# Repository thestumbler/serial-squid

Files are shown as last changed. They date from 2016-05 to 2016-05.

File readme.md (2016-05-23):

## Synopsis

The Serial Squid is a serial communications hub, useful for the development and testing of embedded systems projects. It can be operated stand-alone or remotely. True to its namesake, the Serial Squid has eight arms, two tentacles, and a round body. The I/O ports are found on the appendages, and the user interface and other supporting circuitry is found on the head and main body.

More information about the project can be found on my blog and project pages.

* [thestumbler](http://thestumbler.github.io)
* [theserialsquid](http://thestumbler.github.io/serial-squid/)

## Project File Organization

#### Key Files of Interest

* Bill of Materials:  docs/squid-bom.ods / .xlsx
* Block Diagram: docs/squid-block-diag.odg / .pdf
* LPC1769 Pinout Chart:  docs/squid-pinouts.ods / .xlsx
* Mechanical Drawing: mech/pcb_squid.dwg
* Parts Datasheets: parts/
* KiCAD Schematics, PCB files: sch/

## Status

* BOM is 98% completed.  All parts can be procured from DigiKey.  One problem has been sourcing a SMT 2x3 shrouded box header.

* Schematics 98% completed.  A few minor changes to be made, have been postponed until preliminary routing of the board is completed.  I want to see how much free room is remaining before deciding on the final few schematic changes.

* PCB first draft parts placement completed.  Routing will start after one more pass over the placement.

## github TODO

Add OpenSCAD 3D source code, which gives an fairly realistic mock-up of the final assembly.  It all works, but I need to re-organize some modules.  For example, many non-header parts reside in the header module.  Also, I need to sort out how to make a fork of another project, since I built my OpenSCAD library of parts upon a pre-existing library.

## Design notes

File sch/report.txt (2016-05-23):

Info: Reading netlist file "/files/proj/squid/serial-squid/sch/squid.net".

Info: Using references to match components and footprints.

Info: Checking netlist component footprint "C1:/56F75D50/57000D03:Capacitors_SMD:C_0805_HandSoldering".

Adding new component "C1:/56F75D50/57000D03" footprint "Capacitors_SMD:C_0805_HandSoldering".

Changing component "C1:/56F75D50/57000D03" pin "1" net name from "" to "Net-(C1-Pad1)".

Changing component "C1:/56F75D50/57000D03" pin "2" net name from "" to "Net-(C1-Pad2)".

Info: Checking netlist component footprint "C2:/56F75D50/57000D0A:Capacitors_SMD:C_0805_HandSoldering".

Adding new component "C2:/56F75D50/57000D0A" footprint "Capacitors_SMD:C_0805_HandSoldering".

Changing component "C2:/56F75D50/57000D0A" pin "1" net name from "" to "Net-(C2-Pad1)".

Changing component "C2:/56F75D50/57000D0A" pin "2" net name from "" to "Net-(C2-Pad2)".

Info: Checking netlist component footprint "C3:/56F75D50/570015F4:Capacitors_SMD:C_0805_HandSoldering".

Adding new component "C3:/56F75D50/570015F4" footprint "Capacitors_SMD:C_0805_HandSoldering".

Changing component "C3:/56F75D50/570015F4" pin "1" net name from "" to "GND".

Changing component "C3:/56F75D50/570015F4" pin "2" net name from "" to "Net-(C3-Pad2)".

Info: Checking netlist component footprint "C4:/56F75D50/570015FB:Capacitors_SMD:C_0805_HandSoldering".

Adding new component "C4:/56F75D50/570015FB" footprint "Capacitors_SMD:C_0805_HandSoldering".

Changing component "C4:/56F75D50/570015FB" pin "1" net name from "" to "GND".

Changing component "C4:/56F75D50/570015FB" pin "2" net name from "" to "Net-(C4-Pad2)".

Info: Checking netlist component footprint "C5:/56FDE856/5700692F:Capacitors_SMD:C_0805_HandSoldering".

Adding new component "C5:/56FDE856/5700692F" footprint "Capacitors_SMD:C_0805_HandSoldering".

Changing component "C5:/56FDE856/5700692F" pin "1" net name from "" to "Net-(C5-Pad1)".

Changing component "C5:/56FDE856/5700692F" pin "2" net name from "" to "Net-(C5-Pad2)".

Info: Checking netlist component footprint "C6:/56FDE856/57006936:Capacitors_SMD:C_0805_HandSoldering".

Adding new component "C6:/56FDE856/57006936" footprint "Capacitors_SMD:C_0805_HandSoldering".

Changing component "C6:/56FDE856/57006936" pin "1" net name from "" to "Net-(C6-Pad1)".

Changing component "C6:/56FDE856/57006936" pin "2" net name from "" to "Net-(C6-Pad2)".

Info: Checking netlist component footprint "C7:/56FDE856/5718DB03:Capacitors_SMD:C_0805_HandSoldering".

Adding new component "C7:/56FDE856/5718DB03" footprint "Capacitors_SMD:C_0805_HandSoldering".

Changing component "C7:/56FDE856/5718DB03" pin "1" net name from "" to "Net-(C7-Pad1)".

Changing component "C7:/56FDE856/5718DB03" pin "2" net name from "" to "GND".

Info: Checking netlist component footprint "C8:/56FDE856/570062FE:Capacitors_SMD:C_0805_HandSoldering".

Adding new component "C8:/56FDE856/570062FE" footprint "Capacitors_SMD:C_0805_HandSoldering".

Changing component "C8:/56FDE856/570062FE" pin "1" net name from "" to "GND".

Changing component "C8:/56FDE856/570062FE" pin "2" net name from "" to "Net-(C8-Pad2)".

Info: Checking netlist component footprint "C9:/56FDE856/57006305:Capacitors_SMD:C_0805_HandSoldering".

Adding new component "C9:/56FDE856/57006305" footprint "Capacitors_SMD:C_0805_HandSoldering".

Changing component "C9:/56FDE856/57006305" pin "1" net name from "" to "GND".

Changing component "C9:/56FDE856/57006305" pin "2" net name from "" to "Net-(C9-Pad2)".

Info: Checking netlist component footprint "C10:/56F72C60/571BCD2E:Capacitors_SMD:C_0805_HandSoldering".

Adding new component "C10:/56F72C60/571BCD2E" footprint "Capacitors_SMD:C_0805_HandSoldering".

Changing component "C10:/56F72C60/571BCD2E" pin "1" net name from "" to "Net-(C10-Pad1)".

Changing component "C10:/56F72C60/571BCD2E" pin "2" net name from "" to "GND".

Info: Checking netlist component footprint "C11:/56F72C60/571BCE58:Capacitors_SMD:C_0805_HandSoldering".

Adding new component "C11:/56F72C60/571BCE58" footprint "Capacitors_SMD:C_0805_HandSoldering".

Changing component "C11:/56F72C60/571BCE58" pin "1" net name from "" to "Net-(C11-Pad1)".

Changing component "C11:/56F72C60/571BCE58" pin "2" net name from "" to "GND".

Info: Checking netlist component footprint "C12:/56F72C60/571BD55E:Capacitors_SMD:C_0805_HandSoldering".

Adding new component "C12:/56F72C60/571BD55E" footprint "Capacitors_SMD:C_0805_HandSoldering".

Changing component "C12:/56F72C60/571BD55E" pin "1" net name from "" to "Net-(C12-Pad1)".

Changing component "C12:/56F72C60/571BD55E" pin "2" net name from "" to "GND".

Info: Checking netlist component footprint "C13:/56F72C60/571BD503:Capacitors_SMD:C_0805_HandSoldering".

Adding new component "C13:/56F72C60/571BD503" footprint "Capacitors_SMD:C_0805_HandSoldering".

Changing component "C13:/56F72C60/571BD503" pin "1" net name from "" to "Net-(C13-Pad1)".

Changing component "C13:/56F72C60/571BD503" pin "2" net name from "" to "GND".

Info: Checking netlist component footprint "C14:/56F72E3F/572241B0:Capacitors_SMD:C_0805_HandSoldering".

Adding new component "C14:/56F72E3F/572241B0" footprint "Capacitors_SMD:C_0805_HandSoldering".

Changing component "C14:/56F72E3F/572241B0" pin "1" net name from "" to "GND".

Changing component "C14:/56F72E3F/572241B0" pin "2" net name from "" to "Net-(C14-Pad2)".

Info: Checking netlist component footprint "C15:/56F72E3F/56FFF748:Capacitors_SMD:C_0805_HandSoldering".

Adding new component "C15:/56F72E3F/56FFF748" footprint "Capacitors_SMD:C_0805_HandSoldering".

Changing component "C15:/56F72E3F/56FFF748" pin "1" net name from "" to "Net-(C15-Pad1)".

Changing component "C15:/56F72E3F/56FFF748" pin "2" net name from "" to "GND".

Info: Checking netlist component footprint "C16:/56F72E3F/56FFFB31:Capacitors_SMD:C_0805_HandSoldering".

Adding new component "C16:/56F72E3F/56FFFB31" footprint "Capacitors_SMD:C_0805_HandSoldering".

Changing component "C16:/56F72E3F/56FFFB31" pin "1" net name from "" to "Net-(C16-Pad1)".

Changing component "C16:/56F72E3F/56FFFB31" pin "2" net name from "" to "GND".

Info: Checking netlist component footprint "C17:/56F72E3F/56FFFBD1:Capacitors_SMD:C_0805_HandSoldering".

Adding new component "C17:/56F72E3F/56FFFBD1" footprint "Capacitors_SMD:C_0805_HandSoldering".

Changing component "C17:/56F72E3F/56FFFBD1" pin "1" net name from "" to "Net-(C17-Pad1)".

Changing component "C17:/56F72E3F/56FFFBD1" pin "2" net name from "" to "Net-(C17-Pad2)".

Info: Checking netlist component footprint "C18:/56F72E3F/56FFFFD9:Capacitors_SMD:C_0805_HandSoldering".

Adding new component "C18:/56F72E3F/56FFFFD9" footprint "Capacitors_SMD:C_0805_HandSoldering".

Changing component "C18:/56F72E3F/56FFFFD9" pin "1" net name from "" to "Net-(C18-Pad1)".

Changing component "C18:/56F72E3F/56FFFFD9" pin "2" net name from "" to "Net-(C18-Pad2)".

Info: Checking netlist component footprint "C19:/571465DD/5714AEFB:Capacitors_SMD:C_0805_HandSoldering".

Adding new component "C19:/571465DD/5714AEFB" footprint "Capacitors_SMD:C_0805_HandSoldering".

Changing component "C19:/571465DD/5714AEFB" pin "1" net name from "" to "/COM0/~RESET".

Changing component "C19:/571465DD/5714AEFB" pin "2" net name from "" to "GND".

Info: Checking netlist component footprint "C20:/571465DD/5728B651:Capacitors_SMD:C_0805_HandSoldering".

Adding new component "C20:/571465DD/5728B651" footprint "Capacitors_SMD:C_0805_HandSoldering".

Changing component "C20:/571465DD/5728B651" pin "1" net name from "" to "/PIC-SQPROG/DISP_CONTR".

Changing component "C20:/571465DD/5728B651" pin "2" net name from "" to "GND".

Info: Checking netlist component footprint "C21:/57192609/57197EB6:Capacitors_SMD:C_0805_HandSoldering".

Adding new component "C21:/57192609/57197EB6" footprint "Capacitors_SMD:C_0805_HandSoldering".

Changing component "C21:/57192609/57197EB6" pin "1" net name from "" to "+5V".

Changing component "C21:/57192609/57197EB6" pin "2" net name from "" to "GND".

Info: Checking netlist component footprint "C22:/57192609/571988D2:Capacitors_Tantalum_SMD:TantalC_SizeB_EIA-3528_HandSoldering".

Adding new component "C22:/57192609/571988D2" footprint "Capacitors_Tantalum_SMD:TantalC_SizeB_EIA-3528_HandSoldering".

Changing component "C22:/57192609/571988D2" pin "2" net name from "" to "GND".

Changing component "C22:/57192609/571988D2" pin "1" net name from "" to "/CPU/USB_PWRD".

Info: Checking netlist component footprint "C23:/57192609/57173862:Capacitors_SMD:C_0805_HandSoldering".

Adding new component "C23:/57192609/57173862" footprint "Capacitors_SMD:C_0805_HandSoldering".

Changing component "C23:/57192609/57173862" pin "1" net name from "" to "+3V3".

Changing component "C23:/57192609/57173862" pin "2" net name from "" to "GND".

Info: Checking netlist component footprint "C24:/57192609/57173869:Capacitors_SMD:C_0805_HandSoldering".

Adding new component "C24:/57192609/57173869" footprint "Capacitors_SMD:C_0805_HandSoldering".

Changing component "C24:/57192609/57173869" pin "1" net name from "" to "+3V3".

Changing component "C24:/57192609/57173869" pin "2" net name from "" to "GND".

Info: Checking netlist component footprint "C25:/57192609/57173811:Capacitors_SMD:C_0805_HandSoldering".

Adding new component "C25:/57192609/57173811" footprint "Capacitors_SMD:C_0805_HandSoldering".

Changing component "C25:/57192609/57173811" pin "1" net name from "" to "Net-(C25-Pad1)".

Changing component "C25:/57192609/57173811" pin "2" net name from "" to "GND".

Info: Checking netlist component footprint "C26:/57192609/57173818:Capacitors_SMD:C_0805_HandSoldering".

Adding new component "C26:/57192609/57173818" footprint "Capacitors_SMD:C_0805_HandSoldering".

Changing component "C26:/57192609/57173818" pin "1" net name from "" to "Net-(C26-Pad1)".

Changing component "C26:/57192609/57173818" pin "2" net name from "" to "GND".

Info: Checking netlist component footprint "C27:/57161414/57165C09:Capacitors_SMD:C_0805_HandSoldering".

Adding new component "C27:/57161414/57165C09" footprint "Capacitors_SMD:C_0805_HandSoldering".

Changing component "C27:/57161414/57165C09" pin "1" net name from "" to "+5V".

Changing component "C27:/57161414/57165C09" pin "2" net name from "" to "GND".

Info: Checking netlist component footprint "C28:/57161414/57165C6D:Capacitors_Tantalum_SMD:TantalC_SizeB_EIA-3528_HandSoldering".

Adding new component "C28:/57161414/57165C6D" footprint "Capacitors_Tantalum_SMD:TantalC_SizeB_EIA-3528_HandSoldering".

Changing component "C28:/57161414/57165C6D" pin "2" net name from "" to "GND".

Changing component "C28:/57161414/57165C6D" pin "1" net name from "" to "+3V3".

Info: Checking netlist component footprint "C29:/56FDE856/57210437:Capacitors_SMD:C_0805_HandSoldering".

Adding new component "C29:/56FDE856/57210437" footprint "Capacitors_SMD:C_0805_HandSoldering".

Changing component "C29:/56FDE856/57210437" pin "1" net name from "" to "+5V".

Changing component "C29:/56FDE856/57210437" pin "2" net name from "" to "GND".

Info: Checking netlist component footprint "C30:/56FDE856/57210846:Capacitors_SMD:C_0805_HandSoldering".

Adding new component "C30:/56FDE856/57210846" footprint "Capacitors_SMD:C_0805_HandSoldering".

Changing component "C30:/56FDE856/57210846" pin "1" net name from "" to "GND".

Changing component "C30:/56FDE856/57210846" pin "2" net name from "" to "+5V".

Info: Checking netlist component footprint "C31:/56FDE856/57210F86:Capacitors_SMD:C_0805_HandSoldering".

Adding new component "C31:/56FDE856/57210F86" footprint "Capacitors_SMD:C_0805_HandSoldering".

Changing component "C31:/56FDE856/57210F86" pin "1" net name from "" to "GND".

Changing component "C31:/56FDE856/57210F86" pin "2" net name from "" to "+3V3".

Info: Checking netlist component footprint "C32:/56FF0341/57212123:Capacitors_SMD:C_0805_HandSoldering".

Adding new component "C32:/56FF0341/57212123" footprint "Capacitors_SMD:C_0805_HandSoldering".

Changing component "C32:/56FF0341/57212123" pin "1" net name from "" to "+5V".

Changing component "C32:/56FF0341/57212123" pin "2" net name from "" to "GND".

Info: Checking netlist component footprint "C33:/56FF0341/57212388:Capacitors_SMD:C_0805_HandSoldering".

Adding new component "C33:/56FF0341/57212388" footprint "Capacitors_SMD:C_0805_HandSoldering".

Changing component "C33:/56FF0341/57212388" pin "1" net name from "" to "+5V".

Changing component "C33:/56FF0341/57212388" pin "2" net name from "" to "GND".

Info: Checking netlist component footprint "C34:/56FF0341/57212470:Capacitors_SMD:C_0805_HandSoldering".

Adding new component "C34:/56FF0341/57212470" footprint "Capacitors_SMD:C_0805_HandSoldering".

Changing component "C34:/56FF0341/57212470" pin "1" net name from "" to "+5V".

Changing component "C34:/56FF0341/57212470" pin "2" net name from "" to "GND".

Info: Checking netlist component footprint "C35:/56FF0E05/5721A32F:Capacitors_SMD:C_0805_HandSoldering".

Adding new component "C35:/56FF0E05/5721A32F" footprint "Capacitors_SMD:C_0805_HandSoldering".

Changing component "C35:/56FF0E05/5721A32F" pin "1" net name from "" to "+5V".

Changing component "C35:/56FF0E05/5721A32F" pin "2" net name from "" to "GND".

Info: Checking netlist component footprint "C36:/56FF0E05/5721A366:Capacitors_SMD:C_0805_HandSoldering".

Adding new component "C36:/56FF0E05/5721A366" footprint "Capacitors_SMD:C_0805_HandSoldering".

Changing component "C36:/56FF0E05/5721A366" pin "1" net name from "" to "+5V".

Changing component "C36:/56FF0E05/5721A366" pin "2" net name from "" to "GND".

Info: Checking netlist component footprint "C37:/56FF0E05/5721A392:Capacitors_SMD:C_0805_HandSoldering".

Adding new component "C37:/56FF0E05/5721A392" footprint "Capacitors_SMD:C_0805_HandSoldering".

Changing component "C37:/56FF0E05/5721A392" pin "1" net name from "" to "+5V".

Changing component "C37:/56FF0E05/5721A392" pin "2" net name from "" to "GND".

Info: Checking netlist component footprint "C38:/56FF0E05/5721A3C7:Capacitors_SMD:C_0805_HandSoldering".

Adding new component "C38:/56FF0E05/5721A3C7" footprint "Capacitors_SMD:C_0805_HandSoldering".

Changing component "C38:/56FF0E05/5721A3C7" pin "1" net name from "" to "+5V".

Changing component "C38:/56FF0E05/5721A3C7" pin "2" net name from "" to "GND".

Info: Checking netlist component footprint "C39:/56F72C60/5721D036:Capacitors_SMD:C_0805_HandSoldering".

Adding new component "C39:/56F72C60/5721D036" footprint "Capacitors_SMD:C_0805_HandSoldering".

Changing component "C39:/56F72C60/5721D036" pin "1" net name from "" to "+3V3".

Changing component "C39:/56F72C60/5721D036" pin "2" net name from "" to "GND".

Info: Checking netlist component footprint "C40:/56F72C60/5721CD49:Capacitors_SMD:C_0805_HandSoldering".

Adding new component "C40:/56F72C60/5721CD49" footprint "Capacitors_SMD:C_0805_HandSoldering".

Changing component "C40:/56F72C60/5721CD49" pin "1" net name from "" to "+3V3".

Changing component "C40:/56F72C60/5721CD49" pin "2" net name from "" to "GND".

Info: Checking netlist component footprint "C41:/56F72C60/5721CE5A:Capacitors_SMD:C_0805_HandSoldering".

Adding new component "C41:/56F72C60/5721CE5A" footprint "Capacitors_SMD:C_0805_HandSoldering".

Changing component "C41:/56F72C60/5721CE5A" pin "1" net name from "" to "+3V3".

Changing component "C41:/56F72C60/5721CE5A" pin "2" net name from "" to "GND".

Info: Checking netlist component footprint "C42:/56F72C60/5721D002:Capacitors_SMD:C_0805_HandSoldering".

Adding new component "C42:/56F72C60/5721D002" footprint "Capacitors_SMD:C_0805_HandSoldering".

Changing component "C42:/56F72C60/5721D002" pin "1" net name from "" to "+3V3".

Changing component "C42:/56F72C60/5721D002" pin "2" net name from "" to "GND".

Info: Checking netlist component footprint "C43:/56F72C60/5721D008:Capacitors_SMD:C_0805_HandSoldering".

Adding new component "C43:/56F72C60/5721D008" footprint "Capacitors_SMD:C_0805_HandSoldering".

Changing component "C43:/56F72C60/5721D008" pin "1" net name from "" to "+3V3".

Changing component "C43:/56F72C60/5721D008" pin "2" net name from "" to "GND".

Info: Checking netlist component footprint "C44:/56F72C60/5721CEAA:Capacitors_SMD:C_0805_HandSoldering".

Adding new component "C44:/56F72C60/5721CEAA" footprint "Capacitors_SMD:C_0805_HandSoldering".

Changing component "C44:/56F72C60/5721CEAA" pin "1" net name from "" to "+3V3".

Changing component "C44:/56F72C60/5721CEAA" pin "2" net name from "" to "GND".

Info: Checking netlist component footprint "C45:/56F72C60/5721CEF7:Capacitors_SMD:C_0805_HandSoldering".

Adding new component "C45:/56F72C60/5721CEF7" footprint "Capacitors_SMD:C_0805_HandSoldering".

Changing component "C45:/56F72C60/5721CEF7" pin "1" net name from "" to "+3V3".

Changing component "C45:/56F72C60/5721CEF7" pin "2" net name from "" to "GND".

Info: Checking netlist component footprint "C46:/56F72E3F/572095A0:Capacitors_SMD:C_0805_HandSoldering".

Adding new component "C46:/56F72E3F/572095A0" footprint "Capacitors_SMD:C_0805_HandSoldering".

Changing component "C46:/56F72E3F/572095A0" pin "1" net name from "" to "GND".

Changing component "C46:/56F72E3F/572095A0" pin "2" net name from "" to "+3V3".

Info: Checking netlist component footprint "C47:/56F72E3F/5720B4DE:Capacitors_SMD:C_0805_HandSoldering".

Adding new component "C47:/56F72E3F/5720B4DE" footprint "Capacitors_SMD:C_0805_HandSoldering".

Changing component "C47:/56F72E3F/5720B4DE" pin "1" net name from "" to "+5V".

Changing component "C47:/56F72E3F/5720B4DE" pin "2" net name from "" to "GND".

Info: Checking netlist component footprint "C48:/56F72E3F/5720AC9D:Capacitors_SMD:C_0805_HandSoldering".

Adding new component "C48:/56F72E3F/5720AC9D" footprint "Capacitors_SMD:C_0805_HandSoldering".

Changing component "C48:/56F72E3F/5720AC9D" pin "1" net name from "" to "+3V3".

Changing component "C48:/56F72E3F/5720AC9D" pin "2" net name from "" to "GND".

Info: Checking netlist component footprint "C49:/56F72E3F/57209711:Capacitors_SMD:C_0805_HandSoldering".

Adding new component "C49:/56F72E3F/57209711" footprint "Capacitors_SMD:C_0805_HandSoldering".

Changing component "C49:/56F72E3F/57209711" pin "1" net name from "" to "+5V".

Changing component "C49:/56F72E3F/57209711" pin "2" net name from "" to "GND".

Info: Checking netlist component footprint "C50:/56F72E3F/5720BC9E:Capacitors_SMD:C_0805_HandSoldering".

Adding new component "C50:/56F72E3F/5720BC9E" footprint "Capacitors_SMD:C_0805_HandSoldering".

Changing component "C50:/56F72E3F/5720BC9E" pin "1" net name from "" to "+5V".

Changing component "C50:/56F72E3F/5720BC9E" pin "2" net name from "" to "GND".

Info: Checking netlist component footprint "C51:/5712FB0E/5721C098:Capacitors_SMD:C_0805_HandSoldering".

Adding new component "C51:/5712FB0E/5721C098" footprint "Capacitors_SMD:C_0805_HandSoldering".

Changing component "C51:/5712FB0E/5721C098" pin "1" net name from "" to "GND".

Changing component "C51:/5712FB0E/5721C098" pin "2" net name from "" to "+5V".

Info: Checking netlist component footprint "C52:/571465DD/5721B483:Capacitors_SMD:C_0805_HandSoldering".

Adding new component "C52:/571465DD/5721B483" footprint "Capacitors_SMD:C_0805_HandSoldering".

Changing component "C52:/571465DD/5721B483" pin "1" net name from "" to "+3V3".

Changing component "C52:/571465DD/5721B483" pin "2" net name from "" to "GND".

Info: Checking netlist component footprint "C53:/571465DD/5721B59B:Capacitors_SMD:C_0805_HandSoldering".

Adding new component "C53:/571465DD/5721B59B" footprint "Capacitors_SMD:C_0805_HandSoldering".

Changing component "C53:/571465DD/5721B59B" pin "1" net name from "" to "GND".

Changing component "C53:/571465DD/5721B59B" pin "2" net name from "" to "+3V3".

Info: Checking netlist component footprint "C54:/57192609/57217AD8:Capacitors_SMD:C_0805_HandSoldering".

Adding new component "C54:/57192609/57217AD8" footprint "Capacitors_SMD:C_0805_HandSoldering".

Changing component "C54:/57192609/57217AD8" pin "1" net name from "" to "+5V".

Changing component "C54:/57192609/57217AD8" pin "2" net name from "" to "GND".

Info: Checking netlist component footprint "C55:/57192609/57217F5F:Capacitors_SMD:C_0805_HandSoldering".

Adding new component "C55:/57192609/57217F5F" footprint "Capacitors_SMD:C_0805_HandSoldering".

Changing component "C55:/57192609/57217F5F" pin "1" net name from "" to "+3V3".

Changing component "C55:/57192609/57217F5F" pin "2" net name from "" to "GND".

Info: Checking netlist component footprint "C56:/57192609/57214563:Capacitors_SMD:C_0805_HandSoldering".

Adding new component "C56:/57192609/57214563" footprint "Capacitors_SMD:C_0805_HandSoldering".

Changing component "C56:/57192609/57214563" pin "1" net name from "" to "GND".

Changing component "C56:/57192609/57214563" pin "2" net name from "" to "+3V3".

Info: Checking netlist component footprint "C57:/57192609/57214490:Capacitors_SMD:C_0805_HandSoldering".

Adding new component "C57:/57192609/57214490" footprint "Capacitors_SMD:C_0805_HandSoldering".

Changing component "C57:/57192609/57214490" pin "1" net name from "" to "GND".

Changing component "C57:/57192609/57214490" pin "2" net name from "" to "+3V3".

Info: Checking netlist component footprint "C58:/57192609/57214386:Capacitors_SMD:C_0805_HandSoldering".

Adding new component "C58:/57192609/57214386" footprint "Capacitors_SMD:C_0805_HandSoldering".

Changing component "C58:/57192609/57214386" pin "1" net name from "" to "+3V3".

Changing component "C58:/57192609/57214386" pin "2" net name from "" to "GND".

Info: Checking netlist component footprint "C59:/57192609/57216182:Capacitors_Tantalum_SMD:TantalC_SizeB_EIA-3528_HandSoldering".

Adding new component "C59:/57192609/57216182" footprint "Capacitors_Tantalum_SMD:TantalC_SizeB_EIA-3528_HandSoldering".

Changing component "C59:/57192609/57216182" pin "2" net name from "" to "GND".

Changing component "C59:/57192609/57216182" pin "1" net name from "" to "+3V3".

Info: Checking netlist component footprint "C60:/57161414/57218DED:Capacitors_SMD:C_0805_HandSoldering".

Adding new component "C60:/57161414/57218DED" footprint "Capacitors_SMD:C_0805_HandSoldering".

Changing component "C60:/57161414/57218DED" pin "1" net name from "" to "+3V3".

Changing component "C60:/57161414/57218DED" pin "2" net name from "" to "GND".

Info: Checking netlist component footprint "C61:/57161414/57218E9D:Capacitors_SMD:C_0805_HandSoldering".

Adding new component "C61:/57161414/57218E9D" footprint "Capacitors_SMD:C_0805_HandSoldering".

Changing component "C61:/57161414/57218E9D" pin "1" net name from "" to "+3V3".

Changing component "C61:/57161414/57218E9D" pin "2" net name from "" to "GND".

Info: Checking netlist component footprint "C62:/57161414/572197D1:Capacitors_SMD:C_0805_HandSoldering".

Adding new component "C62:/57161414/572197D1" footprint "Capacitors_SMD:C_0805_HandSoldering".

Changing component "C62:/57161414/572197D1" pin "1" net name from "" to "+3V3".

Changing component "C62:/57161414/572197D1" pin "2" net name from "" to "GND".

Info: Checking netlist component footprint "C63:/57161414/572190C5:Capacitors_SMD:C_0805_HandSoldering".

Adding new component "C63:/57161414/572190C5" footprint "Capacitors_SMD:C_0805_HandSoldering".

Changing component "C63:/57161414/572190C5" pin "1" net name from "" to "+3V3".

Changing component "C63:/57161414/572190C5" pin "2" net name from "" to "GND".

Info: Checking netlist component footprint "C64:/56F75D50/5720CD6F:Capacitors_SMD:C_0805_HandSoldering".

Adding new component "C64:/56F75D50/5720CD6F" footprint "Capacitors_SMD:C_0805_HandSoldering".

Changing component "C64:/56F75D50/5720CD6F" pin "1" net name from "" to "+5V".

Changing component "C64:/56F75D50/5720CD6F" pin "2" net name from "" to "GND".

Info: Checking netlist component footprint "C65:/56F75D50/5720D5A9:Capacitors_SMD:C_0805_HandSoldering".

Adding new component "C65:/56F75D50/5720D5A9" footprint "Capacitors_SMD:C_0805_HandSoldering".

Changing component "C65:/56F75D50/5720D5A9" pin "1" net name from "" to "+5V".

Changing component "C65:/56F75D50/5720D5A9" pin "2" net name from "" to "GND".

Info: Checking netlist component footprint "C66:/56F75D50/5720D78D:Capacitors_SMD:C_0805_HandSoldering".

Adding new component "C66:/56F75D50/5720D78D" footprint "Capacitors_SMD:C_0805_HandSoldering".

Changing component "C66:/56F75D50/5720D78D" pin "1" net name from "" to "+5V".

Changing component "C66:/56F75D50/5720D78D" pin "2" net name from "" to "GND".

Info: Checking netlist component footprint "C67:/56F75D50/5720DC86:Capacitors_SMD:C_0805_HandSoldering".

Adding new component "C67:/56F75D50/5720DC86" footprint "Capacitors_SMD:C_0805_HandSoldering".

Changing component "C67:/56F75D50/5720DC86" pin "1" net name from "" to "+5V".

Changing component "C67:/56F75D50/5720DC86" pin "2" net name from "" to "GND".

Info: Checking netlist component footprint "C68:/56F75D50/5720E242:Capacitors_SMD:C_0805_HandSoldering".

Adding new component "C68:/56F75D50/5720E242" footprint "Capacitors_SMD:C_0805_HandSoldering".

Changing component "C68:/56F75D50/5720E242" pin "1" net name from "" to "+5V".

Changing component "C68:/56F75D50/5720E242" pin "2" net name from "" to "GND".

Info: Checking netlist component footprint "C69:/56F75D50/5720F5D6:Capacitors_SMD:C_0805_HandSoldering".

Adding new component "C69:/56F75D50/5720F5D6" footprint "Capacitors_SMD:C_0805_HandSoldering".

Changing component "C69:/56F75D50/5720F5D6" pin "1" net name from "" to "GND".

Changing component "C69:/56F75D50/5720F5D6" pin "2" net name from "" to "+3V3".

Info: Checking netlist component footprint "D1:/56F75D50/571D7237:Resistors_SMD:R_0805_HandSoldering".

Adding new component "D1:/56F75D50/571D7237" footprint "Resistors_SMD:R_0805_HandSoldering".

Changing component "D1:/56F75D50/571D7237" pin "1" net name from "" to "Net-(D1-Pad1)".

Changing component "D1:/56F75D50/571D7237" pin "2" net name from "" to "+5V".

Info: Checking netlist component footprint "D2:/56F75D50/571D724E:Resistors_SMD:R_0805_HandSoldering".

Adding new component "D2:/56F75D50/571D724E" footprint "Resistors_SMD:R_0805_HandSoldering".

Changing component "D2:/56F75D50/571D724E" pin "1" net name from "" to "Net-(D2-Pad1)".

Changing component "D2:/56F75D50/571D724E" pin "2" net name from "" to "+3V3".

Info: Checking netlist component footprint "D3:/56F75D50/571BE395:Resistors_SMD:R_0805_HandSoldering".

Adding new component "D3:/56F75D50/571BE395" footprint "Resistors_SMD:R_0805_HandSoldering".

Changing component "D3:/56F75D50/571BE395" pin "1" net name from "" to "GND".

Changing component "D3:/56F75D50/571BE395" pin "2" net name from "" to "Net-(D3-Pad2)".

Info: Checking netlist component footprint "D4:/56F75D50/571BCE1E:Resistors_SMD:R_0805_HandSoldering".

Adding new component "D4:/56F75D50/571BCE1E" footprint "Resistors_SMD:R_0805_HandSoldering".

Changing component "D4:/56F75D50/571BCE1E" pin "1" net name from "" to "GND".

Changing component "D4:/56F75D50/571BCE1E" pin "2" net name from "" to "Net-(D4-Pad2)".

Info: Checking netlist component footprint "D5:/56F75D50/571C2958:Resistors_SMD:R_0805_HandSoldering".

Adding new component "D5:/56F75D50/571C2958" footprint "Resistors_SMD:R_0805_HandSoldering".

Changing component "D5:/56F75D50/571C2958" pin "1" net name from "" to "GND".

Changing component "D5:/56F75D50/571C2958" pin "2" net name from "" to "Net-(D5-Pad2)".

Info: Checking netlist component footprint "D6:/56FDE856/571D23F6:Resistors_SMD:R_0805_HandSoldering".

Adding new component "D6:/56FDE856/571D23F6" footprint "Resistors_SMD:R_0805_HandSoldering".

Changing component "D6:/56FDE856/571D23F6" pin "1" net name from "" to "Net-(D6-Pad1)".

Changing component "D6:/56FDE856/571D23F6" pin "2" net name from "" to "+5V".

Info: Checking netlist component footprint "D7:/56FDE856/571D24A9:Resistors_SMD:R_0805_HandSoldering".

Adding new component "D7:/56FDE856/571D24A9" footprint "Resistors_SMD:R_0805_HandSoldering".

Changing component "D7:/56FDE856/571D24A9" pin "1" net name from "" to "Net-(D7-Pad1)".

Changing component "D7:/56FDE856/571D24A9" pin "2" net name from "" to "+3V3".

Info: Checking netlist component footprint "D8:/56FDE856/571CBE6D:Resistors_SMD:R_0805_HandSoldering".

Adding new component "D8:/56FDE856/571CBE6D" footprint "Resistors_SMD:R_0805_HandSoldering".

Changing component "D8:/56FDE856/571CBE6D" pin "1" net name from "" to "GND".

Changing component "D8:/56FDE856/571CBE6D" pin "2" net name from "" to "Net-(D8-Pad2)".

Info: Checking netlist component footprint "D9:/56FF0341/57200FDD:Resistors_SMD:R_0805_HandSoldering".

Adding new component "D9:/56FF0341/57200FDD" footprint "Resistors_SMD:R_0805_HandSoldering".

Changing component "D9:/56FF0341/57200FDD" pin "1" net name from "" to "GND".

Changing component "D9:/56FF0341/57200FDD" pin "2" net name from "" to "Net-(D9-Pad2)".

Info: Checking netlist component footprint "D10:/56FF0341/571F26BF:Resistors_SMD:R_0805_HandSoldering".

Adding new component "D10:/56FF0341/571F26BF" footprint "Resistors_SMD:R_0805_HandSoldering".

Changing component "D10:/56FF0341/571F26BF" pin "1" net name from "" to "Net-(D10-Pad1)".

Changing component "D10:/56FF0341/571F26BF" pin "2" net name from "" to "+5V".

Info: Checking netlist component footprint "D11:/56FF0341/571F26D3:Resistors_SMD:R_0805_HandSoldering".

Adding new component "D11:/56FF0341/571F26D3" footprint "Resistors_SMD:R_0805_HandSoldering".

Changing component "D11:/56FF0341/571F26D3" pin "1" net name from "" to "Net-(D11-Pad1)".

Changing component "D11:/56FF0341/571F26D3" pin "2" net name from "" to "+3V3".

Info: Checking netlist component footprint "D12:/56FF0341/571F3167:Resistors_SMD:R_0805_HandSoldering".

Adding new component "D12:/56FF0341/571F3167" footprint "Resistors_SMD:R_0805_HandSoldering".

Changing component "D12:/56FF0341/571F3167" pin "1" net name from "" to "Net-(D12-Pad1)".

Changing component "D12:/56FF0341/571F3167" pin "2" net name from "" to "+5V".

Info: Checking netlist component footprint "D13:/56FF0341/571F317B:Resistors_SMD:R_0805_HandSoldering".

Adding new component "D13:/56FF0341/571F317B" footprint "Resistors_SMD:R_0805_HandSoldering".

Changing component "D13:/56FF0341/571F317B" pin "1" net name from "" to "Net-(D13-Pad1)".

Changing component "D13:/56FF0341/571F317B" pin "2" net name from "" to "+3V3".

Info: Checking netlist component footprint "D14:/56FF0341/571E0EA0:Resistors_SMD:R_0805_HandSoldering".

Adding new component "D14:/56FF0341/571E0EA0" footprint "Resistors_SMD:R_0805_HandSoldering".

Changing component "D14:/56FF0341/571E0EA0" pin "1" net name from "" to "Net-(D14-Pad1)".

Changing component "D14:/56FF0341/571E0EA0" pin "2" net name from "" to "+5V".

Info: Checking netlist component footprint "D15:/56FF0341/571E0EB7:Resistors_SMD:R_0805_HandSoldering".

Adding new component "D15:/56FF0341/571E0EB7" footprint "Resistors_SMD:R_0805_HandSoldering".

Changing component "D15:/56FF0341/571E0EB7" pin "1" net name from "" to "Net-(D15-Pad1)".

Changing component "D15:/56FF0341/571E0EB7" pin "2" net name from "" to "+3V3".

Info: Checking netlist component footprint "D16:/56FF0341/571E5DA8:Resistors_SMD:R_0805_HandSoldering".

Adding new component "D16:/56FF0341/571E5DA8" footprint "Resistors_SMD:R_0805_HandSoldering".

Changing component "D16:/56FF0341/571E5DA8" pin "1" net name from "" to "GND".

Changing component "D16:/56FF0341/571E5DA8" pin "2" net name from "" to "Net-(D16-Pad2)".

Info: Checking netlist component footprint "D17:/56FF0341/571E59EC:Resistors_SMD:R_0805_HandSoldering".

Adding new component "D17:/56FF0341/571E59EC" footprint "Resistors_SMD:R_0805_HandSoldering".

Changing component "D17:/56FF0341/571E59EC" pin "1" net name from "" to "GND".

Changing component "D17:/56FF0341/571E59EC" pin "2" net name from "" to "Net-(D17-Pad2)".

Info: Checking netlist component footprint "D18:/56F72E3F/5722C710:Resistors_SMD:R_0805_HandSoldering".

Adding new component "D18:/56F72E3F/5722C710" footprint "Resistors_SMD:R_0805_HandSoldering".

Changing component "D18:/56F72E3F/5722C710" pin "1" net name from "" to "GND".

Changing component "D18:/56F72E3F/5722C710" pin "2" net name from "" to "Net-(D18-Pad2)".

Info: Checking netlist component footprint "D19:/56F72E3F/5723CEBE:Resistors_SMD:R_0805_HandSoldering".

Adding new component "D19:/56F72E3F/5723CEBE" footprint "Resistors_SMD:R_0805_HandSoldering".

Changing component "D19:/56F72E3F/5723CEBE" pin "1" net name from "" to "GND".

Changing component "D19:/56F72E3F/5723CEBE" pin "2" net name from "" to "Net-(D19-Pad2)".

Info: Checking netlist component footprint "D20:/56F72E3F/57227845:Resistors_SMD:R_0805_HandSoldering".

Adding new component "D20:/56F72E3F/57227845" footprint "Resistors_SMD:R_0805_HandSoldering".

Changing component "D20:/56F72E3F/57227845" pin "1" net name from "" to "GND".

Changing component "D20:/56F72E3F/57227845" pin "2" net name from "" to "Net-(D20-Pad2)".

Info: Checking netlist component footprint "D21:/5712FB0E/5713067B:Diodes_SMD:SOD-123".

Adding new component "D21:/5712FB0E/5713067B" footprint "Diodes_SMD:SOD-123".

Changing component "D21:/5712FB0E/5713067B" pin "1" net name from "" to "/CPU/PBCOL_SEN3".

Changing component "D21:/5712FB0E/5713067B" pin "2" net name from "" to "Net-(D21-Pad2)".

Info: Checking netlist component footprint "D22:/5712FB0E/57130D93:Diodes_SMD:SOD-123".

Adding new component "D22:/5712FB0E/57130D93" footprint "Diodes_SMD:SOD-123".

Changing component "D22:/5712FB0E/57130D93" pin "1" net name from "" to "/CPU/PBCOL_SEN2".

Changing component "D22:/5712FB0E/57130D93" pin "2" net name from "" to "Net-(D22-Pad2)".

Info: Checking netlist component footprint "D23:/5712FB0E/571308E6:Diodes_SMD:SOD-123".

Adding new component "D23:/5712FB0E/571308E6" footprint "Diodes_SMD:SOD-123".

Changing component "D23:/5712FB0E/571308E6" pin "1" net name from "" to "/CPU/PBCOL_SEN2".

Changing component "D23:/5712FB0E/571308E6" pin "2" net name from "" to "Net-(D23-Pad2)".

Info: Checking netlist component footprint "D24:/5712FB0E/57130D9F:Diodes_SMD:SOD-123".

Adding new component "D24:/5712FB0E/57130D9F" footprint "Diodes_SMD:SOD-123".

Changing component "D24:/5712FB0E/57130D9F" pin "1" net name from "" to "/CPU/PBCOL_SEN1".

Changing component "D24:/5712FB0E/57130D9F" pin "2" net name from "" to "Net-(D24-Pad2)".

Info: Checking netlist component footprint "D25:/5712FB0E/571309DA:Diodes_SMD:SOD-123".

Adding new component "D25:/5712FB0E/571309DA" footprint "Diodes_SMD:SOD-123".

Changing component "D25:/5712FB0E/571309DA" pin "1" net name from "" to "/CPU/PBCOL_SEN1".

Changing component "D25:/5712FB0E/571309DA" pin "2" net name from "" to "Net-(D25-Pad2)".

Info: Checking netlist component footprint "D26:/5712FB0E/57130DAB:Diodes_SMD:SOD-123".

Adding new component "D26:/5712FB0E/57130DAB" footprint "Diodes_SMD:SOD-123".

Changing component "D26:/5712FB0E/57130DAB" pin "1" net name from "" to "/CPU/PBCOL_SEN0".

Changing component "D26:/5712FB0E/57130DAB" pin "2" net name from "" to "Net-(D26-Pad2)".

Info: Checking netlist component footprint "D27:/5712FB0E/57130B9B:Diodes_SMD:SOD-123".

Adding new component "D27:/5712FB0E/57130B9B" footprint "Diodes_SMD:SOD-123".

Changing component "D27:/5712FB0E/57130B9B" pin "1" net name from "" to "/CPU/PBCOL_SEN0".

Changing component "D27:/5712FB0E/57130B9B" pin "2" net name from "" to "Net-(D27-Pad2)".

Info: Checking netlist component footprint "D28:/571465DD/5714C76E:TO_SOT_Packages_SMD:SOT-23_Handsoldering".

Adding new component "D28:/571465DD/5714C76E" footprint "TO_SOT_Packages_SMD:SOT-23_Handsoldering".

Changing component "D28:/571465DD/5714C76E" pin "1" net name from "" to "/COM0/~RESET".

Changing component "D28:/571465DD/5714C76E" pin "2" net name from "" to "/PIC-SQPROG/ICSP_MCLR".

Info: Checking netlist component footprint "D29:/571465DD/5714B3BD:TO_SOT_Packages_SMD:SOT-23_Handsoldering".

Adding new component "D29:/571465DD/5714B3BD" footprint "TO_SOT_Packages_SMD:SOT-23_Handsoldering".

Changing component "D29:/571465DD/5714B3BD" pin "1" net name from "" to "Net-(D29-Pad1)".

Changing component "D29:/571465DD/5714B3BD" pin "2" net name from "" to "+3V3".

Info: Checking netlist component footprint "D30:/57192609/57202738:Resistors_SMD:R_0805_HandSoldering".

Adding new component "D30:/57192609/57202738" footprint "Resistors_SMD:R_0805_HandSoldering".

Changing component "D30:/57192609/57202738" pin "1" net name from "" to "GND".

Changing component "D30:/57192609/57202738" pin "2" net name from "" to "Net-(D30-Pad2)".

Info: Checking netlist component footprint "D31:/57192609/57202A40:Resistors_SMD:R_0805_HandSoldering".

Adding new component "D31:/57192609/57202A40" footprint "Resistors_SMD:R_0805_HandSoldering".

Changing component "D31:/57192609/57202A40" pin "1" net name from "" to "GND".

Changing component "D31:/57192609/57202A40" pin "2" net name from "" to "Net-(D31-Pad2)".

Info: Checking netlist component footprint "D32:/57192609/571A3D43:Resistors_SMD:R_0805_HandSoldering".

Adding new component "D32:/57192609/571A3D43" footprint "Resistors_SMD:R_0805_HandSoldering".

Changing component "D32:/57192609/571A3D43" pin "1" net name from "" to "Net-(D32-Pad1)".

Changing component "D32:/57192609/571A3D43" pin "2" net name from "" to "/CPU/USB_PWRD".

Info: Checking netlist component footprint "D33:/57192609/571A2BBD:Resistors_SMD:R_0805_HandSoldering".

Adding new component "D33:/57192609/571A2BBD" footprint "Resistors_SMD:R_0805_HandSoldering".

Changing component "D33:/57192609/571A2BBD" pin "1" net name from "" to "Net-(D33-Pad1)".

Changing component "D33:/57192609/571A2BBD" pin "2" net name from "" to "Net-(D33-Pad2)".

Info: Checking netlist component footprint "D34:/56FDE856/57234F4C:Resistors_SMD:R_0805_HandSoldering".

Adding new component "D34:/56FDE856/57234F4C" footprint "Resistors_SMD:R_0805_HandSoldering".

Changing component "D34:/56FDE856/57234F4C" pin "1" net name from "" to "Net-(D34-Pad1)".

Changing component "D34:/56FDE856/57234F4C" pin "2" net name from "" to "+5V".

Info: Checking netlist component footprint "D35:/56FDE856/5722F2C5:Resistors_SMD:R_0805_HandSoldering".

Adding new component "D35:/56FDE856/5722F2C5" footprint "Resistors_SMD:R_0805_HandSoldering".

Changing component "D35:/56FDE856/5722F2C5" pin "1" net name from "" to "GND".

Changing component "D35:/56FDE856/5722F2C5" pin "2" net name from "" to "Net-(D35-Pad2)".

Info: Checking netlist component footprint "D36:/57192609/5724B94C:Resistors_SMD:R_0805_HandSoldering".

Adding new component "D36:/57192609/5724B94C" footprint "Resistors_SMD:R_0805_HandSoldering".

Changing component "D36:/57192609/5724B94C" pin "1" net name from "" to "GND".

Changing component "D36:/57192609/5724B94C" pin "2" net name from "" to "Net-(D36-Pad2)".

Info: Checking netlist component footprint "DS1:/5712FB0E/57137341:my-display:NHD-0420AZ".

Adding new component "DS1:/5712FB0E/57137341" footprint "my-display:NHD-0420AZ".

Changing component "DS1:/5712FB0E/57137341" pin "1" net name from "" to "GND".

Changing component "DS1:/5712FB0E/57137341" pin "2" net name from "" to "+5V".

Changing component "DS1:/5712FB0E/57137341" pin "3" net name from "" to "/PIC-SQPROG/DISP_CONTR".

Changing component "DS1:/5712FB0E/57137341" pin "4" net name from "" to "/CPU/DISP_REGSEL".

Changing component "DS1:/5712FB0E/57137341" pin "5" net name from "" to "/CPU/DISP_RW".

Changing component "DS1:/5712FB0E/57137341" pin "6" net name from "" to "/CPU/DISP_OP_ENA".

Changing component "DS1:/5712FB0E/57137341" pin "7" net name from "" to "Net-(DS1-Pad7)".

Changing component "DS1:/5712FB0E/57137341" pin "8" net name from "" to "Net-(DS1-Pad8)".

Changing component "DS1:/5712FB0E/57137341" pin "9" net name from "" to "Net-(DS1-Pad9)".

Changing component "DS1:/5712FB0E/57137341" pin "10" net name from "" to "Net-(DS1-Pad10)".

Changing component "DS1:/5712FB0E/57137341" pin "11" net name from "" to "/CPU/DISP_DB0".

Changing component "DS1:/5712FB0E/57137341" pin "12" net name from "" to "/CPU/DISP_DB1".

Changing component "DS1:/5712FB0E/57137341" pin "13" net name from "" to "/CPU/DISP_DB2".

Changing component "DS1:/5712FB0E/57137341" pin "14" net name from "" to "/CPU/DISP_DB3".

Changing component "DS1:/5712FB0E/57137341" pin "15" net name from "" to "+5V".

Changing component "DS1:/5712FB0E/57137341" pin "16" net name from "" to "/PIC-SQPROG/DISP_BACKL".

Info: Checking netlist component footprint "J1:/56F75D50/571F59D7:my-connect:PHDR-RA-SMT-1x10".

Adding new component "J1:/56F75D50/571F59D7" footprint "my-connect:PHDR-RA-SMT-1x10".

Changing component "J1:/56F75D50/571F59D7" pin "1" net name from "" to "Net-(J1-Pad1)".

Changing component "J1:/56F75D50/571F59D7" pin "2" net name from "" to "/COM1/COM1C_RTSL".

Changing component "J1:/56F75D50/571F59D7" pin "3" net name from "" to "/COM1/COM1C_DTR".

Changing component "J1:/56F75D50/571F59D7" pin "4" net name from "" to "/COM1/COM1C_TXD".

Changing component "J1:/56F75D50/571F59D7" pin "5" net name from "" to "GND".

Changing component "J1:/56F75D50/571F59D7" pin "6" net name from "" to "GND".

Changing component "J1:/56F75D50/571F59D7" pin "7" net name from "" to "/COM1/COM1C_RXDL".

Changing component "J1:/56F75D50/571F59D7" pin "8" net name from "" to "/COM1/COM1C_DSR".

Changing component "J1:/56F75D50/571F59D7" pin "9" net name from "" to "/COM1/COM1C_CTSL".

Changing component "J1:/56F75D50/571F59D7" pin "10" net name from "" to "Net-(J1-Pad1)".

Info: Checking netlist component footprint "J2:/56F75D50/572DB935:my-connect:term-block-5".

Adding new component "J2:/56F75D50/572DB935" footprint "my-connect:term-block-5".

Changing component "J2:/56F75D50/572DB935" pin "2" net name from "" to "/COM1/TXB".

Changing component "J2:/56F75D50/572DB935" pin "1" net name from "" to "/COM1/TXA".

Changing component "J2:/56F75D50/572DB935" pin "3" net name from "" to "/COM1/RXA".

Changing component "J2:/56F75D50/572DB935" pin "4" net name from "" to "/COM1/RXB".

Changing component "J2:/56F75D50/572DB935" pin "5" net name from "" to "GND".

Info: Checking netlist component footprint "J3:/56F75D50/56FF00F4:my-connect:SHDR-SMT-2x5".

Adding new component "J3:/56F75D50/56FF00F4" footprint "my-connect:SHDR-SMT-2x5".

Changing component "J3:/56F75D50/56FF00F4" pin "1" net name from "" to "Net-(J3-Pad1)".

Changing component "J3:/56F75D50/56FF00F4" pin "2" net name from "" to "Net-(J3-Pad2)".

Changing component "J3:/56F75D50/56FF00F4" pin "3" net name from "" to "Net-(J3-Pad3)".

Changing component "J3:/56F75D50/56FF00F4" pin "4" net name from "" to "Net-(J3-Pad4)".

Changing component "J3:/56F75D50/56FF00F4" pin "5" net name from "" to "Net-(J3-Pad5)".

Changing component "J3:/56F75D50/56FF00F4" pin "6" net name from "" to "Net-(J3-Pad6)".

Changing component "J3:/56F75D50/56FF00F4" pin "7" net name from "" to "Net-(J3-Pad7)".

Changing component "J3:/56F75D50/56FF00F4" pin "8" net name from "" to "Net-(J3-Pad8)".

Changing component "J3:/56F75D50/56FF00F4" pin "9" net name from "" to "GND".

Changing component "J3:/56F75D50/56FF00F4" pin "10" net name from "" to "Net-(J3-Pad10)".

Info: Checking netlist component footprint "J4:/56FDE856/56F7605C:my-connect:SHDR-SMT-2x5".

Adding new component "J4:/56FDE856/56F7605C" footprint "my-connect:SHDR-SMT-2x5".

Changing component "J4:/56FDE856/56F7605C" pin "1" net name from "" to "Net-(J4-Pad1)".

Changing component "J4:/56FDE856/56F7605C" pin "2" net name from "" to "Net-(J4-Pad2)".

Changing component "J4:/56FDE856/56F7605C" pin "3" net name from "" to "Net-(J4-Pad3)".

Changing component "J4:/56FDE856/56F7605C" pin "4" net name from "" to "Net-(J4-Pad4)".

Changing component "J4:/56FDE856/56F7605C" pin "5" net name from "" to "Net-(J4-Pad5)".

Changing component "J4:/56FDE856/56F7605C" pin "6" net name from "" to "Net-(J4-Pad6)".

Changing component "J4:/56FDE856/56F7605C" pin "7" net name from "" to "Net-(J4-Pad7)".

Changing component "J4:/56FDE856/56F7605C" pin "8" net name from "" to "Net-(J4-Pad8)".

Changing component "J4:/56FDE856/56F7605C" pin "9" net name from "" to "GND".

Changing component "J4:/56FDE856/56F7605C" pin "10" net name from "" to "Net-(J4-Pad10)".

Info: Checking netlist component footprint "J5:/56FDE856/571F6C83:my-connect:PHDR-RA-SMT-1x10".

Adding new component "J5:/56FDE856/571F6C83" footprint "my-connect:PHDR-RA-SMT-1x10".

Changing component "J5:/56FDE856/571F6C83" pin "1" net name from "" to "Net-(J5-Pad1)".

Changing component "J5:/56FDE856/571F6C83" pin "2" net name from "" to "/COM2-CAN/COM2B_RTSL".

Changing component "J5:/56FDE856/571F6C83" pin "3" net name from "" to "Net-(J5-Pad3)".

Changing component "J5:/56FDE856/571F6C83" pin "4" net name from "" to "/COM2-CAN/COM2B_TXD".

Changing component "J5:/56FDE856/571F6C83" pin "5" net name from "" to "GND".

Changing component "J5:/56FDE856/571F6C83" pin "6" net name from "" to "GND".

Changing component "J5:/56FDE856/571F6C83" pin "7" net name from "" to "/COM2-CAN/COM2B_RXDL".

Changing component "J5:/56FDE856/571F6C83" pin "8" net name from "" to "Net-(J5-Pad8)".

Changing component "J5:/56FDE856/571F6C83" pin "9" net name from "" to "/COM2-CAN/COM2B_CTSL".

Changing component "J5:/56FDE856/571F6C83" pin "10" net name from "" to "Net-(J5-Pad1)".

Info: Checking netlist component footprint "J6:/56FDE856/5718DB36:my-connect:SHDR-SMT-2x5".

Adding new component "J6:/56FDE856/5718DB36" footprint "my-connect:SHDR-SMT-2x5".

Changing component "J6:/56FDE856/5718DB36" pin "1" net name from "" to "Net-(J6-Pad1)".

Changing component "J6:/56FDE856/5718DB36" pin "2" net name from "" to "Net-(J25-Pad4)".

Changing component "J6:/56FDE856/5718DB36" pin "3" net name from "" to "Net-(J25-Pad3)".

Changing component "J6:/56FDE856/5718DB36" pin "4" net name from "" to "Net-(J25-Pad2)".

Changing component "J6:/56FDE856/5718DB36" pin "5" net name from "" to "Net-(J25-Pad4)".

Changing component "J6:/56FDE856/5718DB36" pin "6" net name from "" to "Net-(J6-Pad6)".

Changing component "J6:/56FDE856/5718DB36" pin "7" net name from "" to "Net-(J6-Pad7)".

Changing component "J6:/56FDE856/5718DB36" pin "8" net name from "" to "+5V".

Changing component "J6:/56FDE856/5718DB36" pin "9" net name from "" to "Net-(J25-Pad4)".

Changing component "J6:/56FDE856/5718DB36" pin "10" net name from "" to "Net-(J6-Pad10)".

Info: Checking netlist component footprint "J7:/56FF0341/571F9CAE:my-connect:SHDR-SMT-2x10".

Adding new component "J7:/56FF0341/571F9CAE" footprint "my-connect:SHDR-SMT-2x10".

Changing component "J7:/56FF0341/571F9CAE" pin "1" net name from "" to "Net-(J10-Pad1)".

Changing component "J7:/56FF0341/571F9CAE" pin "2" net name from "" to "Net-(J10-Pad1)".

Changing component "J7:/56FF0341/571F9CAE" pin "3" net name from "" to "/COM3, PROG/~TRST".

Changing component "J7:/56FF0341/571F9CAE" pin "4" net name from "" to "GND".

Changing component "J7:/56FF0341/571F9CAE" pin "5" net name from "" to "/COM3, PROG/TDI".

Changing component "J7:/56FF0341/571F9CAE" pin "6" net name from "" to "GND".

Changing component "J7:/56FF0341/571F9CAE" pin "7" net name from "" to "/COM3, PROG/TMS".

Changing component "J7:/56FF0341/571F9CAE" pin "8" net name from "" to "GND".

Changing component "J7:/56FF0341/571F9CAE" pin "9" net name from "" to "/COM3, PROG/TCK".

Changing component "J7:/56FF0341/571F9CAE" pin "10" net name from "" to "GND".

Changing component "J7:/56FF0341/571F9CAE" pin "11" net name from "" to "Net-(J7-Pad11)".

Changing component "J7:/56FF0341/571F9CAE" pin "12" net name from "" to "GND".

Changing component "J7:/56FF0341/571F9CAE" pin "13" net name from "" to "/COM3, PROG/TDO".

Changing component "J7:/56FF0341/571F9CAE" pin "14" net name from "" to "GND".

Changing component "J7:/56FF0341/571F9CAE" pin "15" net name from "" to "/COM3, PROG/~SRST".

Changing component "J7:/56FF0341/571F9CAE" pin "16" net name from "" to "GND".

Changing component "J7:/56FF0341/571F9CAE" pin "17" net name from "" to "Net-(J7-Pad17)".

Changing component "J7:/56FF0341/571F9CAE" pin "18" net name from "" to "GND".

Changing component "J7:/56FF0341/571F9CAE" pin "19" net name from "" to "Net-(J7-Pad19)".

Changing component "J7:/56FF0341/571F9CAE" pin "20" net name from "" to "GND".

Info: Checking netlist component footprint "J8:/56FF0341/56FF00F3:my-connect:SHDR-SMT-2x5".

Adding new component "J8:/56FF0341/56FF00F3" footprint "my-connect:SHDR-SMT-2x5".

Changing component "J8:/56FF0341/56FF00F3" pin "1" net name from "" to "Net-(J12-Pad2)".

Changing component "J8:/56FF0341/56FF00F3" pin "2" net name from "" to "GND".

Changing component "J8:/56FF0341/56FF00F3" pin "3" net name from "" to "/CPU/COM3_RXD".

Changing component "J8:/56FF0341/56FF00F3" pin "4" net name from "" to "/CPU/COM3_TXD".

Changing component "J8:/56FF0341/56FF00F3" pin "5" net name from "" to "/COM3, PROG/COM3_SCL".

Changing component "J8:/56FF0341/56FF00F3" pin "6" net name from "" to "/COM3, PROG/COM3_SDA".

Changing component "J8:/56FF0341/56FF00F3" pin "7" net name from "" to "/COM3, PROG/COM3_MISO".

Changing component "J8:/56FF0341/56FF00F3" pin "8" net name from "" to "/COM3, PROG/COM3_MOSI".

Changing component "J8:/56FF0341/56FF00F3" pin "9" net name from "" to "/COM3, PROG/COM3_SCLK".

Changing component "J8:/56FF0341/56FF00F3" pin "10" net name from "" to "/COM3, PROG/~COM3_SSEL".

Info: Checking netlist component footprint "J9:/56FF0341/571F7FCE:my-connect:PHDR-RA-SMT-1x6".

Adding new component "J9:/56FF0341/571F7FCE" footprint "my-connect:PHDR-RA-SMT-1x6".

Changing component "J9:/56FF0341/571F7FCE" pin "1" net name from "" to "/COM3, PROG/COM3_SCL".

Changing component "J9:/56FF0341/571F7FCE" pin "2" net name from "" to "/COM3, PROG/COM3_SDA".

Changing component "J9:/56FF0341/571F7FCE" pin "3" net name from "" to "Net-(J12-Pad2)".

Changing component "J9:/56FF0341/571F7FCE" pin "4" net name from "" to "GND".

Changing component "J9:/56FF0341/571F7FCE" pin "5" net name from "" to "/COM3, PROG/COM3_SCL".

Changing component "J9:/56FF0341/571F7FCE" pin "6" net name from "" to "/COM3, PROG/COM3_SDA".

Info: Checking netlist component footprint "J10:/56FF0341/571FA09E:my-connect:PHDR-RA-SMT-1x9".

Adding new component "J10:/56FF0341/571FA09E" footprint "my-connect:PHDR-RA-SMT-1x9".

Changing component "J10:/56FF0341/571FA09E" pin "1" net name from "" to "Net-(J10-Pad1)".

Changing component "J10:/56FF0341/571FA09E" pin "2" net name from "" to "GND".

Changing component "J10:/56FF0341/571FA09E" pin "3" net name from "" to "Net-(J10-Pad3)".

Changing component "J10:/56FF0341/571FA09E" pin "4" net name from "" to "/COM3, PROG/TCK".

Changing component "J10:/56FF0341/571FA09E" pin "5" net name from "" to "Net-(J10-Pad5)".

Changing component "J10:/56FF0341/571FA09E" pin "6" net name from "" to "/COM3, PROG/TDO".

Changing component "J10:/56FF0341/571FA09E" pin "7" net name from "" to "/COM3, PROG/TDI".

Changing component "J10:/56FF0341/571FA09E" pin "8" net name from "" to "Net-(J10-Pad8)".

Changing component "J10:/56FF0341/571FA09E" pin "9" net name from "" to "/COM3, PROG/TMS".

Info: Checking netlist component footprint "J11:/56FF0341/571FA508:my-connect:PHDR-RA-SMT-1x6".

Adding new component "J11:/56FF0341/571FA508" footprint "my-connect:PHDR-RA-SMT-1x6".

Changing component "J11:/56FF0341/571FA508" pin "1" net name from "" to "/COM3, PROG/ISP_VPP_~MCLR".

Changing component "J11:/56FF0341/571FA508" pin "2" net name from "" to "/COM3, PROG/ISP_VDD".

Changing component "J11:/56FF0341/571FA508" pin "3" net name from "" to "GND".

Changing component "J11:/56FF0341/571FA508" pin "4" net name from "" to "/COM3, PROG/ISP_MOSI".

Changing component "J11:/56FF0341/571FA508" pin "5" net name from "" to "/COM3, PROG/ISP_SCLK".

Changing component "J11:/56FF0341/571FA508" pin "6" net name from "" to "/COM3, PROG/ISP_AUX_NC".

Info: Checking netlist component footprint "J12:/56FF0341/56FF2231:my-connect:SHDR-SMT-2x3".

Adding new component "J12:/56FF0341/56FF2231" footprint "my-connect:SHDR-SMT-2x3".

Changing component "J12:/56FF0341/56FF2231" pin "1" net name from "" to "/COM3, PROG/COM3_MISO".

Changing component "J12:/56FF0341/56FF2231" pin "2" net name from "" to "Net-(J12-Pad2)".

Changing component "J12:/56FF0341/56FF2231" pin "3" net name from "" to "/COM3, PROG/COM3_SCLK".

Changing component "J12:/56FF0341/56FF2231" pin "4" net name from "" to "/COM3, PROG/COM3_MOSI".

Changing component "J12:/56FF0341/56FF2231" pin "5" net name from "" to "/COM3, PROG/~COM3_SSEL".

Changing component "J12:/56FF0341/56FF2231" pin "6" net name from "" to "GND".

Info: Checking netlist component footprint "J13:/56FF0341/57187E80:my-connect:SHDR-SMT-2x3".

Adding new component "J13:/56FF0341/57187E80" footprint "my-connect:SHDR-SMT-2x3".

Changing component "J13:/56FF0341/57187E80" pin "1" net name from "" to "/COM3, PROG/ISP_MISO".

Changing component "J13:/56FF0341/57187E80" pin "2" net name from "" to "/COM3, PROG/ISP_VDD".

Changing component "J13:/56FF0341/57187E80" pin "3" net name from "" to "/COM3, PROG/ISP_SCLK".

Changing component "J13:/56FF0341/57187E80" pin "4" net name from "" to "/COM3, PROG/ISP_MOSI".

Changing component "J13:/56FF0341/57187E80" pin "5" net name from "" to "/COM3, PROG/~ISP_SSEL".

Changing component "J13:/56FF0341/57187E80" pin "6" net name from "" to "GND".

Info: Checking netlist component footprint "J14:/56FF0341/571F7B1F:my-connect:PHDR-RA-SMT-1x4".

Adding new component "J14:/56FF0341/571F7B1F" footprint "my-connect:PHDR-RA-SMT-1x4".

Changing component "J14:/56FF0341/571F7B1F" pin "1" net name from "" to "/CPU/COM3_TXD".

Changing component "J14:/56FF0341/571F7B1F" pin "2" net name from "" to "GND".

Changing component "J14:/56FF0341/571F7B1F" pin "3" net name from "" to "GND".

Changing component "J14:/56FF0341/571F7B1F" pin "4" net name from "" to "/CPU/COM3_RXD".

Info: Checking netlist component footprint "J15:/56F72E3F/56F75219:my-connect:SHDR-SMT-2x5".

Adding new component "J15:/56F72E3F/56F75219" footprint "my-connect:SHDR-SMT-2x5".

Changing component "J15:/56F72E3F/56F75219" pin "1" net name from "" to "Net-(J15-Pad1)".

Changing component "J15:/56F72E3F/56F75219" pin "2" net name from "" to "/COM0/COM0B_DSR".

Changing component "J15:/56F72E3F/56F75219" pin "3" net name from "" to "/COM0/COM0B_RXD".

Changing component "J15:/56F72E3F/56F75219" pin "4" net name from "" to "/COM0/COM0B_RTS".

Changing component "J15:/56F72E3F/56F75219" pin "5" net name from "" to "/COM0/COM0B_TXD".

Changing component "J15:/56F72E3F/56F75219" pin "6" net name from "" to "/COM0/COM0B_CTS".

Changing component "J15:/56F72E3F/56F75219" pin "7" net name from "" to "/COM0/COM0B_DTR".

Changing component "J15:/56F72E3F/56F75219" pin "8" net name from "" to "Net-(J15-Pad8)".

Changing component "J15:/56F72E3F/56F75219" pin "9" net name from "" to "GND".

Changing component "J15:/56F72E3F/56F75219" pin "10" net name from "" to "Net-(J15-Pad10)".

Info: Checking netlist component footprint "J16:/56F72E3F/571F4AB4:my-connect:PHDR-RA-SMT-1x10".

Adding new component "J16:/56F72E3F/571F4AB4" footprint "my-connect:PHDR-RA-SMT-1x10".

Changing component "J16:/56F72E3F/571F4AB4" pin "1" net name from "" to "Net-(J16-Pad1)".

Changing component "J16:/56F72E3F/571F4AB4" pin "2" net name from "" to "/COM0/COM0C_RTSL".

Changing component "J16:/56F72E3F/571F4AB4" pin "3" net name from "" to "/COM0/COM0C_DTR".

Changing component "J16:/56F72E3F/571F4AB4" pin "4" net name from "" to "/COM0/COM0C_TXD".

Changing component "J16:/56F72E3F/571F4AB4" pin "5" net name from "" to "GND".

Changing component "J16:/56F72E3F/571F4AB4" pin "6" net name from "" to "GND".

Changing component "J16:/56F72E3F/571F4AB4" pin "7" net name from "" to "/COM0/COM0C_RXDL".

Changing component "J16:/56F72E3F/571F4AB4" pin "8" net name from "" to "/COM0/COM0C_DSR".

Changing component "J16:/56F72E3F/571F4AB4" pin "9" net name from "" to "/COM0/COM0C_CTSL".

Changing component "J16:/56F72E3F/571F4AB4" pin "10" net name from "" to "Net-(J16-Pad10)".

Info: Checking netlist component footprint "J17:/56F72E3F/56F756F7:Connect:USB_Micro-B".

Adding new component "J17:/56F72E3F/56F756F7" footprint "Connect:USB_Micro-B".

Changing component "J17:/56F72E3F/56F756F7" pin "1" net name from "" to "Net-(J17-Pad1)".

Changing component "J17:/56F72E3F/56F756F7" pin "2" net name from "" to "Net-(J17-Pad2)".

Changing component "J17:/56F72E3F/56F756F7" pin "3" net name from "" to "Net-(J17-Pad3)".

Changing component "J17:/56F72E3F/56F756F7" pin "4" net name from "" to "Net-(J17-Pad4)".

Changing component "J17:/56F72E3F/56F756F7" pin "5" net name from "" to "GND".

Changing component "J17:/56F72E3F/56F756F7" pin "6" net name from "" to "GND".

Changing component "J17:/56F72E3F/56F756F7" pin "6" net name from "" to "GND".

Changing component "J17:/56F72E3F/56F756F7" pin "6" net name from "" to "GND".

Changing component "J17:/56F72E3F/56F756F7" pin "6" net name from "" to "GND".

Info: Checking netlist component footprint "J18:/5712FB0E/570BC734:my-connect:MINIDIN-STR-THRU-6".

Adding new component "J18:/5712FB0E/570BC734" footprint "my-connect:MINIDIN-STR-THRU-6".

Changing component "J18:/5712FB0E/570BC734" pin "2" net name from "" to "Net-(J18-Pad2)".

Changing component "J18:/5712FB0E/570BC734" pin "3" net name from "" to "GND".

Changing component "J18:/5712FB0E/570BC734" pin "4" net name from "" to "+5V".

Changing component "J18:/5712FB0E/570BC734" pin "5" net name from "" to "/PIC-SQPROG/PS2_CLK".

Changing component "J18:/5712FB0E/570BC734" pin "6" net name from "" to "Net-(J18-Pad6)".

Changing component "J18:/5712FB0E/570BC734" pin "1" net name from "" to "/PIC-SQPROG/PS2_DAT".

Changing component "J18:/5712FB0E/570BC734" pin "7" net name from "" to "GND".

Changing component "J18:/5712FB0E/570BC734" pin "8" net name from "" to "GND".

Info: Checking netlist component footprint "J19:/571465DD/571FC0E4:my-connect:PHDR-RA-SMT-1x6".

Adding new component "J19:/571465DD/571FC0E4" footprint "my-connect:PHDR-RA-SMT-1x6".

Changing component "J19:/571465DD/571FC0E4" pin "1" net name from "" to "/PIC-SQPROG/ICSP_MCLR".

Changing component "J19:/571465DD/571FC0E4" pin "2" net name from "" to "Net-(D29-Pad1)".

Changing component "J19:/571465DD/571FC0E4" pin "3" net name from "" to "GND".

Changing component "J19:/571465DD/571FC0E4" pin "4" net name from "" to "/CONFIG/SHIFT_IN".

Changing component "J19:/571465DD/571FC0E4" pin "5" net name from "" to "/CONFIG/SHIFT_CLK".

Changing component "J19:/571465DD/571FC0E4" pin "6" net name from "" to "Net-(J19-Pad6)".

Info: Checking netlist component footprint "J20:/571465DD/571FBEE4:my-connect:SHDR-SMT-2x10".

Adding new component "J20:/571465DD/571FBEE4" footprint "my-connect:SHDR-SMT-2x10".

Changing component "J20:/571465DD/571FBEE4" pin "1" net name from "" to "+3V3".

Changing component "J20:/571465DD/571FBEE4" pin "2" net name from "" to "+3V3".

Changing component "J20:/571465DD/571FBEE4" pin "3" net name from "" to "/CPU/~TRST".

Changing component "J20:/571465DD/571FBEE4" pin "4" net name from "" to "GND".

Changing component "J20:/571465DD/571FBEE4" pin "5" net name from "" to "/CPU/TDI".

Changing component "J20:/571465DD/571FBEE4" pin "6" net name from "" to "GND".

Changing component "J20:/571465DD/571FBEE4" pin "7" net name from "" to "/CPU/TMS".

Changing component "J20:/571465DD/571FBEE4" pin "8" net name from "" to "GND".

Changing component "J20:/571465DD/571FBEE4" pin "9" net name from "" to "/CPU/TCK".

Changing component "J20:/571465DD/571FBEE4" pin "10" net name from "" to "GND".

Changing component "J20:/571465DD/571FBEE4" pin "11" net name from "" to "/CPU/RTCK".

Changing component "J20:/571465DD/571FBEE4" pin "12" net name from "" to "GND".

Changing component "J20:/571465DD/571FBEE4" pin "13" net name from "" to "/CPU/TDO".

Changing component "J20:/571465DD/571FBEE4" pin "14" net name from "" to "GND".

Changing component "J20:/571465DD/571FBEE4" pin "15" net name from "" to "/COM0/~RESET".

Changing component "J20:/571465DD/571FBEE4" pin "16" net name from "" to "GND".

Changing component "J20:/571465DD/571FBEE4" pin "17" net name from "" to "Net-(J20-Pad17)".

Changing component "J20:/571465DD/571FBEE4" pin "18" net name from "" to "GND".

Changing component "J20:/571465DD/571FBEE4" pin "19" net name from "" to "Net-(J20-Pad19)".

Changing component "J20:/571465DD/571FBEE4" pin "20" net name from "" to "GND".

Info: Checking netlist component footprint "J21:/57192609/5717380A:my-connect:RJ45_TRANSFO_PULSE_A".

Adding new component "J21:/57192609/5717380A" footprint "my-connect:RJ45_TRANSFO_PULSE_A".

Changing component "J21:/57192609/5717380A" pin "1" net name from "" to "Net-(J21-Pad1)".

Changing component "J21:/57192609/5717380A" pin "14" net name from "" to "GND".

Changing component "J21:/57192609/5717380A" pin "9" net name from "" to "Net-(J21-Pad9)".

Changing component "J21:/57192609/5717380A" pin "2" net name from "" to "Net-(J21-Pad2)".

Changing component "J21:/57192609/5717380A" pin "3" net name from "" to "Net-(J21-Pad3)".

Changing component "J21:/57192609/5717380A" pin "4" net name from "" to "Net-(C25-Pad1)".

Changing component "J21:/57192609/5717380A" pin "5" net name from "" to "Net-(C26-Pad1)".

Changing component "J21:/57192609/5717380A" pin "6" net name from "" to "Net-(J21-Pad6)".

Changing component "J21:/57192609/5717380A" pin "7" net name from "" to "Net-(J21-Pad7)".

Changing component "J21:/57192609/5717380A" pin "8" net name from "" to "GND".

Changing component "J21:/57192609/5717380A" pin "11" net name from "" to "Net-(J21-Pad11)".

Changing component "J21:/57192609/5717380A" pin "10" net name from "" to "Net-(J21-Pad10)".

Changing component "J21:/57192609/5717380A" pin "12" net name from "" to "Net-(J21-Pad12)".

Changing component "J21:/57192609/5717380A" pin "13" net name from "" to "GND".

Info: Checking netlist component footprint "J22:/57192609/5719C0FF:Connect:USB_A".

Adding new component "J22:/57192609/5719C0FF" footprint "Connect:USB_A".

Changing component "J22:/57192609/5719C0FF" pin "4" net name from "" to "GND".

Changing component "J22:/57192609/5719C0FF" pin "3" net name from "" to "/USB-LAN/USBH_DP".

Changing component "J22:/57192609/5719C0FF" pin "2" net name from "" to "/USB-LAN/USBH_DM".

Changing component "J22:/57192609/5719C0FF" pin "1" net name from "" to "/CPU/USB_PWRD".

Changing component "J22:/57192609/5719C0FF" pin "5" net name from "" to "GND".

Changing component "J22:/57192609/5719C0FF" pin "5" net name from "" to "GND".

Info: Checking netlist component footprint "J23:/57192609/57197AC0:Connect:USB_Micro-B".

Adding new component "J23:/57192609/57197AC0" footprint "Connect:USB_Micro-B".

Changing component "J23:/57192609/57197AC0" pin "1" net name from "" to "Net-(D33-Pad2)".

Changing component "J23:/57192609/57197AC0" pin "2" net name from "" to "/USB-LAN/USBD_DM".

Changing component "J23:/57192609/57197AC0" pin "3" net name from "" to "/USB-LAN/USBD_DP".

Changing component "J23:/57192609/57197AC0" pin "4" net name from "" to "Net-(J23-Pad4)".

Changing component "J23:/57192609/57197AC0" pin "5" net name from "" to "GND".

Changing component "J23:/57192609/57197AC0" pin "6" net name from "" to "GND".

Changing component "J23:/57192609/57197AC0" pin "6" net name from "" to "GND".

Changing component "J23:/57192609/57197AC0" pin "6" net name from "" to "GND".

Changing component "J23:/57192609/57197AC0" pin "6" net name from "" to "GND".

Info: Checking netlist component footprint "J24:/57161414/57165A30:Connect:USB_Micro-B".

Adding new component "J24:/57161414/57165A30" footprint "Connect:USB_Micro-B".

Changing component "J24:/57161414/57165A30" pin "1" net name from "" to "+5V".

Changing component "J24:/57161414/57165A30" pin "2" net name from "" to "Net-(J24-Pad2)".

Changing component "J24:/57161414/57165A30" pin "3" net name from "" to "Net-(J24-Pad3)".

Changing component "J24:/57161414/57165A30" pin "4" net name from "" to "Net-(J24-Pad4)".

Changing component "J24:/57161414/57165A30" pin "5" net name from "" to "GND".

Changing component "J24:/57161414/57165A30" pin "6" net name from "" to "GND".

Changing component "J24:/57161414/57165A30" pin "6" net name from "" to "GND".

Changing component "J24:/57161414/57165A30" pin "6" net name from "" to "GND".

Changing component "J24:/57161414/57165A30" pin "6" net name from "" to "GND".

Info: Checking netlist component footprint "J25:/56FDE856/5726A8EB:my-connect:PHDR-RA-SMT-1x4".

Adding new component "J25:/56FDE856/5726A8EB" footprint "my-connect:PHDR-RA-SMT-1x4".

Changing component "J25:/56FDE856/5726A8EB" pin "1" net name from "" to "+5V".

Changing component "J25:/56FDE856/5726A8EB" pin "2" net name from "" to "Net-(J25-Pad2)".

Changing component "J25:/56FDE856/5726A8EB" pin "3" net name from "" to "Net-(J25-Pad3)".

Changing component "J25:/56FDE856/5726A8EB" pin "4" net name from "" to "Net-(J25-Pad4)".

Info: Checking netlist component footprint "LS1:/5712FB0E/571432E5:my-misc:BUZZER-CSS-0575A".

Adding new component "LS1:/5712FB0E/571432E5" footprint "my-misc:BUZZER-CSS-0575A".

Changing component "LS1:/5712FB0E/571432E5" pin "2" net name from "" to "Net-(LS1-Pad2)".

Changing component "LS1:/5712FB0E/571432E5" pin "1" net name from "" to "+5V".

Info: Checking netlist component footprint "Q1:/56F75D50/571AD428:my-sot-packages:SOT-23-BEC-HAND".

Adding new component "Q1:/56F75D50/571AD428" footprint "my-sot-packages:SOT-23-BEC-HAND".

Changing component "Q1:/56F75D50/571AD428" pin "B" net name from "" to "Net-(Q1-PadB)".

Changing component "Q1:/56F75D50/571AD428" pin "E" net name from "" to "GND".

Changing component "Q1:/56F75D50/571AD428" pin "C" net name from "" to "Net-(Q1-PadC)".

Info: Checking netlist component footprint "Q2:/56F75D50/5717B7F5:my-sot-packages:SOT-323-GSD-HAND".

Adding new component "Q2:/56F75D50/5717B7F5" footprint "my-sot-packages:SOT-323-GSD-HAND".

Changing component "Q2:/56F75D50/5717B7F5" pin "S" net name from "" to "+3V3".

Changing component "Q2:/56F75D50/5717B7F5" pin "G" net name from "" to "/CFG7".

Changing component "Q2:/56F75D50/5717B7F5" pin "D" net name from "" to "Net-(J1-Pad1)".

Info: Checking netlist component footprint "Q3:/56F75D50/5717B681:my-sot-packages:SOT-323-GSD-HAND".

Adding new component "Q3:/56F75D50/5717B681" footprint "my-sot-packages:SOT-323-GSD-HAND".

Changing component "Q3:/56F75D50/5717B681" pin "S" net name from "" to "+5V".

Changing component "Q3:/56F75D50/5717B681" pin "G" net name from "" to "/CFG6".

Changing component "Q3:/56F75D50/5717B681" pin "D" net name from "" to "Net-(J1-Pad1)".

Info: Checking netlist component footprint "Q4:/56FDE856/571CBDED:my-sot-packages:SOT-323-GSD-HAND".

Adding new component "Q4:/56FDE856/571CBDED" footprint "my-sot-packages:SOT-323-GSD-HAND".

Changing component "Q4:/56FDE856/571CBDED" pin "S" net name from "" to "+3V3".

Changing component "Q4:/56FDE856/571CBDED" pin "G" net name from "" to "/CFG11".

Changing component "Q4:/56FDE856/571CBDED" pin "D" net name from "" to "Net-(J5-Pad1)".

Info: Checking netlist component footprint "Q5:/56FDE856/571CBDE6:my-sot-packages:SOT-323-GSD-HAND".

Adding new component "Q5:/56FDE856/571CBDE6" footprint "my-sot-packages:SOT-323-GSD-HAND".

Changing component "Q5:/56FDE856/571CBDE6" pin "S" net name from "" to "+5V".

Changing component "Q5:/56FDE856/571CBDE6" pin "G" net name from "" to "/CFG10".

Changing component "Q5:/56FDE856/571CBDE6" pin "D" net name from "" to "Net-(J5-Pad1)".

Info: Checking netlist component footprint "Q6:/56FF0341/571F269C:my-sot-packages:SOT-323-GSD-HAND".

Adding new component "Q6:/56FF0341/571F269C" footprint "my-sot-packages:SOT-323-GSD-HAND".

Changing component "Q6:/56FF0341/571F269C" pin "S" net name from "" to "+3V3".

Changing component "Q6:/56FF0341/571F269C" pin "G" net name from "" to "/CFG18".

Changing component "Q6:/56FF0341/571F269C" pin "D" net name from "" to "Net-(J10-Pad1)".

Info: Checking netlist component footprint "Q7:/56FF0341/571F314A:my-sot-packages:SOT-323-GSD-HAND".

Adding new component "Q7:/56FF0341/571F314A" footprint "my-sot-packages:SOT-323-GSD-HAND".

Changing component "Q7:/56FF0341/571F314A" pin "S" net name from "" to "+3V3".

Changing component "Q7:/56FF0341/571F314A" pin "G" net name from "" to "/CFG21".

Changing component "Q7:/56FF0341/571F314A" pin "D" net name from "" to "/COM3, PROG/ISP_VDD".

Info: Checking netlist component footprint "Q8:/56FF0341/571F2696:my-sot-packages:SOT-323-GSD-HAND".

Adding new component "Q8:/56FF0341/571F2696" footprint "my-sot-packages:SOT-323-GSD-HAND".

Changing component "Q8:/56FF0341/571F2696" pin "S" net name from "" to "+5V".

Changing component "Q8:/56FF0341/571F2696" pin "G" net name from "" to "/CFG17".

Changing component "Q8:/56FF0341/571F2696" pin "D" net name from "" to "Net-(J10-Pad1)".

Info: Checking netlist component footprint "Q9:/56FF0341/571F3144:my-sot-packages:SOT-323-GSD-HAND".

Adding new component "Q9:/56FF0341/571F3144" footprint "my-sot-packages:SOT-323-GSD-HAND".

Changing component "Q9:/56FF0341/571F3144" pin "S" net name from "" to "+5V".

Changing component "Q9:/56FF0341/571F3144" pin "G" net name from "" to "/CFG20".

Changing component "Q9:/56FF0341/571F3144" pin "D" net name from "" to "/COM3, PROG/ISP_VDD".

Info: Checking netlist component footprint "Q10:/56FF0341/571E0E42:my-sot-packages:SOT-323-GSD-HAND".

Adding new component "Q10:/56FF0341/571E0E42" footprint "my-sot-packages:SOT-323-GSD-HAND".

Changing component "Q10:/56FF0341/571E0E42" pin "S" net name from "" to "+3V3".

Changing component "Q10:/56FF0341/571E0E42" pin "G" net name from "" to "/CFG15".

Changing component "Q10:/56FF0341/571E0E42" pin "D" net name from "" to "Net-(J12-Pad2)".

Info: Checking netlist component footprint "Q11:/56FF0341/571E0E3B:my-sot-packages:SOT-323-GSD-HAND".

Adding new component "Q11:/56FF0341/571E0E3B" footprint "my-sot-packages:SOT-323-GSD-HAND".

Changing component "Q11:/56FF0341/571E0E3B" pin "S" net name from "" to "+5V".

Changing component "Q11:/56FF0341/571E0E3B" pin "G" net name from "" to "/CFG14".

Changing component "Q11:/56FF0341/571E0E3B" pin "D" net name from "" to "Net-(J12-Pad2)".

Info: Checking netlist component footprint "Q12:/56FF0341/571FA801:my-sot-packages:SOT-23-BEC-HAND".

Adding new component "Q12:/56FF0341/571FA801" footprint "my-sot-packages:SOT-23-BEC-HAND".

Changing component "Q12:/56FF0341/571FA801" pin "B" net name from "" to "Net-(Q12-PadB)".

Changing component "Q12:/56FF0341/571FA801" pin "E" net name from "" to "GND".

Changing component "Q12:/56FF0341/571FA801" pin "C" net name from "" to "/COM3, PROG/ISP_VPP_~MCLR".

Info: Checking netlist component footprint "Q13:/56F72E3F/572218D9:my-sot-packages:SOT-23-BEC-HAND".

Adding new component "Q13:/56F72E3F/572218D9" footprint "my-sot-packages:SOT-23-BEC-HAND".

Changing component "Q13:/56F72E3F/572218D9" pin "B" net name from "" to "Net-(Q13-PadB)".

Changing component "Q13:/56F72E3F/572218D9" pin "E" net name from "" to "GND".

Changing component "Q13:/56F72E3F/572218D9" pin "C" net name from "" to "Net-(Q13-PadC)".

Info: Checking netlist component footprint "Q14:/56F72E3F/57229136:my-sot-packages:SOT-23-BEC-HAND".

Adding new component "Q14:/56F72E3F/57229136" footprint "my-sot-packages:SOT-23-BEC-HAND".

Changing component "Q14:/56F72E3F/57229136" pin "B" net name from "" to "Net-(Q14-PadB)".

Changing component "Q14:/56F72E3F/57229136" pin "E" net name from "" to "GND".

Changing component "Q14:/56F72E3F/57229136" pin "C" net name from "" to "Net-(Q14-PadC)".

Info: Checking netlist component footprint "Q15:/56F72E3F/571AB7CA:my-sot-packages:SOT-23-BEC-HAND".

Adding new component "Q15:/56F72E3F/571AB7CA" footprint "my-sot-packages:SOT-23-BEC-HAND".

Changing component "Q15:/56F72E3F/571AB7CA" pin "B" net name from "" to "Net-(Q15-PadB)".

Changing component "Q15:/56F72E3F/571AB7CA" pin "E" net name from "" to "GND".

Changing component "Q15:/56F72E3F/571AB7CA" pin "C" net name from "" to "/CPU/BOOT_ISP".

Info: Checking netlist component footprint "Q16:/56F72E3F/571AC253:my-sot-packages:SOT-23-BEC-HAND".

Adding new component "Q16:/56F72E3F/571AC253" footprint "my-sot-packages:SOT-23-BEC-HAND".

Changing component "Q16:/56F72E3F/571AC253" pin "B" net name from "" to "Net-(Q16-PadB)".

Changing component "Q16:/56F72E3F/571AC253" pin "E" net name from "" to "GND".

Changing component "Q16:/56F72E3F/571AC253" pin "C" net name from "" to "/COM0/~RESET".

Info: Checking netlist component footprint "Q17:/5712FB0E/571443FD:my-sot-packages:SOT-23-BEC-HAND".

Adding new component "Q17:/5712FB0E/571443FD" footprint "my-sot-packages:SOT-23-BEC-HAND".

Changing component "Q17:/5712FB0E/571443FD" pin "B" net name from "" to "Net-(Q17-PadB)".

Changing component "Q17:/5712FB0E/571443FD" pin "E" net name from "" to "GND".

Changing component "Q17:/5712FB0E/571443FD" pin "C" net name from "" to "Net-(LS1-Pad2)".

Info: Checking netlist component footprint "Q18:/571465DD/5728D8AE:my-sot-packages:SOT-23-BEC-HAND".

Adding new component "Q18:/571465DD/5728D8AE" footprint "my-sot-packages:SOT-23-BEC-HAND".

Changing component "Q18:/571465DD/5728D8AE" pin "B" net name from "" to "Net-(Q18-PadB)".

Changing component "Q18:/571465DD/5728D8AE" pin "E" net name from "" to "GND".

Changing component "Q18:/571465DD/5728D8AE" pin "C" net name from "" to "/PIC-SQPROG/DISP_BACKL".

Info: Checking netlist component footprint "Q19:/57192609/57199BA0:my-sot-packages:SOT-23-BEC-HAND".

Adding new component "Q19:/57192609/57199BA0" footprint "my-sot-packages:SOT-23-BEC-HAND".

Changing component "Q19:/57192609/57199BA0" pin "B" net name from "" to "Net-(Q19-PadB)".

Changing component "Q19:/57192609/57199BA0" pin "E" net name from "" to "+5V".

Changing component "Q19:/57192609/57199BA0" pin "C" net name from "" to "Net-(Q19-PadC)".

Info: Checking netlist component footprint "Q20:/56FDE856/57231076:my-sot-packages:SOT-23-BEC-HAND".

Adding new component "Q20:/56FDE856/57231076" footprint "my-sot-packages:SOT-23-BEC-HAND".

Changing component "Q20:/56FDE856/57231076" pin "B" net name from "" to "Net-(Q20-PadB)".

Changing component "Q20:/56FDE856/57231076" pin "E" net name from "" to "GND".

Changing component "Q20:/56FDE856/57231076" pin "C" net name from "" to "Net-(Q20-PadC)".

Info: Checking netlist component footprint "R1:/56F75D50/571AD438:Resistors_SMD:R_0805_HandSoldering".

Adding new component "R1:/56F75D50/571AD438" footprint "Resistors_SMD:R_0805_HandSoldering".

Changing component "R1:/56F75D50/571AD438" pin "1" net name from "" to "/CFG3".

Changing component "R1:/56F75D50/571AD438" pin "2" net name from "" to "Net-(Q1-PadB)".

Info: Checking netlist component footprint "R2:/56F75D50/571AD431:Resistors_SMD:R_0805_HandSoldering".

Adding new component "R2:/56F75D50/571AD431" footprint "Resistors_SMD:R_0805_HandSoldering".

Changing component "R2:/56F75D50/571AD431" pin "1" net name from "" to "+3V3".

Changing component "R2:/56F75D50/571AD431" pin "2" net name from "" to "Net-(Q1-PadC)".

Info: Checking netlist component footprint "R3:/56F75D50/571C0319:Resistors_SMD:R_0805_HandSoldering".

Adding new component "R3:/56F75D50/571C0319" footprint "Resistors_SMD:R_0805_HandSoldering".

Changing component "R3:/56F75D50/571C0319" pin "1" net name from "" to "/CFG4".

Changing component "R3:/56F75D50/571C0319" pin "2" net name from "" to "GND".

Info: Checking netlist component footprint "R4:/56F75D50/571C1EB3:Resistors_SMD:R_0805_HandSoldering".

Adding new component "R4:/56F75D50/571C1EB3" footprint "Resistors_SMD:R_0805_HandSoldering".

Changing component "R4:/56F75D50/571C1EB3" pin "1" net name from "" to "+3V3".

Changing component "R4:/56F75D50/571C1EB3" pin "2" net name from "" to "Net-(R4-Pad2)".

Info: Checking netlist component footprint "R5:/56F75D50/56FC47D0:Resistors_SMD:R_0805_HandSoldering".

Adding new component "R5:/56F75D50/56FC47D0" footprint "Resistors_SMD:R_0805_HandSoldering".

Changing component "R5:/56F75D50/56FC47D0" pin "1" net name from "" to "Net-(R5-Pad1)".

Changing component "R5:/56F75D50/56FC47D0" pin "2" net name from "" to "GND".

Info: Checking netlist component footprint "R6:/56F75D50/56FC2099:Resistors_SMD:R_0805_HandSoldering".

Adding new component "R6:/56F75D50/56FC2099" footprint "Resistors_SMD:R_0805_HandSoldering".

Changing component "R6:/56F75D50/56FC2099" pin "1" net name from "" to "Net-(R6-Pad1)".

Changing component "R6:/56F75D50/56FC2099" pin "2" net name from "" to "GND".

Info: Checking netlist component footprint "R7:/56F75D50/56FC5614:Resistors_SMD:R_0805_HandSoldering".

Adding new component "R7:/56F75D50/56FC5614" footprint "Resistors_SMD:R_0805_HandSoldering".

Changing component "R7:/56F75D50/56FC5614" pin "1" net name from "" to "/COM1/COM1_TXDL".

Changing component "R7:/56F75D50/56FC5614" pin "2" net name from "" to "GND".

Info: Checking netlist component footprint "R8:/56F75D50/5723F39C:Resistors_SMD:R_0805_HandSoldering".

Adding new component "R8:/56F75D50/5723F39C" footprint "Resistors_SMD:R_0805_HandSoldering".

Changing component "R8:/56F75D50/5723F39C" pin "1" net name from "" to "/CFG5".

Changing component "R8:/56F75D50/5723F39C" pin "2" net name from "" to "GND".

Info: Checking netlist component footprint "R9:/56F75D50/5717AD05:Resistors_SMD:R_0805_HandSoldering".

Adding new component "R9:/56F75D50/5717AD05" footprint "Resistors_SMD:R_0805_HandSoldering".

Changing component "R9:/56F75D50/5717AD05" pin "1" net name from "" to "+3V3".

Changing component "R9:/56F75D50/5717AD05" pin "2" net name from "" to "/CFG7".

Info: Checking netlist component footprint "R10:/56F75D50/5717C83E:Resistors_SMD:R_0805_HandSoldering".

Adding new component "R10:/56F75D50/5717C83E" footprint "Resistors_SMD:R_0805_HandSoldering".

Changing component "R10:/56F75D50/5717C83E" pin "1" net name from "" to "+5V".

Changing component "R10:/56F75D50/5717C83E" pin "2" net name from "" to "/CFG6".

Info: Checking netlist component footprint "R11:/56F75D50/571D723E:Resistors_SMD:R_0805_HandSoldering".

Adding new component "R11:/56F75D50/571D723E" footprint "Resistors_SMD:R_0805_HandSoldering".

Changing component "R11:/56F75D50/571D723E" pin "1" net name from "" to "Net-(D1-Pad1)".

Changing component "R11:/56F75D50/571D723E" pin "2" net name from "" to "/CFG6".

Info: Checking netlist component footprint "R12:/56F75D50/571D7255:Resistors_SMD:R_0805_HandSoldering".

Adding new component "R12:/56F75D50/571D7255" footprint "Resistors_SMD:R_0805_HandSoldering".

Changing component "R12:/56F75D50/571D7255" pin "1" net name from "" to "Net-(D2-Pad1)".

Changing component "R12:/56F75D50/571D7255" pin "2" net name from "" to "/CFG7".

Info: Checking netlist component footprint "R13:/56F75D50/571BE39B:Resistors_SMD:R_0805_HandSoldering".

Adding new component "R13:/56F75D50/571BE39B" footprint "Resistors_SMD:R_0805_HandSoldering".

Changing component "R13:/56F75D50/571BE39B" pin "1" net name from "" to "Net-(D3-Pad2)".

Changing component "R13:/56F75D50/571BE39B" pin "2" net name from "" to "/CFG5".

Info: Checking netlist component footprint "R14:/56F75D50/571BCE25:Resistors_SMD:R_0805_HandSoldering".

Adding new component "R14:/56F75D50/571BCE25" footprint "Resistors_SMD:R_0805_HandSoldering".

Changing component "R14:/56F75D50/571BCE25" pin "1" net name from "" to "Net-(D4-Pad2)".

Changing component "R14:/56F75D50/571BCE25" pin "2" net name from "" to "/CFG3".

Info: Checking netlist component footprint "R15:/56F75D50/571C295E:Resistors_SMD:R_0805_HandSoldering".

Adding new component "R15:/56F75D50/571C295E" footprint "Resistors_SMD:R_0805_HandSoldering".

Changing component "R15:/56F75D50/571C295E" pin "1" net name from "" to "Net-(D5-Pad2)".

Changing component "R15:/56F75D50/571C295E" pin "2" net name from "" to "/CFG4".

Info: Checking netlist component footprint "R16:/56FDE856/5718DB2A:Resistors_SMD:R_0805_HandSoldering".

Adding new component "R16:/56FDE856/5718DB2A" footprint "Resistors_SMD:R_0805_HandSoldering".

Changing component "R16:/56FDE856/5718DB2A" pin "1" net name from "" to "/CFG12".

Changing component "R16:/56FDE856/5718DB2A" pin "2" net name from "" to "+5V".

Info: Checking netlist component footprint "R17:/56FDE856/571CBE10:Resistors_SMD:R_0805_HandSoldering".

Adding new component "R17:/56FDE856/571CBE10" footprint "Resistors_SMD:R_0805_HandSoldering".

Changing component "R17:/56FDE856/571CBE10" pin "1" net name from "" to "/CFG9".

Changing component "R17:/56FDE856/571CBE10" pin "2" net name from "" to "GND".

Info: Checking netlist component footprint "R18:/56FDE856/5718DAF5:Resistors_SMD:R_0805_HandSoldering".

Adding new component "R18:/56FDE856/5718DAF5" footprint "Resistors_SMD:R_0805_HandSoldering".

Changing component "R18:/56FDE856/5718DAF5" pin "1" net name from "" to "Net-(C7-Pad1)".

Changing component "R18:/56FDE856/5718DAF5" pin "2" net name from "" to "Net-(J25-Pad2)".

Info: Checking netlist component footprint "R19:/56FDE856/5718DAFC:Resistors_SMD:R_0805_HandSoldering".

Adding new component "R19:/56FDE856/5718DAFC" footprint "Resistors_SMD:R_0805_HandSoldering".

Changing component "R19:/56FDE856/5718DAFC" pin "1" net name from "" to "Net-(C7-Pad1)".

Changing component "R19:/56FDE856/5718DAFC" pin "2" net name from "" to "Net-(J25-Pad3)".

Info: Checking netlist component footprint "R20:/56FDE856/571CBDDF:Resistors_SMD:R_0805_HandSoldering".

Adding new component "R20:/56FDE856/571CBDDF" footprint "Resistors_SMD:R_0805_HandSoldering".

Changing component "R20:/56FDE856/571CBDDF" pin "1" net name from "" to "+3V3".

Changing component "R20:/56FDE856/571CBDDF" pin "2" net name from "" to "/CFG11".

Info: Checking netlist component footprint "R21:/56FDE856/571CBE00:Resistors_SMD:R_0805_HandSoldering".

Adding new component "R21:/56FDE856/571CBE00" footprint "Resistors_SMD:R_0805_HandSoldering".

Changing component "R21:/56FDE856/571CBE00" pin "1" net name from "" to "+5V".

Changing component "R21:/56FDE856/571CBE00" pin "2" net name from "" to "/CFG10".

Info: Checking netlist component footprint "R22:/56FDE856/571D23FC:Resistors_SMD:R_0805_HandSoldering".

Adding new component "R22:/56FDE856/571D23FC" footprint "Resistors_SMD:R_0805_HandSoldering".

Changing component "R22:/56FDE856/571D23FC" pin "1" net name from "" to "Net-(D6-Pad1)".

Changing component "R22:/56FDE856/571D23FC" pin "2" net name from "" to "/CFG10".

Info: Checking netlist component footprint "R23:/56FDE856/571D24AF:Resistors_SMD:R_0805_HandSoldering".

Adding new component "R23:/56FDE856/571D24AF" footprint "Resistors_SMD:R_0805_HandSoldering".

Changing component "R23:/56FDE856/571D24AF" pin "1" net name from "" to "Net-(D7-Pad1)".

Changing component "R23:/56FDE856/571D24AF" pin "2" net name from "" to "/CFG11".

Info: Checking netlist component footprint "R24:/56FDE856/571CBE74:Resistors_SMD:R_0805_HandSoldering".

Adding new component "R24:/56FDE856/571CBE74" footprint "Resistors_SMD:R_0805_HandSoldering".

Changing component "R24:/56FDE856/571CBE74" pin "1" net name from "" to "Net-(D8-Pad2)".

Changing component "R24:/56FDE856/571CBE74" pin "2" net name from "" to "/CFG9".

Info: Checking netlist component footprint "R25:/56FF0341/571710B8:Resistors_SMD:R_0805_HandSoldering".

Adding new component "R25:/56FF0341/571710B8" footprint "Resistors_SMD:R_0805_HandSoldering".

Changing component "R25:/56FF0341/571710B8" pin "1" net name from "" to "/CFG13".

Changing component "R25:/56FF0341/571710B8" pin "2" net name from "" to "GND".

Info: Checking netlist component footprint "R26:/56FF0341/57184436:Resistors_SMD:R_0805_HandSoldering".

Adding new component "R26:/56FF0341/57184436" footprint "Resistors_SMD:R_0805_HandSoldering".

Changing component "R26:/56FF0341/57184436" pin "1" net name from "" to "/CFG16".

Changing component "R26:/56FF0341/57184436" pin "2" net name from "" to "GND".

Info: Checking netlist component footprint "R27:/56FF0341/571F26E7:Resistors_SMD:R_0805_HandSoldering".

Adding new component "R27:/56FF0341/571F26E7" footprint "Resistors_SMD:R_0805_HandSoldering".

Changing component "R27:/56FF0341/571F26E7" pin "1" net name from "" to "+3V3".

Changing component "R27:/56FF0341/571F26E7" pin "2" net name from "" to "/CFG18".

Info: Checking netlist component footprint "R28:/56FF0341/571F318F:Resistors_SMD:R_0805_HandSoldering".

Adding new component "R28:/56FF0341/571F318F" footprint "Resistors_SMD:R_0805_HandSoldering".

Changing component "R28:/56FF0341/571F318F" pin "1" net name from "" to "+3V3".

Changing component "R28:/56FF0341/571F318F" pin "2" net name from "" to "/CFG21".

Info: Checking netlist component footprint "R29:/56FF0341/571F26EE:Resistors_SMD:R_0805_HandSoldering".

Adding new component "R29:/56FF0341/571F26EE" footprint "Resistors_SMD:R_0805_HandSoldering".

Changing component "R29:/56FF0341/571F26EE" pin "1" net name from "" to "+5V".

Changing component "R29:/56FF0341/571F26EE" pin "2" net name from "" to "/CFG17".

Info: Checking netlist component footprint "R30:/56FF0341/571F3196:Resistors_SMD:R_0805_HandSoldering".

Adding new component "R30:/56FF0341/571F3196" footprint "Resistors_SMD:R_0805_HandSoldering".

Changing component "R30:/56FF0341/571F3196" pin "1" net name from "" to "+5V".

Changing component "R30:/56FF0341/571F3196" pin "2" net name from "" to "/CFG20".

Info: Checking netlist component footprint "R31:/56FF0341/571E73F8:Resistors_SMD:R_0805_HandSoldering".

Adding new component "R31:/56FF0341/571E73F8" footprint "Resistors_SMD:R_0805_HandSoldering".

Changing component "R31:/56FF0341/571E73F8" pin "1" net name from "" to "+3V3".

Changing component "R31:/56FF0341/571E73F8" pin "2" net name from "" to "/CFG15".

Info: Checking netlist component footprint "R32:/56FF0341/57200FE3:Resistors_SMD:R_0805_HandSoldering".

Adding new component "R32:/56FF0341/57200FE3" footprint "Resistors_SMD:R_0805_HandSoldering".

Changing component "R32:/56FF0341/57200FE3" pin "1" net name from "" to "Net-(D9-Pad2)".

Changing component "R32:/56FF0341/57200FE3" pin "2" net name from "" to "/CFG19".

Info: Checking netlist component footprint "R33:/56FF0341/571F26C5:Resistors_SMD:R_0805_HandSoldering".

Adding new component "R33:/56FF0341/571F26C5" footprint "Resistors_SMD:R_0805_HandSoldering".

Changing component "R33:/56FF0341/571F26C5" pin "1" net name from "" to "Net-(D10-Pad1)".

Changing component "R33:/56FF0341/571F26C5" pin "2" net name from "" to "/CFG17".

Info: Checking netlist component footprint "R34:/56FF0341/571F26D9:Resistors_SMD:R_0805_HandSoldering".

Adding new component "R34:/56FF0341/571F26D9" footprint "Resistors_SMD:R_0805_HandSoldering".

Changing component "R34:/56FF0341/571F26D9" pin "1" net name from "" to "Net-(D11-Pad1)".

Changing component "R34:/56FF0341/571F26D9" pin "2" net name from "" to "/CFG18".

Info: Checking netlist component footprint "R35:/56FF0341/571F316D:Resistors_SMD:R_0805_HandSoldering".

Adding new component "R35:/56FF0341/571F316D" footprint "Resistors_SMD:R_0805_HandSoldering".

Changing component "R35:/56FF0341/571F316D" pin "1" net name from "" to "Net-(D12-Pad1)".

Changing component "R35:/56FF0341/571F316D" pin "2" net name from "" to "/CFG20".

Info: Checking netlist component footprint "R36:/56FF0341/571F3181:Resistors_SMD:R_0805_HandSoldering".

Adding new component "R36:/56FF0341/571F3181" footprint "Resistors_SMD:R_0805_HandSoldering".

Changing component "R36:/56FF0341/571F3181" pin "1" net name from "" to "Net-(D13-Pad1)".

Changing component "R36:/56FF0341/571F3181" pin "2" net name from "" to "/CFG21".

Info: Checking netlist component footprint "R37:/56FF0341/571E815F:Resistors_SMD:R_0805_HandSoldering".

Adding new component "R37:/56FF0341/571E815F" footprint "Resistors_SMD:R_0805_HandSoldering".

Changing component "R37:/56FF0341/571E815F" pin "1" net name from "" to "+5V".

Changing component "R37:/56FF0341/571E815F" pin "2" net name from "" to "/CFG14".

Info: Checking netlist component footprint "R38:/56FF0341/571FA7EE:Resistors_SMD:R_0805_HandSoldering".

Adding new component "R38:/56FF0341/571FA7EE" footprint "Resistors_SMD:R_0805_HandSoldering".

Changing component "R38:/56FF0341/571FA7EE" pin "1" net name from "" to "/COM3, PROG/~ISP_SSEL".

Changing component "R38:/56FF0341/571FA7EE" pin "2" net name from "" to "Net-(Q12-PadB)".

Info: Checking netlist component footprint "R39:/56FF0341/571E5DAE:Resistors_SMD:R_0805_HandSoldering".

Adding new component "R39:/56FF0341/571E5DAE" footprint "Resistors_SMD:R_0805_HandSoldering".

Changing component "R39:/56FF0341/571E5DAE" pin "1" net name from "" to "Net-(D16-Pad2)".

Changing component "R39:/56FF0341/571E5DAE" pin "2" net name from "" to "/CFG13".

Info: Checking netlist component footprint "R40:/56FF0341/571E0EA7:Resistors_SMD:R_0805_HandSoldering".

Adding new component "R40:/56FF0341/571E0EA7" footprint "Resistors_SMD:R_0805_HandSoldering".

Changing component "R40:/56FF0341/571E0EA7" pin "1" net name from "" to "Net-(D14-Pad1)".

Changing component "R40:/56FF0341/571E0EA7" pin "2" net name from "" to "/CFG14".

Info: Checking netlist component footprint "R41:/56FF0341/571E0EBE:Resistors_SMD:R_0805_HandSoldering".

Adding new component "R41:/56FF0341/571E0EBE" footprint "Resistors_SMD:R_0805_HandSoldering".

Changing component "R41:/56FF0341/571E0EBE" pin "1" net name from "" to "Net-(D15-Pad1)".

Changing component "R41:/56FF0341/571E0EBE" pin "2" net name from "" to "/CFG15".

Info: Checking netlist component footprint "R42:/56FF0341/571FBE92:Resistors_SMD:R_0805_HandSoldering".

Adding new component "R42:/56FF0341/571FBE92" footprint "Resistors_SMD:R_0805_HandSoldering".

Changing component "R42:/56FF0341/571FBE92" pin "1" net name from "" to "/COM3, PROG/ISP_VPP_~MCLR".

Changing component "R42:/56FF0341/571FBE92" pin "2" net name from "" to "/COM3, PROG/ISP_VDD".

Info: Checking netlist component footprint "R43:/56FF0341/571E59F3:Resistors_SMD:R_0805_HandSoldering".

Adding new component "R43:/56FF0341/571E59F3" footprint "Resistors_SMD:R_0805_HandSoldering".

Changing component "R43:/56FF0341/571E59F3" pin "1" net name from "" to "Net-(D17-Pad2)".

Changing component "R43:/56FF0341/571E59F3" pin "2" net name from "" to "/CFG16".

Info: Checking netlist component footprint "R44:/56F72C60/571BF28A:Resistors_SMD:R_0805_HandSoldering".

Adding new component "R44:/56F72C60/571BF28A" footprint "Resistors_SMD:R_0805_HandSoldering".

Changing component "R44:/56F72C60/571BF28A" pin "1" net name from "" to "+3V3".

Changing component "R44:/56F72C60/571BF28A" pin "2" net name from "" to "/CPU/BOOT_ISP".

Info: Checking netlist component footprint "R45:/56F72C60/5718A9DD:Resistors_SMD:R_0805_HandSoldering".

Adding new component "R45:/56F72C60/5718A9DD" footprint "Resistors_SMD:R_0805_HandSoldering".

Changing component "R45:/56F72C60/5718A9DD" pin "1" net name from "" to "+3V3".

Changing component "R45:/56F72C60/5718A9DD" pin "2" net name from "" to "/COM0/~RESET".

Info: Checking netlist component footprint "R46:/56F72C60/571BEEE5:Resistors_SMD:R_0805_HandSoldering".

Adding new component "R46:/56F72C60/571BEEE5" footprint "Resistors_SMD:R_0805_HandSoldering".

Changing component "R46:/56F72C60/571BEEE5" pin "1" net name from "" to "/CPU/TCK".

Changing component "R46:/56F72C60/571BEEE5" pin "2" net name from "" to "GND".

Info: Checking netlist component footprint "R47:/56F72C60/57189ED7:Resistors_SMD:R_0805_HandSoldering".

Adding new component "R47:/56F72C60/57189ED7" footprint "Resistors_SMD:R_0805_HandSoldering".

Changing component "R47:/56F72C60/57189ED7" pin "1" net name from "" to "+3V3".

Changing component "R47:/56F72C60/57189ED7" pin "2" net name from "" to "/CPU/~TRST".

Info: Checking netlist component footprint "R48:/56F72C60/57189A26:Resistors_SMD:R_0805_HandSoldering".

Adding new component "R48:/56F72C60/57189A26" footprint "Resistors_SMD:R_0805_HandSoldering".

Changing component "R48:/56F72C60/57189A26" pin "1" net name from "" to "+3V3".

Changing component "R48:/56F72C60/57189A26" pin "2" net name from "" to "/CPU/TMS".

Info: Checking netlist component footprint "R49:/56F72C60/571894F8:Resistors_SMD:R_0805_HandSoldering".

Adding new component "R49:/56F72C60/571894F8" footprint "Resistors_SMD:R_0805_HandSoldering".

Changing component "R49:/56F72C60/571894F8" pin "1" net name from "" to "+3V3".

Changing component "R49:/56F72C60/571894F8" pin "2" net name from "" to "/CPU/TDI".

Info: Checking netlist component footprint "R50:/56F72C60/571897E1:Resistors_SMD:R_0805_HandSoldering".

Adding new component "R50:/56F72C60/571897E1" footprint "Resistors_SMD:R_0805_HandSoldering".

Changing component "R50:/56F72C60/571897E1" pin "1" net name from "" to "+3V3".

Changing component "R50:/56F72C60/571897E1" pin "2" net name from "" to "/CPU/TDO".

Info: Checking netlist component footprint "R51:/56F72E3F/5722C716:Resistors_SMD:R_0805_HandSoldering".

Adding new component "R51:/56F72E3F/5722C716" footprint "Resistors_SMD:R_0805_HandSoldering".

Changing component "R51:/56F72E3F/5722C716" pin "1" net name from "" to "Net-(D18-Pad2)".

Changing component "R51:/56F72E3F/5722C716" pin "2" net name from "" to "/CFG1".

Info: Checking netlist component footprint "R52:/56F72E3F/57222247:Resistors_SMD:R_0805_HandSoldering".

Adding new component "R52:/56F72E3F/57222247" footprint "Resistors_SMD:R_0805_HandSoldering".

Changing component "R52:/56F72E3F/57222247" pin "1" net name from "" to "Net-(Q13-PadC)".

Changing component "R52:/56F72E3F/57222247" pin "2" net name from "" to "Net-(J17-Pad1)".

Info: Checking netlist component footprint "R53:/56F72E3F/57220F35:Resistors_SMD:R_0805_HandSoldering".

Adding new component "R53:/56F72E3F/57220F35" footprint "Resistors_SMD:R_0805_HandSoldering".

Changing component "R53:/56F72E3F/57220F35" pin "1" net name from "" to "Net-(Q13-PadC)".

Changing component "R53:/56F72E3F/57220F35" pin "2" net name from "" to "GND".

Info: Checking netlist component footprint "R54:/56F72E3F/5723CEC4:Resistors_SMD:R_0805_HandSoldering".

Adding new component "R54:/56F72E3F/5723CEC4" footprint "Resistors_SMD:R_0805_HandSoldering".

Changing component "R54:/56F72E3F/5723CEC4" pin "1" net name from "" to "Net-(D19-Pad2)".

Changing component "R54:/56F72E3F/5723CEC4" pin "2" net name from "" to "/CFG2".

Info: Checking netlist component footprint "R55:/56F72E3F/5722784B:Resistors_SMD:R_0805_HandSoldering".

Adding new component "R55:/56F72E3F/5722784B" footprint "Resistors_SMD:R_0805_HandSoldering".

Changing component "R55:/56F72E3F/5722784B" pin "1" net name from "" to "Net-(D20-Pad2)".

Changing component "R55:/56F72E3F/5722784B" pin "2" net name from "" to "/CFG0".

Info: Checking netlist component footprint "R56:/56F72E3F/57222068:Resistors_SMD:R_0805_HandSoldering".

Adding new component "R56:/56F72E3F/57222068" footprint "Resistors_SMD:R_0805_HandSoldering".

Changing component "R56:/56F72E3F/57222068" pin "1" net name from "" to "Net-(Q13-PadB)".

Changing component "R56:/56F72E3F/57222068" pin "2" net name from "" to "/CFG0".

Info: Checking netlist component footprint "R57:/56F72E3F/57236712:Resistors_SMD:R_0805_HandSoldering".

Adding new component "R57:/56F72E3F/57236712" footprint "Resistors_SMD:R_0805_HandSoldering".

Changing component "R57:/56F72E3F/57236712" pin "1" net name from "" to "/CFG2".

Changing component "R57:/56F72E3F/57236712" pin "2" net name from "" to "GND".

Info: Checking netlist component footprint "R58:/56F72E3F/5721FE01:Resistors_SMD:R_0805_HandSoldering".

Adding new component "R58:/56F72E3F/5721FE01" footprint "Resistors_SMD:R_0805_HandSoldering".

Changing component "R58:/56F72E3F/5721FE01" pin "1" net name from "" to "+3V3".

Changing component "R58:/56F72E3F/5721FE01" pin "2" net name from "" to "/COM0/COM0_RXDL".

Info: Checking netlist component footprint "R59:/56F72E3F/5721FEF2:Resistors_SMD:R_0805_HandSoldering".

Adding new component "R59:/56F72E3F/5721FEF2" footprint "Resistors_SMD:R_0805_HandSoldering".

Changing component "R59:/56F72E3F/5721FEF2" pin "1" net name from "" to "+3V3".

Changing component "R59:/56F72E3F/5721FEF2" pin "2" net name from "" to "/COM0/COM0_TXDL".

Info: Checking netlist component footprint "R60:/56F72E3F/5722000F:Resistors_SMD:R_0805_HandSoldering".

Adding new component "R60:/56F72E3F/5722000F" footprint "Resistors_SMD:R_0805_HandSoldering".

Changing component "R60:/56F72E3F/5722000F" pin "1" net name from "" to "+3V3".

Changing component "R60:/56F72E3F/5722000F" pin "2" net name from "" to "/COM0/COM0_CTSL".

Info: Checking netlist component footprint "R61:/56F72E3F/57220015:Resistors_SMD:R_0805_HandSoldering".

Adding new component "R61:/56F72E3F/57220015" footprint "Resistors_SMD:R_0805_HandSoldering".

Changing component "R61:/56F72E3F/57220015" pin "1" net name from "" to "+3V3".

Changing component "R61:/56F72E3F/57220015" pin "2" net name from "" to "/COM0/COM0_RTSL".

Info: Checking netlist component footprint "R62:/56F72E3F/5722006E:Resistors_SMD:R_0805_HandSoldering".

Adding new component "R62:/56F72E3F/5722006E" footprint "Resistors_SMD:R_0805_HandSoldering".

Changing component "R62:/56F72E3F/5722006E" pin "1" net name from "" to "+3V3".

Changing component "R62:/56F72E3F/5722006E" pin "2" net name from "" to "/COM0/COM0_DSR".

Info: Checking netlist component footprint "R63:/56F72E3F/57220074:Resistors_SMD:R_0805_HandSoldering".

Adding new component "R63:/56F72E3F/57220074" footprint "Resistors_SMD:R_0805_HandSoldering".

Changing component "R63:/56F72E3F/57220074" pin "1" net name from "" to "+3V3".

Changing component "R63:/56F72E3F/57220074" pin "2" net name from "" to "/COM0/COM0_DTR".

Info: Checking netlist component footprint "R64:/56F72E3F/5722913E:Resistors_SMD:R_0805_HandSoldering".

Adding new component "R64:/56F72E3F/5722913E" footprint "Resistors_SMD:R_0805_HandSoldering".

Changing component "R64:/56F72E3F/5722913E" pin "1" net name from "" to "+3V3".

Changing component "R64:/56F72E3F/5722913E" pin "2" net name from "" to "Net-(Q14-PadC)".

Info: Checking netlist component footprint "R65:/56F72E3F/57229CBB:Resistors_SMD:R_0805_HandSoldering".

Adding new component "R65:/56F72E3F/57229CBB" footprint "Resistors_SMD:R_0805_HandSoldering".

Changing component "R65:/56F72E3F/57229CBB" pin "1" net name from "" to "/CFG1".

Changing component "R65:/56F72E3F/57229CBB" pin "2" net name from "" to "Net-(Q14-PadB)".

Info: Checking netlist component footprint "R66:/56F72E3F/571AB7D7:Resistors_SMD:R_0805_HandSoldering".

Adding new component "R66:/56F72E3F/571AB7D7" footprint "Resistors_SMD:R_0805_HandSoldering".

Changing component "R66:/56F72E3F/571AB7D7" pin "1" net name from "" to "Net-(Q15-PadB)".

Changing component "R66:/56F72E3F/571AB7D7" pin "2" net name from "" to "/COM0/COM0_RTSL".

Info: Checking netlist component footprint "R67:/56F72E3F/571AC25F:Resistors_SMD:R_0805_HandSoldering".

Adding new component "R67:/56F72E3F/571AC25F" footprint "Resistors_SMD:R_0805_HandSoldering".

Changing component "R67:/56F72E3F/571AC25F" pin "1" net name from "" to "Net-(Q16-PadB)".

Changing component "R67:/56F72E3F/571AC25F" pin "2" net name from "" to "/COM0/COM0_DTR".

Info: Checking netlist component footprint "R68:/5712FB0E/5714456A:Resistors_SMD:R_0805_HandSoldering".

Adding new component "R68:/5712FB0E/5714456A" footprint "Resistors_SMD:R_0805_HandSoldering".

Changing component "R68:/5712FB0E/5714456A" pin "1" net name from "" to "Net-(Q17-PadB)".

Changing component "R68:/5712FB0E/5714456A" pin "2" net name from "" to "/USER/BUZZ".

Info: Checking netlist component footprint "R69:/571465DD/5714AC67:Resistors_SMD:R_0805_HandSoldering".

Adding new component "R69:/571465DD/5714AC67" footprint "Resistors_SMD:R_0805_HandSoldering".

Changing component "R69:/571465DD/5714AC67" pin "1" net name from "" to "+3V3".

Changing component "R69:/571465DD/5714AC67" pin "2" net name from "" to "/COM0/~RESET".

Info: Checking netlist component footprint "R70:/571465DD/5714BC01:Resistors_SMD:R_0805_HandSoldering".
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

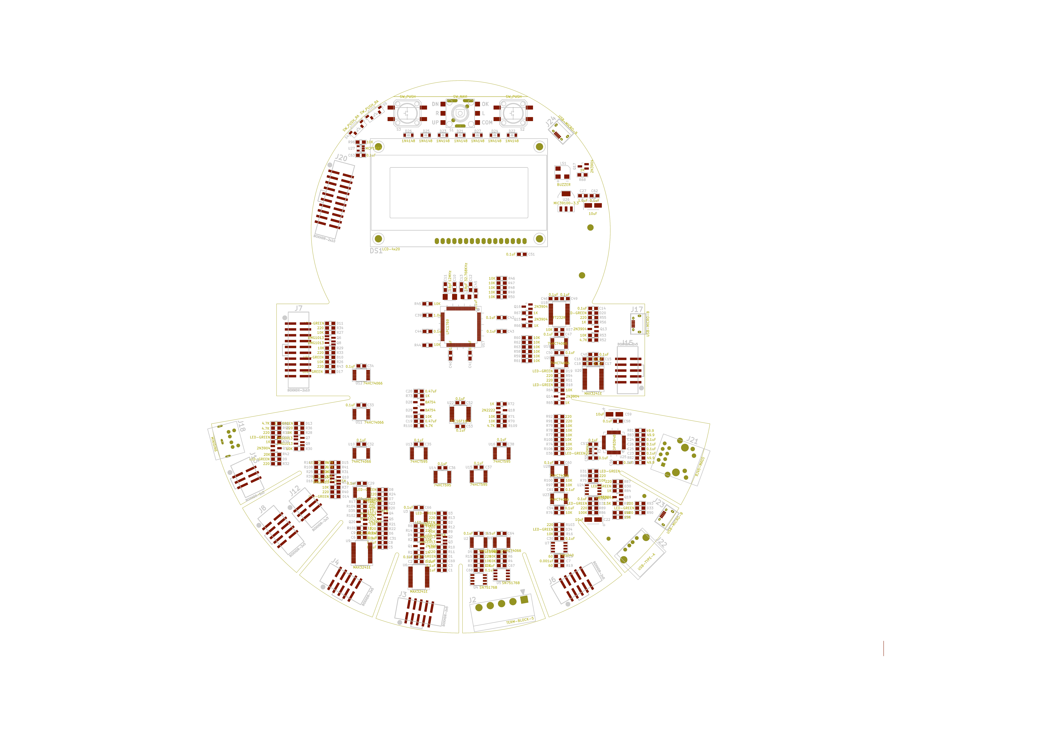
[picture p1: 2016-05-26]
docs/serial-squid-placement-top-draft2.png

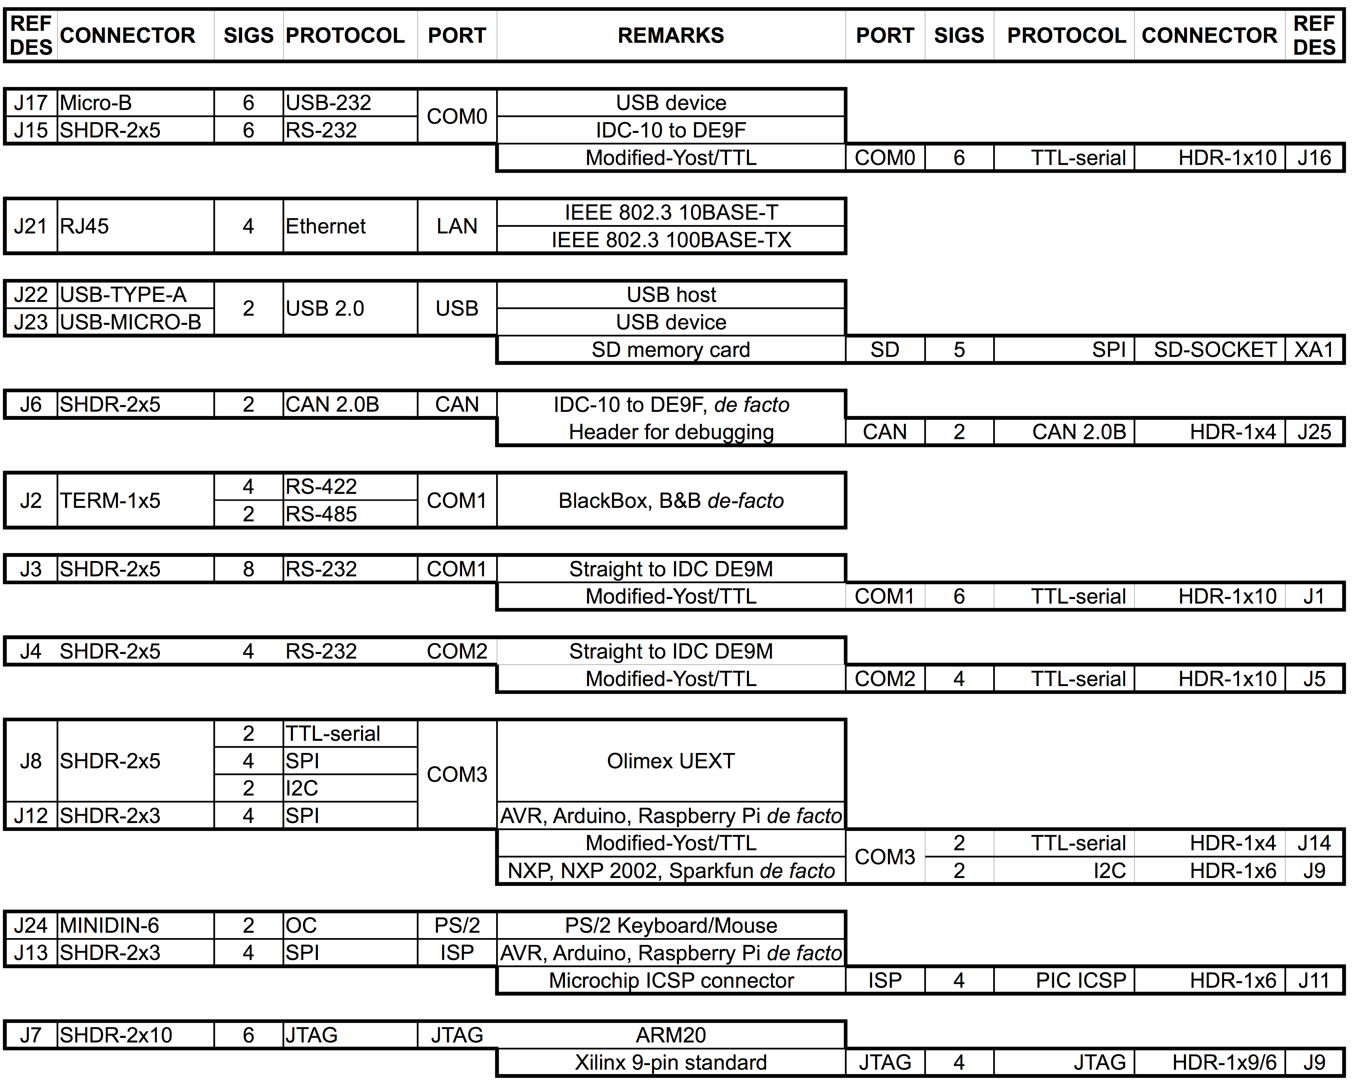
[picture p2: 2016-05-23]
docs/connector-figure.png

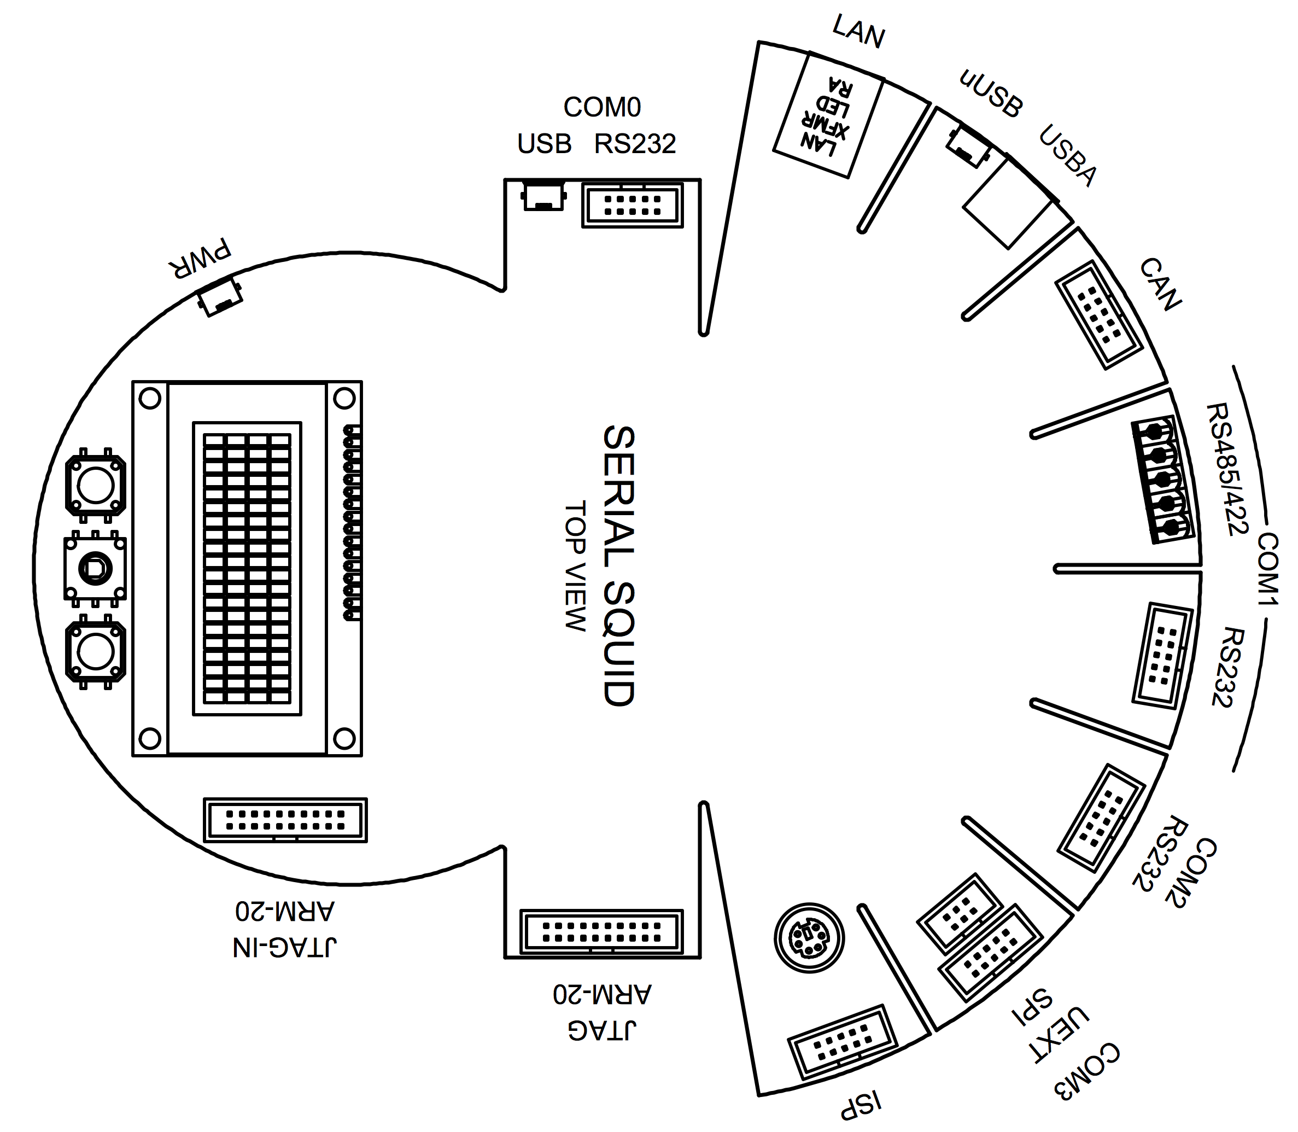
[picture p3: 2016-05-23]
docs/squid-drawing-top-view.png

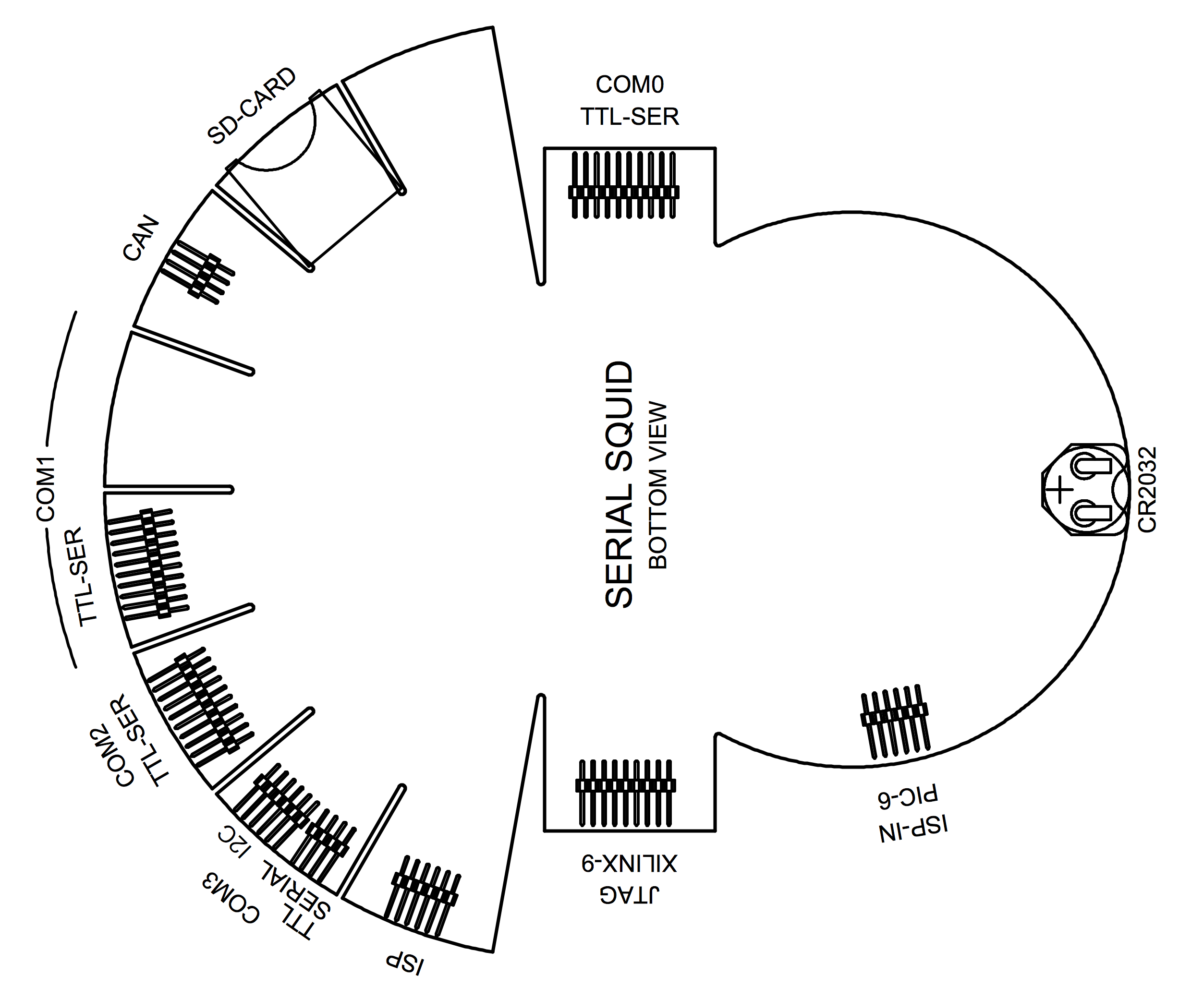
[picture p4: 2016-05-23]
docs/squid-drawing-bot-view.png

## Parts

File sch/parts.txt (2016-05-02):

      4       (libsource (lib my-74xx) (part 74HC595))
     11       (libsource (lib my-cmos4000) (part 4066))
      2       (libsource (lib my-conn) (part BOXHDR2x3))
      5       (libsource (lib my-conn) (part BOXHDR2x5))
      2       (libsource (lib my-conn) (part CONN_01X04))
      3       (libsource (lib my-conn) (part CONN_01X06))
      1       (libsource (lib my-conn) (part CONN_01X09))
      3       (libsource (lib my-conn) (part CONN_01X10))
      2       (libsource (lib my-conn) (part CONN_02X10))
      1       (libsource (lib my-conn) (part MINIDIN6))
      1       (libsource (lib my-conn) (part RJ45-XFMR-LEDS))
      1       (libsource (lib my-conn) (part SD_CARD_SOCKET))
      1       (libsource (lib my-conn) (part TERM-BLOCK-5))
      1       (libsource (lib my-conn) (part USB_A))
      3       (libsource (lib my-conn) (part USB_OTG))
      1       (libsource (lib my-device) (part COIN-BATT-SOCKET))
      3       (libsource (lib my-device) (part CP1_Small))
      2       (libsource (lib my-device) (part Crystal_Small))
     66       (libsource (lib my-device) (part C_Small))
      2       (libsource (lib my-device) (part D_Schottky_Small))
      7       (libsource (lib my-device) (part D_Small))
     27       (libsource (lib my-device) (part LED))
      1       (libsource (lib my-device) (part LM3526-L))
      1       (libsource (lib my-device) (part MCP1322))
      9       (libsource (lib my-device) (part Q_NPN))
     10       (libsource (lib my-device) (part Q_PMOS))
      1       (libsource (lib my-device) (part Q_PNP))
    110       (libsource (lib my-device) (part RES))
      1       (libsource (lib my-device) (part SPEAKER))
      1       (libsource (lib my-device) (part SW_NAVI))
      4       (libsource (lib my-device) (part SW_PUSH))
      1       (libsource (lib my-display) (part LCD4x20))
      1       (libsource (lib my-ftdi) (part FT232RL))
      2       (libsource (lib my-interface) (part 75LBC176))
      1       (libsource (lib my-interface) (part DP83848C))
      3       (libsource (lib my-maxim) (part MAX3241))
      1       (libsource (lib my-microchip) (part "PIC16(L)F628A-I/SS"))
      1       (libsource (lib my-nxp) (part LPC1769-SQUID))
      1       (libsource (lib my-nxp) (part TJA1040))
      1       (libsource (lib my-osc) (part SIT2001B))
      1       (libsource (lib my-regul) (part LT1129CST-3.3))

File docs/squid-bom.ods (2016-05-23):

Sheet: SQUID-BOM
SERIAL SQUID BOM
02-May-2016
 |  |  |  |  |  |  |  |  |  |  |  |  |  |  |  |  |  |  |  |  | $165.56 | $1,384.66 | $6,410.35 | $10,859.15 | $46,244.47 | $83,534.30
 |  |  |  |  |  |  |  |  |  |  |  |  |  |  |  |  |  |  |  |  | $165.56 | $138.47 | $128.21 | $108.59 | $92.49 | $83.53
 |  |  |  |  |  |  |  |  |  |  |  |  |  |  |  |  |  |  |  |  | 1 | 10 | 50 | 100 | 500 | 1000
ITEM | QTY | REF-DES | CODE | TYPE | MANUFACTURER | PART-NUMBER | VALUE | PACKAGE | MFR-PACKAGE | DESCRIPTION | REMARKS | VENDOR | VENDOR-PN | VENDOR-STOCK | UNIT-PR-1 | UNIT-PR-10 | UNIT-PR-50 | UNIT-PR-100 | UNIT-PR-500 | UNIT-PR-1000 | EXT-PR-1 | EXT-PR-10 | EXT-PR-50 | EXT-PR-100 | EXT-PR-500 | EXT-PR-1000
1 | 1 | U17 | IC | SMT | NXP SEMICONDUCTOR | LPC1769FBD100 (http://www.nxp.com/products/microcontrollers-and-processors/arm-processors/lpc-cortex-m-mcus/lpc-cortex-m3/lpc1700-series/512kb-flash-64kb-sram-ethernet-usb-l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) | LPC1769 | LQFP100 | SOT407-1 | IC, MCU, ARM Cortex-M3, 120MHZ, 512KB FLASH, 64KB RAM | @mcu | Digikey | 568-4966-ND (http://www.digikey.com/product-search/en/integrated-circuits-ics/embedded-microcontrollers/2556109?k=LPC1769) | 2,727 | 11.19000 | 10.10500 | 10.10500 | 8.36600 | 7.28500 | 6.34500 | 11.19000 | 10.10500 | 10.10500 | 8.36600 | 7.28500 | 6.34500
2 | 1 | U22 | IC | SMT | MICROCHIP | PIC16F1847-I/SS (http://www.microchip.com/wwwproducts/en/PIC16F1847) | PIC16F1847 | SSOP20 | SSOP20 | IC, MCU, PIC 8-bit, 32MHz, 14KB FLASH, 1KB RAM, 256B EEPROM | @mcu | Digikey | PIC16F1847-I/SS-ND (http://www.digikey.com/product-detail/en/microchip-technology/PIC16F1847-I/SS/PIC16F1847-I/SS-ND/2651382) | 1,121 | 1.50000 | 1.50000 | 1.38000 | 1.25000 | 1.25000 | 1.25000 | 1.50000 | 1.50000 | 1.38000 | 1.25000 | 1.25000 | 1.25000
3 | 1 | U27 | IC | SMT | MICROCHIP | MCP1322T-29LE/OT (http://www.microchip.com/wwwproducts/en/MCP1322) | MCP1322 | SOT23-5 | SOT23-5 | IC, Voltage Supervisor w/Reset Input | @mcu | Digikey | MCP1322T-29LE/OTCT-ND (http://www.digikey.com/product-detail/en/microchip-technology/MCP1322T-29LE%2FOT/MCP1322T-29LE%2FOTCT-ND/1979854) | 2,246 | 0.59000 | 0.59000 | 0.49000 | 0.45000 | 0.45000 | 0.45000 | 0.59000 | 0.59000 | 0.49000 | 0.45000 | 0.45000 | 0.45000
4 | 1 | U25 | IC | SMT | TEXAS INSTRUMENTS | DP83848CVV/NOPB (http://www.ti.com/product/DP83848C) | DP83848 | LQFP48 | PT48 | IC, Ethernet 10/100 Mb/s Physical Layer Interface | @lan | Digikey | DP83848CVVX/NOPBCT-ND (http://www.digikey.com/product-detail/en/texas-instruments/DP83848CVVX%2FNOPB/DP83848CVVX%2FNOPBCT-ND/3440156) | 15,391 | 5.28000 | 4.74100 | 4.74100 | 3.88940 | 3.30886 | 2.41875 | 5.28000 | 4.74100 | 4.74100 | 3.88940 | 3.30886 | 2.41875
5 | 1 | U18 | IC | SMT | FUTURE TECHNOLOGY | FT232RL (http://www.ftdichip.com/Products/ICs/FT232R.htm) | FT232R | SSOP28 | SSOP28 | IC, USB to Serial UART Interface | @com0 @com1 | Digikey | 768-1007-1-ND (http://www.digikey.com/product-detail/en/ftdi-future-technology-devices-international-ltd/FT232RL-REEL/768-1007-1-ND/1836402) | 145,278 | 4.50000 | 4.05000 | 3.85000 | 3.65000 | 2.85000 | 2.85000 | 4.50000 | 4.05000 | 3.85000 | 3.65000 | 2.85000 | 2.85000
6 | 3 | U6,U9,U20 | IC | SMT | MAXIM | MAX3241ECAI+ (https://www.maximintegrated.com/en/products/interface/transceivers/MAX3241E.html) | MAX3241E | SSOP28 | A28+1 | IC, Transceiver, RS-232, 2 Xmtr, 3 Rvcr | @com0, @com1, @com2 | Digikey | MAX3241ECAI+-ND (http://www.digikey.com/product-detail/en/maxim-integrated/MAX3241ECAI+/MAX3241ECAI+-ND/947913) | 889 | 6.83000 | 6.48900 | 5.85220 | 5.85220 | 5.85220 | 5.85220 | 20.49000 | 19.46700 | 17.55660 | 17.55660 | 17.55660 | 17.55660
7 | 2 | U4,U5 | IC | SMT | TEXAS INSTRUMENTS | DS75176BM/NOPB (http://www.ti.com/product/DS75176B) | SN75176B | SOIC8-150 | D8 | IC, Transceiver, RS-422, w/Enables | @com1 | Digikey | DS75176BMX/NOPBCT-ND (http://www.digikey.com/product-detail/en/texas-instruments/DS75176BMX%2FNOPB/DS75176BMX%2FNOPBCT-ND/1010512) | 22,832 | 1.41000 | 1.26500 | 1.26500 | 0.98590 | 0.81536 | 0.64448 | 2.82000 | 2.53000 | 2.53000 | 1.97180 | 1.63072 | 1.28896
8 | 1 | U7 | IC | SMT | NXP SEMICONDUCTOR | TJA1040T/CM (http://www.nxp.com/products/interface-and-connectivity/wired-connectivity/can-lin-flexray-transceivers/can-transceivers/high-speed-can-transceiver-with-standb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) | TJA1040 | SOIC8-150 | SOT96-1 | IC, XCVR, CAN, High-speed w/standby mode | @can | Digikey | 568-10289-1-ND (http://www.digikey.com/product-detail/en/nxp-semiconductors/TJA1040T%2FCM,118/568-10289-1-ND/4162434) | 29,851 | 1.25000 | 1.11400 | 1.11400 | 0.86840 | 0.71814 | 0.56792 | 1.25000 | 1.11400 | 1.11400 | 0.86840 | 0.71814 | 0.56792
9 | 11 | U1-U3,U8,U10-U12,U19,U21,U23,U28 | IC | SMT | NXP SEMICONDUCTOR | 74HCT4066PW (http://www.nxp.com/products/discretes-and-logic/logic/quad-single-pole-single-throw-analog-switch:74HCT4066PW) | 74HCT4066 | TSSOP14 | SOT402-1 | IC, CMOS Quad Bilateral Switch | @com0=2 @com1=3, @com2=1, @com3=1.5, @jtag=1.5, @usb=1, @sd=1 | Digikey | 568-8177-1-ND (http://www.digikey.com/product-detail/en/nxp-semiconductors/74HCT4066D,118/568-8177-1-ND/2762867) | 5,280 | 0.45000 | 0.36800 | 0.36800 | 0.25080 | 0.18772 | 0.14060 | 4.95000 | 4.04800 | 4.04800 | 2.75880 | 2.06492 | 1.54660
10 | 4 | U13-U16 | IC | SMT | NXP SEMICONDUCTOR | 74HCT595PW (http://www.nxp.com/products/discretes-and-logic/logic/8-bit-serial-in-serial-or-parallel-out-shift-register-with-output-latches-3-state:74HCT595PW) | 74HCT595 | TSSOP16 | SOT403-1 | IC, Shift Register, 8-bit, Serial in, Serial and Parallel Out, w/Latches | @config | Digikey | 568-1561-1-ND (http://www.digikey.com/product-detail/en/nxp-semiconductors/74HCT595PW,118/568-1561-1-ND/763414) | 23,450 | 0.89000 | 0.80000 | 0.80000 | 0.62380 | 0.51588 | 0.40796 | 3.56000 | 3.20000 | 3.20000 | 2.49520 | 2.06352 | 1.63184
11 | 1 | U24 | IC | SMT | NATIONAL (TI) | LM3526M-L/NOPB (http://www.ti.com/product/LM3526) | LM3526-L | SOIC8 | D8 | IC, USB HOST POWER SWITCH, OVER CURRENT PROTECTION | @usb | Digikey | LM3526M-L/NOPB-ND (http://www.digikey.com/product-detail/en/texas-instruments/LM3526M-L/NOPB/LM3526M-L/NOPB-ND/363944) | 3,049 | 1.90000 | 1.70400 | 1.70400 | 1.36960 | 1.12526 | 0.93235 | 1.90000 | 1.70400 | 1.70400 | 1.36960 | 1.12526 | 0.93235
12 | 1 | U26 | IC | SMT | MICREL (MICROCHIP) | MIC39100-3.3WS (http://www.microchip.com/wwwproducts/en/MIC39100) | MIC39100-3.3 | SOT-223 | SOT-223 | IC, VOLTAGE REGULATOR, LDO, 1A, 3.3V FIXED | @power | Digikey | 576-1172-ND (http://www.digikey.com/product-detail/en/microchip-technology/MIC39100-3.3WS/576-1172-ND/771641) | 4,097 | 1.40000 | 1.40000 | 1.16000 | 1.06000 | 1.06000 | 1.06000 | 1.40000 | 1.40000 | 1.16000 | 1.06000 | 1.06000 | 1.06000
13 | 7 | D21-D27 | SEM | SMT | FAIRCHILD SEMI | MMBD4148 (https://www.fairchildsemi.com/products/discretes/diodes-rectifiers/small-signal-diodes/MMBD4148.html) | 1N4148 | SOT-23 | SOT-23-3L | DIODE, SMALL SIGNAL, 1N4148, 200mA, 100V, SMD |  | Digikey | MMBD4148FSCT (http://www.digikey.com/product-detail/en/fairchild-semiconductor/MMBD4148/MMBD4148FSCT-ND/458965) | 109,221 | 0.19000 | 0.17000 | 0.17000 | 0.09290 | 0.05708 | 0.03893 | 1.33000 | 1.19000 | 1.19000 | 0.65030 | 0.39956 | 0.27251
14 | 2 | D28,D29 | SEM | SMT | DIODES INC | BAT54-7-F (http://www.diodes.com/catalog/Schottky_(Less_than_.5A)_3/BAT54_2945) | BAT54 | SOT-23 | SOT-23 | DIODE, SCHOTTKY, 200mA, 30V |  | Digikey | BAT54-FDICT-ND (http://www.digikey.com/product-detail/en/diodes-incorporated/BAT54-7-F/BAT54-FDICT-ND/717819) | 88,219 | 0.15000 | 0.13500 | 0.13500 | 0.07370 | 0.04530 | 0.03090 | 0.30000 | 0.27000 | 0.27000 | 0.14740 | 0.09060 | 0.06180
15 | 27 | D1-D20,D30-D36 | SEM | SMT | LITE-ON | LTST-C170KGKT (http://optoelectronics.liteon.com/en-global/Led/LED-Component/Detail/449/0/LTST-C170KGKT) | LED-GREEN | EIA0805 | EIA0805 | LED, GREEN, SMT, TOP VIEW, 35mcd @ 20mA |  | Digikey | 160-1414-1-ND (http://www.digikey.com/product-search/en?keywords=160-1414-1-ND) | 718,943 | 0.38000 | 0.29600 | 0.29600 | 0.16140 | 0.09146 | 0.06994 | 10.26000 | 7.99200 | 7.99200 | 4.35780 | 2.46942 | 1.88838
16 | 8 | Q1,Q12-Q17,Q20 | SEM | SMT | DIODES INC | MMBT3904-7-F (http://www.diodes.com/catalog/Transistors_30V_to_50V_111/MMBT3904_6170) | 2N3904 | SOT-23 | SOT-23 | TRANSISTOR, NPN, 2N3906, 40V @ 200mA, SMT |  | Digikey | MMBT3904-FDICT-ND (http://search.digikey.com/scripts/DkSearch/dksus.dll?Detail&name=MMBT3904-FDICT-ND) | 588,937 | 0.12000 | 0.10800 | 0.10800 | 0.05900 | 0.03624 | 0.02472 | 0.96000 | 0.86400 | 0.86400 | 0.47200 | 0.28992 | 0.19776
17 | 1 | Q19 | SEM | SMT | DIODES INC | MMBT3906-7-F (http://www.diodes.com/catalog/Transistors_30V_to_50V_111/MMBT3906_7186) | 2N3906 | SOT-23 | SOT-23 | TRANSISTOR, PNP, 2N3906, 40V @ 200mA, SMT |  | Digikey | MMBT3906-FDICT-ND (http://search.digikey.com/scripts/DkSearch/dksus.dll?Detail&name=MMBT3906-FDICT-ND) | 223,756 | 0.12000 | 0.10800 | 0.10800 | 0.05900 | 0.03624 | 0.02472 | 0.12000 | 0.10800 | 0.10800 | 0.05900 | 0.03624 | 0.02472
18 | 1 | Q18 | SEM | SMT | DIODES INC | MMBT2222A-7-F (http://www.diodes.com/catalog/Transistors_30V_to_50V_111/MMBT2222A_6168) | 2N2222 | SOT-23 | SOT-23 | TRANSISTOR, NPN, 2N2222A, 40V @ 600mA, SMT |  | Digikey | MMBT2222A-FDICT-ND (http://www.digikey.com/product-detail/en/diodes-incorporated/MMBT2222A-7-F/MMBT2222A-FDICT-ND/815723) | 476,496 | 0.13000 | 0.12200 | 0.12200 | 0.06630 | 0.04078 | 0.02781 | 0.13000 | 0.12200 | 0.12200 | 0.06630 | 0.04078 | 0.02781
19 | 10 | Q2-Q11 | SEM | SMT | DIODES INC | DMG1013UW-7 (http://www.diodes.com/catalog/P_Channel_8V_to_29V_105/DMG1013UW_5661) | DMG1013 | SOT-323 | SOT-323 | TRANSISTOR, MOSFET, P-CHAN, 20V @ 800mA, SMT |  | Digikey | DMG1013UW-7DICT-ND (http://www.digikey.com/product-detail/en/diodes-incorporated/DMG1013UW-7/DMG1013UW-7DICT-ND/2183252) | 61,614 | 0.34000 | 0.27000 | 0.27000 | 0.14680 | 0.09650 | 0.06575 | 3.40000 | 2.70000 | 2.70000 | 1.46800 | 0.96500 | 0.65750
20 | 1 | Y1 | OSC | SMT | CTS FREQUENCY | 445C35A12M00000 (http://www.ctscorp.com/connect_product_line/crystals/?fwp_search=445) | 12.000MHZ | CTS-5x3.2 | CTS-5x3.2 | CRYSTAL, QUARTZ, 12.000 MHZ, 10pf LOAD, 50 OHM, SMD |  | Digikey | CTX1435CT-ND (http://www.digikey.com/product-detail/en/cts-frequency-controls/445C35A12M00000/CTX1435CT-ND/5875920) | 2,000 | 0.66000 | 0.55200 | 0.49560 | 0.44100 | 0.42000 | 0.42000 | 0.66000 | 0.55200 | 0.49560 | 0.44100 | 0.42000 | 0.42000
21 | 1 | Y2 | OSC | SMT | CTS FREQUENCY | TF322P32K7680 (http://www.ctscorp.com/connect_product_line/crystals/?fwp_crystal_freq=0.032768) | 32.768KHZ | CTS-3.2x1.5 | CTS-3.2x1.5 | CRYSTAL, QUARTZ, 32.768 KHZ, 12.5pF LOAD, 70K OHM, SMD |  | Digikey | CTX1160CT-ND (http://www.digikey.com/product-detail/en/cts-frequency-controls/TF322P32K7680/CTX1160CT-ND/2809783) | 8,353 | 1.17000 | 1.04100 | 0.97100 | 0.86000 | 0.81270 | 0.67940 | 1.17000 | 1.04100 | 0.97100 | 0.86000 | 0.81270 | 0.67940
22 | 1 | Y3 | OSC | SMT | SITIME | SIT2001BI-S2-33E-50.000000G (http://www.sitime.com/products/clock-generators/sit2001) | 50MHz | SOT23-5 | SOT23-5 | Oscillator, CMOS, 3.3V, 50MHz |  | Digikey | 1473-1346-1-ND (http://www.digikey.com/product-detail/en/sitime/SIT2001BI-S2-33E-50.000000G/1473-1346-1-ND/5824455) | 237 | 0.86000 | 0.76000 | 0.71000 | 0.62830 | 0.56548 | 0.53407 | 0.86000 | 0.76000 | 0.71000 | 0.62830 | 0.56548 | 0.53407
23 | 1 | LS1 | BUZ | SMT | CUI-STACK | CSS-0575A-SMT (http://www.cui.com/product/components/buzzers/audio-transducers/magnetic/css-0575a-smt) | BUZZER | CSS-0575A-SMT | CSS-0575A-SMT | Buzzer, Magnetic, Audio, 3V, 75dBA |  | Digikey | 102-2201-1-ND (http://www.digikey.com/product-detail/en/cui-inc/CSS-0575A-SMT-TR/102-2201-1-ND/2364650) | 20,423 | 3.67000 | 3.03600 | 3.03600 | 2.27700 | 1.89750 | 1.69050 | 3.67000 | 3.03600 | 3.03600 | 2.27700 | 1.89750 | 1.69050
24 | 1 | C7 | CAP | SMT | KEMET | C0805C102K5RACTU (http://www.kemet.com/kemet/web/homepage/kechome.nsf/vapubfiles/KEM_C1002_X7R_SMD.pdf/$file/KEM_C1002_X7R_SMD.pdf) | 0.001uF | EIA0805 | EIA0805 | CAPACITOR, CERAMIC, EIA0805/2012, 0.001UF, X7R, 50V |  | Digikey | 399-1147-1-ND (http://www.digikey.com/product-detail/en/kemet/C0805C102K5RACTU/399-1147-1-ND/411422) | 552,291 | 0.10000 | 0.03700 | 0.02020 | 0.01710 | 0.01194 | 0.00930 | 0.10000 | 0.03700 | 0.02020 | 0.01710 | 0.01194 | 0.00930
25 | 57 | C1-C6,C8-C9,C14-C18,C21,C23-C26,C29-C38,C40-C58,C60-C69 | CAP | SMT | KEMET | C0805C104K5RACTU (http://www.kemet.com/kemet/web/homepage/kechome.nsf/vapubfiles/KEM_C1002_X7R_SMD.pdf/$file/KEM_C1002_X7R_SMD.pdf) | 0.1uF | EIA0805 | EIA0805 | CAPACITOR, CERAMIC, EIA0805/2012, 0.1UF, X7R, 50V |  | Digikey | 399-1170-1-ND (http://search.digikey.com/scripts/DkSearch/dksus.dll?Detail&name=399-1170-1-ND) | 1,747,727 | 0.10000 | 0.04800 | 0.02600 | 0.02200 | 0.01540 | 0.01200 | 5.70000 | 2.73600 | 1.48200 | 1.25400 | 0.87780 | 0.68400
26 | 2 | C19,C20 | CAP | SMT | KEMET | C0805C474K5RACTU (http://www.kemet.com/kemet/web/homepage/kechome.nsf/vapubfiles/KEM_C1002_X7R_SMD.pdf/$file/KEM_C1002_X7R_SMD.pdf) | 0.47uF | EIA0805 | EIA0805 | CAPACITOR, CERAMIC, EIA0805/2012, 0.47UF, X7R, 50V |  | Digikey | 399-8100-1-ND (http://www.digikey.com/product-detail/en/kemet/C0805C474K5RACTU/399-8100-1-ND/3471823) | 15,588 | 0.24000 | 0.20300 | 0.11440 | 0.10160 | 0.06732 | 0.05969 | 0.48000 | 0.40600 | 0.22880 | 0.20320 | 0.13464 | 0.11938
27 | 2 | C27,C39 | CAP | SMT | KEMET | C0805C105K5RACTU (http://www.kemet.com/kemet/web/homepage/kechome.nsf/vapubfiles/KEM_C1002_X7R_SMD.pdf/$file/KEM_C1002_X7R_SMD.pdf) | 1.0uF | EIA0805 | EIA0805 | CAPACITOR, CERAMIC, EIA0805/2012, 0.47UF, X7R, 50V |  | Digikey | 399-7409-1-ND (http://www.digikey.com/product-detail/en/kemet/C0805C105K5RACTU/399-7409-1-ND/3317443) | 95,226 | 0.34000 | 0.28000 | 0.15760 | 0.14000 | 0.09276 | 0.08225 | 0.68000 | 0.56000 | 0.31520 | 0.28000 | 0.18552 | 0.16450
28 | 4 | C10-C13 | CAP | SMT | KEMET | C0805C180J5GACTU (http://www.kemet.com/Lists/ProductCatalog/Attachments/46/KEM_C1003_C0G_SMD.pdf) | 18pF | EIA0805 | EIA0805 | CAPACITOR, CERAMIC, EIA0805/2012, 18PF, C0G, 50V |  | Digikey | 399-1112-1-ND (http://search.digikey.com/scripts/DkSearch/dksus.dll?Detail&name=399-1112-1-ND) | 57,435 | 0.11000 | 0.08200 | 0.04420 | 0.03740 | 0.02618 | 0.02040 | 0.44000 | 0.32800 | 0.17680 | 0.14960 | 0.10472 | 0.08160
29 | 3 | C22,C28,C59 | CAP | SMT | KEMET | T494B106M016AT (http://www.kemet.com/Lists/ProductCatalog/Attachments/256/KEM_T2008_T494.pdf) | 10uF | EIA1210 | CASE-B | CAPACITOR, TANTALUM, 10uF, 16V, Case C, SMD |  | Digikey | 399-8446-1-ND (http://www.digikey.com/product-detail/en/kemet/T494B106M016AT/399-8446-1-ND/3472169) | 3,504 | 1.05000 | 0.87900 | 0.71060 | 0.56100 | 0.42076 | 0.38355 | 3.15000 | 2.63700 | 2.13180 | 1.68300 | 1.26228 | 1.15065
30 | 4 | R80-R83 | RES | SMT | ROHM | MCR10ERTF49R9 (http://rohmfs.rohm.com/en/products/databook/datasheet/passive/resistor/chip_resistor/mcr_g.pdf) | 49R9 | EIA0805 | EIA0805 | RESISTOR, THICK FILM, EIA0805/2012, 49.9 OHMS, 1%, 1/4W, SMD |  | Digikey | RHM49.9CHCT-ND (http://www.digikey.com/product-detail/en/rohm-semiconductor/MCR10ERTF49R9/RHM49.9CHCT-ND/2796535) | 23,040 | 0.10000 | 0.02700 | 0.01960 | 0.01090 | 0.00666 | 0.00490 | 0.40000 | 0.10800 | 0.07840 | 0.04360 | 0.02664 | 0.01960
31 | 2 | R18,R19 | RES | SMT | ROHM | MCR10ERTF59R0 (http://rohmfs.rohm.com/en/products/databook/datasheet/passive/resistor/chip_resistor/mcr_g.pdf) | 59R0 | EIA0805 | EIA0805 | RESISTOR, THICK FILM, EIA0805/2012, 59.0 OHMS, 1%, 1/4W, SMD |  | Digikey | RHM59CHCT-ND (http://www.digikey.com/product-detail/en/rohm-semiconductor/MCR10ERTF59R0/RHM59CHCT-ND/4084925) | 3,860 | 0.10000 | 0.02700 | 0.01960 | 0.01090 | 0.00666 | 0.00490 | 0.20000 | 0.05400 | 0.03920 | 0.02180 | 0.01332 | 0.00980
32 | 30 | R11-R15,R22-R24,R32-R36,R39-R41,R43,R51,R54-R55,R87-R93,R103-R104,R106 | RES | SMT | ROHM | MCR10ERTF2210 (http://rohmfs.rohm.com/en/products/databook/datasheet/passive/resistor/chip_resistor/mcr_g.pdf) | 221 | EIA0805 | EIA0805 | RESISTOR, THICK FILM, EIA0805/2012, 221 OHMS, 1%, 1/4W, SMD |  | Digikey | RHM221CHCT-ND (http://www.digikey.com/product-detail/en/rohm-semiconductor/MCR10ERTF2210/RHM221CHCT-ND/4084676) | 8,970 | 0.10000 | 0.02700 | 0.01960 | 0.01090 | 0.00666 | 0.00490 | 3.00000 | 0.81000 | 0.58800 | 0.32700 | 0.19980 | 0.14700
33 | 11 | R1,R38,R56,R65-R68,R72-R73,R84,R101 | RES | SMT | ROHM | MCR10ERTF1001 (http://rohmfs.rohm.com/en/products/databook/datasheet/passive/resistor/chip_resistor/mcr_g.pdf) | 1.00K | EIA0805 | EIA0805 | RESISTOR, THICK FILM, EIA0805/2012, 1.00K OHMS, 1%, 1/4W, SMD |  | Digikey | RHM1.00KCHCT-ND (http://www.digikey.com/product-detail/en/rohm-semiconductor/MCR10ERTF1001/RHM1.00KCHCT-ND/2796512) | 2,102 | 0.10000 | 0.02700 | 0.01960 | 0.01090 | 0.00666 | 0.00490 | 1.10000 | 0.29700 | 0.21560 | 0.11990 | 0.07326 | 0.05390
34 | 1 | R85 | RES | SMT | ROHM | MCR10ERTF1501 (http://rohmfs.rohm.com/en/products/databook/datasheet/passive/resistor/chip_resistor/mcr_g.pdf) | 1.50K | EIA0805 | EIA0805 | RESISTOR, THICK FILM, EIA0805/2012, 1.50K OHMS, 1%, 1/4W, SMD |  | Digikey | RHM1.5KCHCT-ND (http://www.digikey.com/product-detail/en/rohm-semiconductor/MCR10ERTF1501/RHM1.5KCHCT-ND/4084574) | 18,449 | 0.10000 | 0.02700 | 0.01960 | 0.01090 | 0.00666 | 0.00490 | 0.10000 | 0.02700 | 0.01960 | 0.01090 | 0.00666 | 0.00490
35 | 7 | R52,R98-R99,R107-R110 | RES | SMT | ROHM | MCR10ERTF4751 (http://rohmfs.rohm.com/en/products/databook/datasheet/passive/resistor/chip_resistor/mcr_g.pdf) | 4.75K | EIA0805 | EIA0805 | RESISTOR, THICK FILM, EIA0805/2012, 4.75K OHMS, 1%, 1/4W, SMD |  | Digikey | RHM4.75KCHCT-ND (http://www.digikey.com/product-detail/en/rohm-semiconductor/MCR10ERTF4751/RHM4.75KCHCT-ND/4084869) | 5,189 | 0.10000 | 0.02700 | 0.01960 | 0.01090 | 0.00666 | 0.00490 | 0.70000 | 0.18900 | 0.13720 | 0.07630 | 0.04662 | 0.03430
36 | 51 | R2-R10,R16-R17,R20-R21,R25-R31,R37,R44-R50,R53,R57-R64,R69-R71,R74-R79,R96-R97,R100,R102,R105 | RES | SMT | ROHM | MCR10ERTF1002 (http://rohmfs.rohm.com/en/products/databook/datasheet/passive/resistor/chip_resistor/mcr_g.pdf) | 10.0K | EIA0805 | EIA0805 | RESISTOR, THICK FILM, EIA0805/2012, 10.0K OHMS, 1%, 1/4W, SMD |  | Digikey | RHM10.0KCHCT-ND (http://www.digikey.com/product-detail/en/rohm-semiconductor/MCR10ERTF1002/RHM10.0KCHCT-ND/2796513) | 88,449 | 0.10000 | 0.02700 | 0.01960 | 0.01090 | 0.00666 | 0.00490 | 5.10000 | 1.37700 | 0.99960 | 0.55590 | 0.33966 | 0.24990
37 | 2 | R94,R95 | RES | SMT | ROHM | MCR10ERTF1502 (http://rohmfs.rohm.com/en/products/databook/datasheet/passive/resistor/chip_resistor/mcr_g.pdf) | 15.0K | EIA0805 | EIA0805 | RESISTOR, THICK FILM, EIA0805/2012, 15.0K OHMS, 1%, 1/4W, SMD |  | Digikey | RHM15.0KCHCT-ND (http://www.digikey.com/product-detail/en/rohm-semiconductor/MCR10ERTF1502/RHM15.0KCHCT-ND/2796518) | 19,538 | 0.10000 | 0.02700 | 0.01960 | 0.01090 | 0.00666 | 0.00490 | 0.20000 | 0.05400 | 0.03920 | 0.02180 | 0.01332 | 0.00980
38 | 1 | R42 | RES | SMT | ROHM | MCR10ERTF2002 (http://rohmfs.rohm.com/en/products/databook/datasheet/passive/resistor/chip_resistor/mcr_g.pdf) | 20.0K | EIA0805 | EIA0805 | RESISTOR, THICK FILM, EIA0805/2012, 20.0K OHMS, 1%, 1/4W, SMD |  | Digikey | RHM20.0KCHCT-ND (http://www.digikey.com/product-detail/en/rohm-semiconductor/MCR10ERTF2002/RHM20.0KCHCT-ND/2796521) | 11,839 | 0.10000 | 0.02700 | 0.01960 | 0.01090 | 0.00666 | 0.00490 | 0.10000 | 0.02700 | 0.01960 | 0.01090 | 0.00666 | 0.00490
39 | 1 | R86 | RES | SMT | ROHM | MCR10ERTF1003 (http://rohmfs.rohm.com/en/products/databook/datasheet/passive/resistor/chip_resistor/mcr_g.pdf) | 100K | EIA0805 | EIA0805 | RESISTOR, THICK FILM, EIA0805/2012, 100.0K OHMS, 1%, 1/4W, SMD |  | Digikey | RHM100KCHCT-ND (http://www.digikey.com/product-detail/en/rohm-semiconductor/MCR10ERTF1003/RHM100KCHCT-ND/2796514) | 18,172 | 0.10000 | 0.02700 | 0.01960 | 0.01090 | 0.00666 | 0.00490 | 0.10000 | 0.02700 | 0.01960 | 0.01090 | 0.00666 | 0.00490
40 | 1 | XA1 | CON | SMT | E-SWITCH | 101-00313-68-02 (https://www.amphenolcanada.com/SelectPartNum.aspx?Series=10100313) | SD-SOCKET | SD-SOCKET | SD-SOCKET | CONNECTOR, SOCKET, SD MEMORY CARD, SMD |  | Digikey | 101-00313-68-02CT-ND (http://www.digikey.com/product-detail/en/amphenol-commercial-products/101-00313-68-02/101-00313-68-02CT-ND/2540683) | 3,736 | 2.33000 | 2.11000 | 1.89480 | 1.80870 | 1.48772 | 1.48772 | 2.33000 | 2.11000 | 1.89480 | 1.80870 | 1.48772 | 1.48772
41 | 1 | J21 | CON | THRU | PULSE ELECTRONICS | J0011D01BNL (http://productfinder.pulseeng.com/product/J0011D01BNL) | RJ45-MAGS | RJ45-MAGS | RJ45-MAGS | Connector, Ethernet, 100 Base-TX w/LEDs, Integrated Transformer |  | Digikey | 553-1483-ND (http://www.digikey.com/product-search/en?keywords=J0011D01BNL) | 4,526 | 7.92000 | 7.59000 | 6.60000 | 6.27000 | 5.28000 | 4.62000 | 7.92000 | 7.59000 | 6.60000 | 6.27000 | 5.28000 | 4.62000
42 | 1 | J22 | CON | SMT | CNC TECH | 1003-002-01100 (http://www.cnctech.us/productdetails.asp?ID=1708) | USB-TYPE-A | USB-TYPE-A | USB-TYPE-A | CONNECTOR, USB JACK, TYPE A, SMD |  | Digikey | 1175-1267-ND (http://www.digikey.com/product-search/en?keywords=1003-002-01100) | 1,928 | 1.89000 | 1.71500 | 1.54000 | 1.47000 | 1.22500 | 1.05000 | 1.89000 | 1.71500 | 1.54000 | 1.47000 | 1.22500 | 1.05000
43 | 3 | J17,J23,J24 | CON | SMT | AMPHENOL FCI | 10104110-0001LF (http://www.fci.com/en/products/input-output-connectors/usb-connectors/usb-2-0/micro-usb.html) | USB-MICRO-B | USB-MICRO-B | USB-MICRO-B | CONNECTOR, USB JACK, MICRO, TYPE B, SMD |  | Digikey | 609-4052-1-ND (http://www.digikey.com/product-detail/en/amphenol-fci/10104110-0001LF/609-4052-1-ND/2350358) | 25,515 | 0.79000 | 0.74200 | 0.59340 | 0.56870 | 0.49456 | 0.49456 | 2.37000 | 2.22600 | 1.78020 | 1.70610 | 1.48368 | 1.48368
44 | 1 | J18 | CON | THRU | CUI-STACK | MD-06SV (http://www.cui.com/product/components/connectors/din/mini-circular/vertical-pcb-receptacle/md-xxsv-series) | MINIDIN-6 | MINIDIN-6 | MINIDIN-6 | Connector, Mini DIN, 6 pos'n, Jack, Vertical Mount |  | Digikey | CP-2760-ND (http://www.digikey.com/product-search/en?keywords=MD60SV) | 13,663 | 1.71000 | 1.32500 | 1.32500 | 1.01030 | 0.80820 | 0.71840 | 1.71000 | 1.32500 | 1.32500 | 1.01030 | 0.80820 | 0.71840
45 | 1 | XBT1 | CON | SMT | KEYSTONE ELECTRONICS | 3003 (http://www.keyelco.com/product.cfm/product_id/780) | CR2032-SOCKET | CR2032-SOCKET | CR2032-SOCKET | Socket, Coin Cell, CR2032 size, SMT |  | Digikey | 36-3003-ND (http://www.digikey.com/product-search/en/battery-products/battery-holders-clips-contacts/393250?k=3003) | 78,262 | 0.60000 | 0.55800 | 0.55160 | 0.42800 | 0.37220 | 0.31265 | 0.60000 | 0.55800 | 0.55160 | 0.42800 | 0.37220 | 0.31265
46 | 1 | J2 | CON | THRU | TYCO ELECTRONICS | 796644-5 (http://www.te.com/usa-en/product-796644-5.html) | TERM-BLOCK-5 | TERM-BLOCK-5 | TERM-BLOCK-5 | Connector, 5mm Terminal Block, Right Angle, Receptacle, 5-pos'n |  | Digikey | A98438-ND (http://www.digikey.com/product-search/en/connectors-interconnects/terminal-blocks-headers-plugs-and-sockets/1442750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) | 1,594 | 1.90000 | 1.43700 | 1.19760 | 1.16850 | 0.93478 | 0.84715 | 1.90000 | 1.43700 | 1.19760 | 1.16850 | 0.93478 | 0.84715
47 | 2 | J7,J20 | CON | SMT | CNC TECH | 3020-20-0300-00 (http://cnctech.us/productdetails.asp?ID=2256) | BOXHDR-2x10 | BOXHDR-2x10-STR-SMD | BOXHDR2x10-STR-SMD | Header, Shrouded, Straight, 2x10 pos'n, 0.1 in pitch, SMD |  | Digikey | 1175-1623-ND (http://www.digikey.com/product-search/en?keywords=3020-20-0300-00) | 10,299 | 0.74000 | 0.69000 | 0.55200 | 0.52900 | 0.46000 | 0.37950 | 1.48000 | 1.38000 | 1.10400 | 1.05800 | 0.92000 | 0.75900
48 | 5 | J3,J4,J6,J8,J15 | CON | SMT | CNC TECH | 3020-10-0300-00 (http://cnctech.us/productdetails.asp?ID=2256) | BOXHDR-2x5 | BOXHDR-2x5-STR-SMD | BOXHDR2x5-STR-SMD | Header, Shrouded, Straight, 2x5 pos'n, 0.1 in pitch, SMD |  | Digikey | 1175-1621-ND (http://www.digikey.com/product-search/en?keywords=3020-10-0300-00) | 21,160 | 0.48000 | 0.45000 | 0.36000 | 0.34500 | 0.30000 | 0.24750 | 2.40000 | 2.25000 | 1.80000 | 1.72500 | 1.50000 | 1.23750
49 | 2 | J12,J13 | CON | SMT | CNC TECH | 3020-06-0300-00 (http://cnctech.us/productdetails.asp?ID=2251) | BOXHDR-2x3 | BOXHDR-2x3-STR-SMD | BOXHDR2x3-STR-SMD | Header, Shrouded, Straight, 2x3 pos'n, 0.1 in pitch, SMD |  | Digikey | 3020-06-0300-00-ND (http://www.digikey.com/product-detail/en/cnc-tech/3020-06-0300-00/3020-06-0300-00-ND/3883217) | 0 | 0.48000 | 0.45000 | 0.36000 | 0.34500 | 0.30000 | 0.24750 | 0.96000 | 0.90000 | 0.72000 | 0.69000 | 0.60000 | 0.49500
50 | 3 | J1,J5,j16 | CON | SMT | SULLINS | GBC10SGSN-M89 (http://www.sullinscorp.com/category98/GBC10SGSN-M89/) | HDR-1x10 | HDR-1x10-RA-SMD | HDR1x10-RA-SMD | Header, Right Angle, 1x10 pos'n, 2.54 mm pitch, 5.84 mm pin |  | Digikey | S1143E-10-ND (http://www.digikey.com/product-detail/en/sullins-connector-solutions/GBC10SGSN-M89/S1143E-10-ND/862381) | 0 | 2.01000 | 1.80200 | 1.80200 | 1.48370 | 1.17280 | 1.00676 | 6.03000 | 5.40600 | 5.40600 | 4.45110 | 3.51840 | 3.02028
51 | 1 | J10 | CON | SMT | SULLINS | GBC09SGSN-M89 (http://www.sullinscorp.com/category98/GBC09SGSN-M89/) | HDR-1x9 | HDR-1x9-RA-SMD | HDR1x9-RA-SMD | Header, Right Angle, 1x9 pos'n, 2.54 mm pitch, 5.84 mm pin |  | Digikey | S1143E-09-ND (http://www.digikey.com/product-detail/en/sullins-connector-solutions/GBC09SGSN-M89/S1143E-09-ND/862382) | 0 | 1.89000 | 1.69500 | 1.69500 | 1.39600 | 1.10356 | 0.94374 | 1.89000 | 1.69500 | 1.69500 | 1.39600 | 1.10356 | 0.94374
52 | 3 | J9,J11,J19 | CON | SMT | SULLINS | GBC06SGSN-M89 (http://www.sullinscorp.com/category98/GBC06SGSN-M89/) | HDR-1x6 | HDR-1x6-RA-SMD | HDR1x6-RA-SMD | Header, Right Angle, 1x6 pos'n, 2.54 mm pitch, 5.84 mm pin |  | Digikey | S1143E-06-ND (http://www.digikey.com/product-detail/en/sullins-connector-solutions/GBC06SGSN-M89/S1143E-06-ND/862385) | 0 | 1.54000 | 1.37600 | 1.37600 | 1.13340 | 0.89590 | 0.76907 | 4.62000 | 4.12800 | 4.12800 | 3.40020 | 2.68770 | 2.30721
53 | 2 | J14,J25 | CON | SMT | SULLINS | GBC04SGSN-M89 (http://www.sullinscorp.com/category98/GBC04SGSN-M89/) | HDR-1x4 | HDR-1x4-RA-SMD | HDR1x4-RA-SMD | Header, Right Angle, 1x4 pos'n, 2.54 mm pitch, 5.84 mm pin |  | Digikey | S1143E-04-ND (http://www.digikey.com/product-detail/en/sullins-connector-solutions/GBC04SGSN-M89/S1143E-04-ND/862387) | 804 | 1.30000 | 1.16400 | 1.16400 | 0.95820 | 0.75746 | 0.65023 | 2.60000 | 2.32800 | 2.32800 | 1.91640 | 1.51492 | 1.30046
54 | 1 | S1 | SWI | SMT | E-SWITCH | JS5208 (https://www.e-switch.com/product-catalog/navigation/product-lines/js5208-series-5-position-navigation-switch) | JOYSTICK | JOYSTICK | JOYSTICK | Switch, 5-way Navigation, SMD |  | Digikey | EG4561-ND (http://www.digikey.com/product-search/en?keywords=JS5208) | 4,436 | 3.03000 | 2.90600 | 2.54320 | 2.42200 | 2.05870 | 1.75595 | 3.03000 | 2.90600 | 2.54320 | 2.42200 | 2.05870 | 1.75595
55 | 2 | S2,S3 | SWI | SMT | E-SWITCH | TL3300DF160Q (http://www.e-switch.com/product/tabid/96/productid/187/sename/tl3300-series-smt-tact-switch/default.aspx) | BUTTON | BUTTON | BUTTON | Switch, Pushbutton, Tactile SMD |  | Digikey | EG4906CT-ND (http://search.digikey.com/scripts/DkSearch/dksus.dll?Detail&name=EG4906CT-ND) | 15,145 | 0.55000 | 0.52900 | 0.49920 | 0.43080 | 0.39160 | 0.33820 | 1.10000 | 1.05800 | 0.99840 | 0.86160 | 0.78320 | 0.67640
56 | 2 | S4,S5 | SWI | SMT | E-SWITCH | TL3330AF130QG (http://www.e-switch.com/product/tabid/96/productid/28/sename/tl3330-series-smt-right-angle-tactile-switch/default.aspx) | TACT-RA | TACT-RA | TACT-RA | Switch, Pushbutton, Tactile, Right Angle, SMD | Reset Switch | Digikey | EG4389CT-ND (http://www.digikey.com/product-detail/en/e-switch/TL3330AF260QG/EG4389CT-ND/1426859) | 16,667 | 0.47000 | 0.44800 | 0.42360 | 0.36540 | 0.31560 | 0.24915 | 0.94000 | 0.89600 | 0.84720 | 0.73080 | 0.63120 | 0.49830
57 | 1 | DS1 | ASY | THRU | NEWHAVEN DISPLAY | NHD-0420AZ-FL-YBW-33V3 (http://www.newhavendisplay.com/nhd0420azflybw33v3-p-5165.html) | LCD-4x20 | LCD-MODULE | LCD-MODULE | Display, LCD, transreflective, 4x40 lines, 5x8 characters, w/Backlight |  | Digikey | NHD-0420AZ-FL-YBW-33V3-ND (http://www.digikey.com/product-search/en?keywords=NHD-0420AZ-FL-YBW-33V3) | 135 | 17.95000 | 15.80000 | 14.90000 | 14.18000 | 12.91996 | 12.91996 | 17.95000 | 15.80000 | 14.90000 | 14.18000 | 12.91996 | 12.91996
101 | 1 | BT1 | BAT | NA | PANASONIC | CR2032 (http://industrial.panasonic.com/ww/products/batteries/primary-batteries/lithium-batteries/coin-type-lithium-batteries-cr-series/CR2032) | CR2032 | CR2032 | CR2032 | Battery, Coin Cell, Lithium, CR2032 size, 3V, 220mAh |  | Digikey | P189-ND (http://www.digikey.com/product-detail/en/panasonic-bsg/CR2032/P189-ND/31939) | 3,564,501 | 0.34000 | 0.31000 | 0.27580 | 0.24140 | 0.22068 | 0.20688 | 0.34000 | 0.31000 | 0.27580 | 0.24140 | 0.22068 | 0.20688
102 | 1 | A2 | ASY | NA | PANASONIC | RP-SDF02GDA1 (http://panasonic.net/avc/sdcard/industrial_sd/lineup.html#micro) | SDCARD | SDCARD | SDCARD | Memory Module, SD Card, 2GB capacity |  | Digikey | PCR232-ND (http://www.digikey.com/product-search/en/memory-cards-modules/memory-cards/1901091?k=SD+card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) | 1,217 | 43.04000 | 39.91700 | 37.54800 | 32.88600 | 31.75200 | 30.24000 | 43.04000 | 39.91700 | 37.54800 | 32.88600 | 31.75200 | 30.24000
103 |  | A1 | ASY | NA | TBD | TBD |  |  |  | Power Supply, Wall Wart, 110-240VAC in, 5VDC 1A out
104 |  | W1 | WAC | NA |  |  |  |  |  | Cable, USB, Type A plug to Micro B plug
105 |  | W2 | WAC | NA |  |  |  |  |  | Cable, Serial RS232 DCE, IDC10 to DE9F
106 |  | W3 | WAC | NA |  |  |  |  |  | Cable, Serial TTL,Mod-Yost Wafer-10 to Mod-Yost Wafer-10
107 |  | W4 | WAC | NA |  |  |  |  |  | Cable, Serial RS232 DTE / Canbus, IDC10 to DB9M
108 |  | W5P1 | WAC | NA |  |  |  |  |  | Cable, Serial RS422/485, Screw Terminal Block
109 |  | W6 | WAC | NA |  |  |  |  |  | Cable, Serial TTL, Mod-Yost Wafer-10 to Female Probes
110 |  | W7 | WAC | NA |  |  |  |  |  | Cable, Serial RS232 / UEXT, IDC-10 to IDC-10
111 |  | W8 | WAC | NA |  |  |  |  |  | Cable, Serial TTL, Mod-Yost Wafer-10 to FTDI Wafer-6
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

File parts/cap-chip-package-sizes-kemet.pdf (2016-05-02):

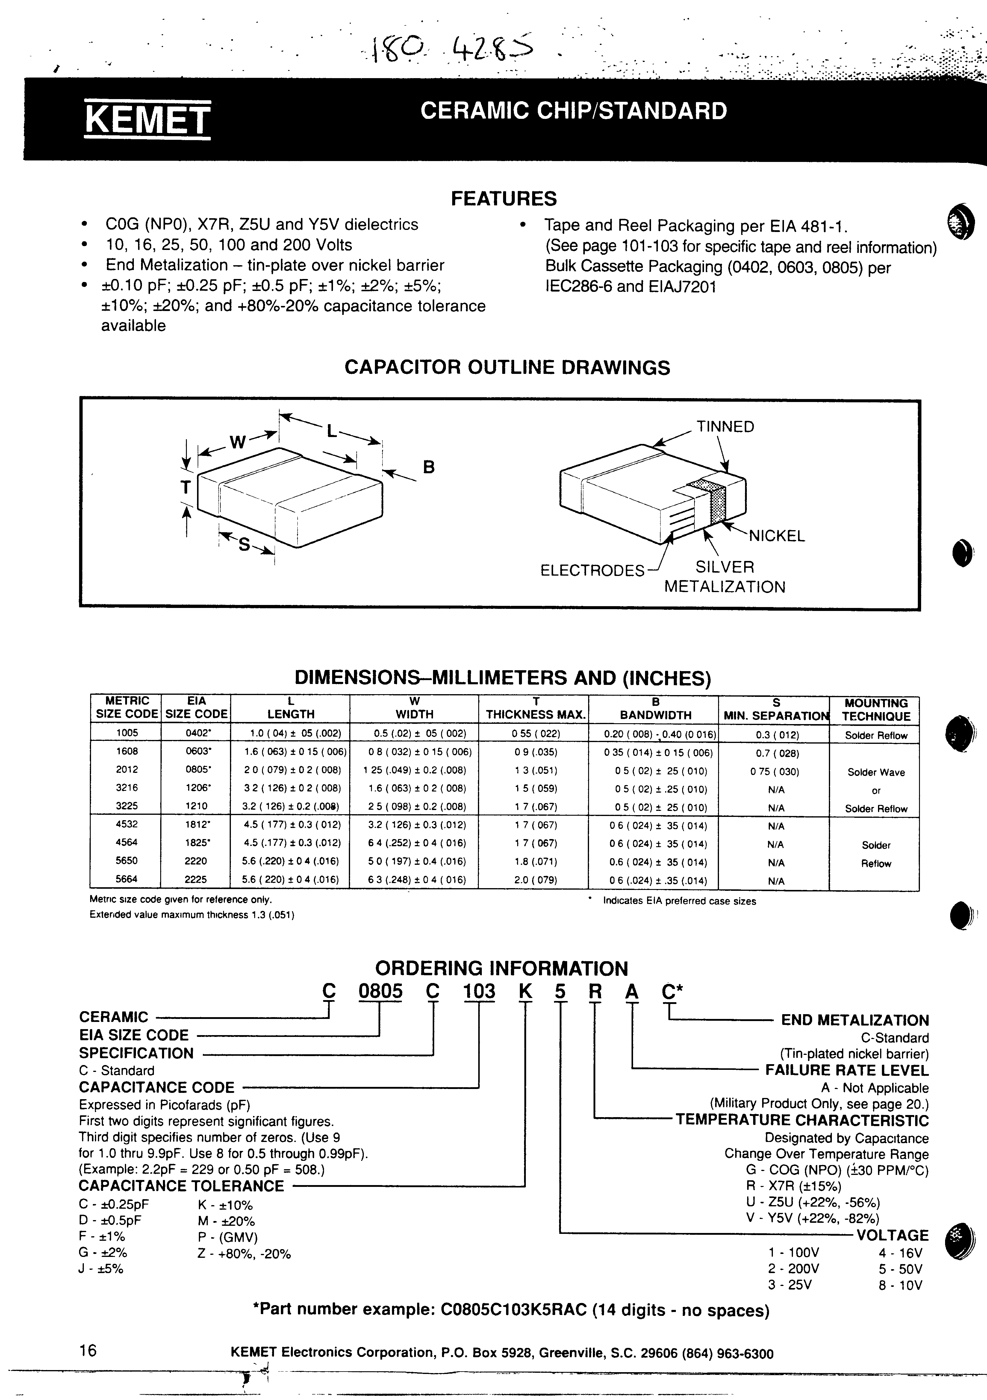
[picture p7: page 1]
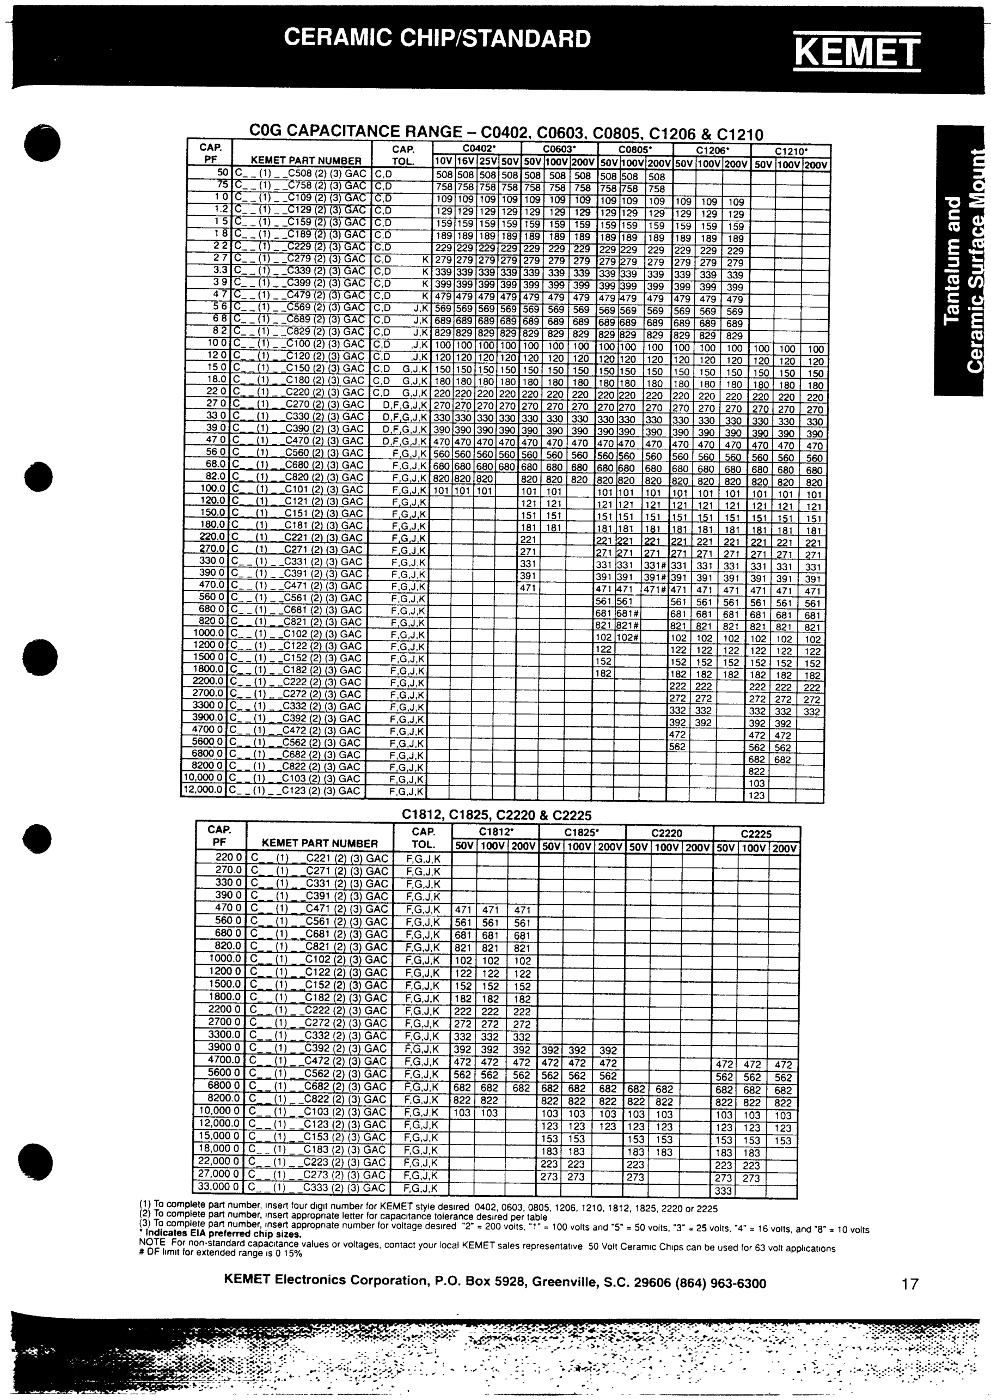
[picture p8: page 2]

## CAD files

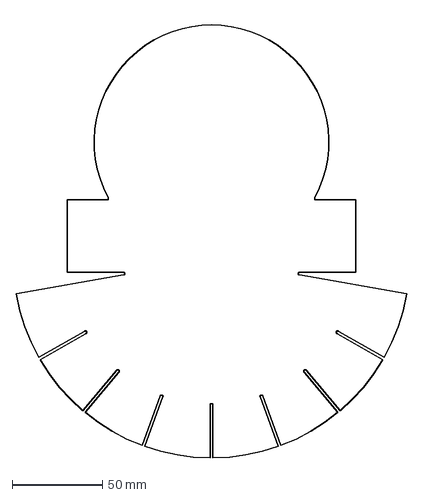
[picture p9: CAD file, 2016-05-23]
mech/pcb_squid-board-outline.dxf
216.7 x 244.9 mm

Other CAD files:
mech/pcb_squid_icon.dwg
mech/pcb_squid.dwg
mech/flat-things.dwg
mech/squid-connectors.dwg
mech/pcb_squid-board-outline.dwg

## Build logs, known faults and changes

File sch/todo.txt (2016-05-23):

Surface mount Type A USB connector
Check pull-ups on each serial port bus
Supply power from COM0 optionally
change PS/2 to a right-angle jack?

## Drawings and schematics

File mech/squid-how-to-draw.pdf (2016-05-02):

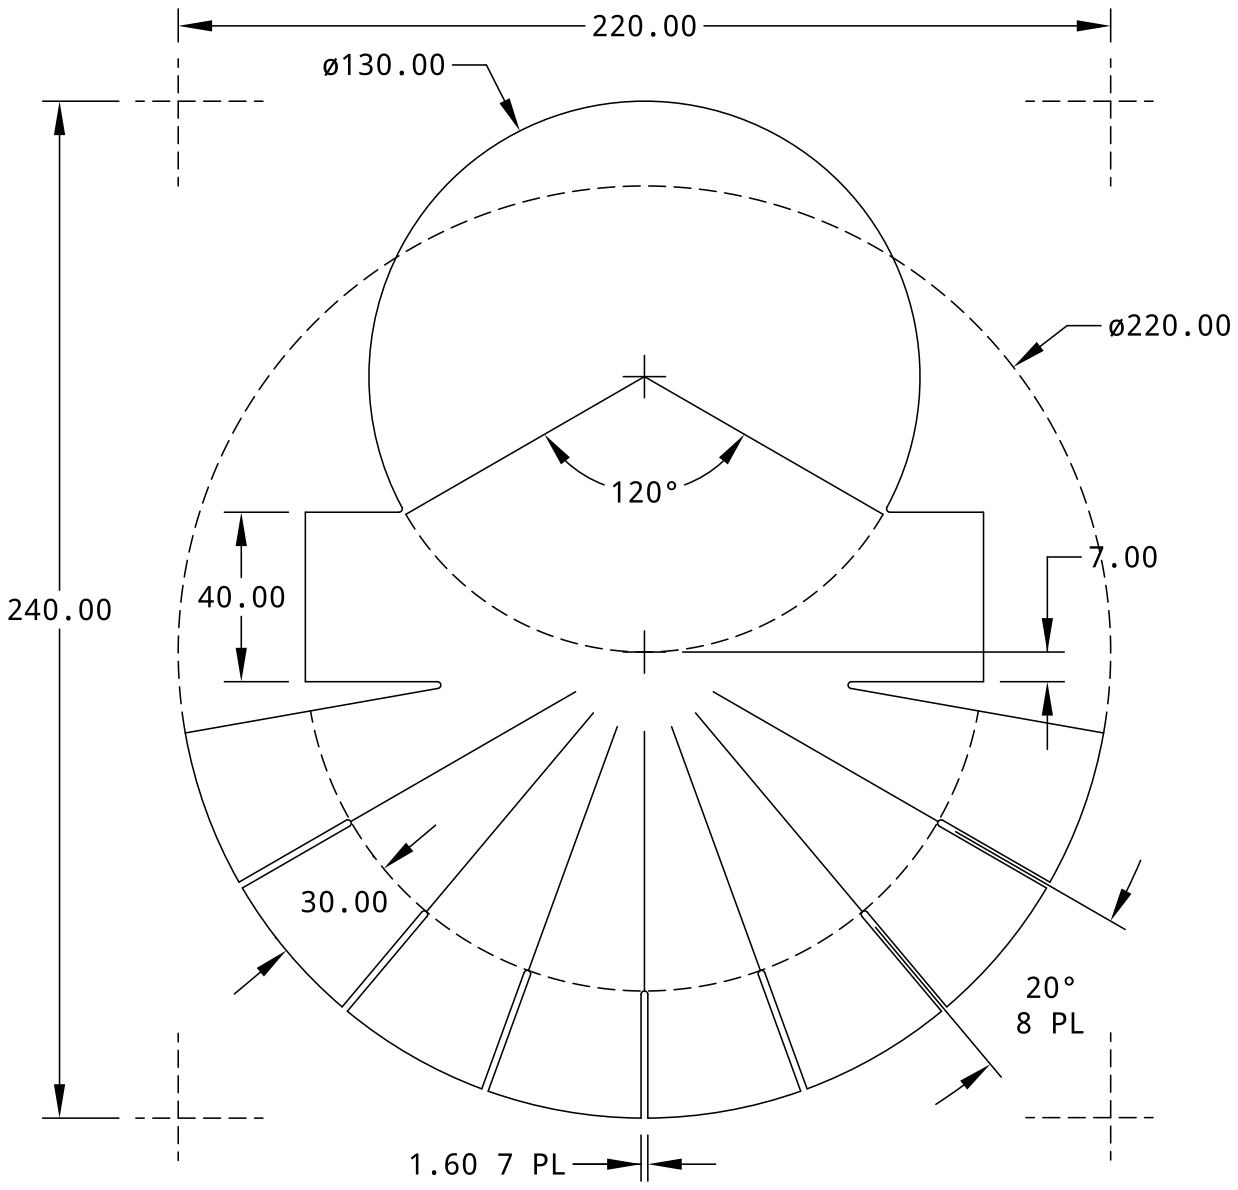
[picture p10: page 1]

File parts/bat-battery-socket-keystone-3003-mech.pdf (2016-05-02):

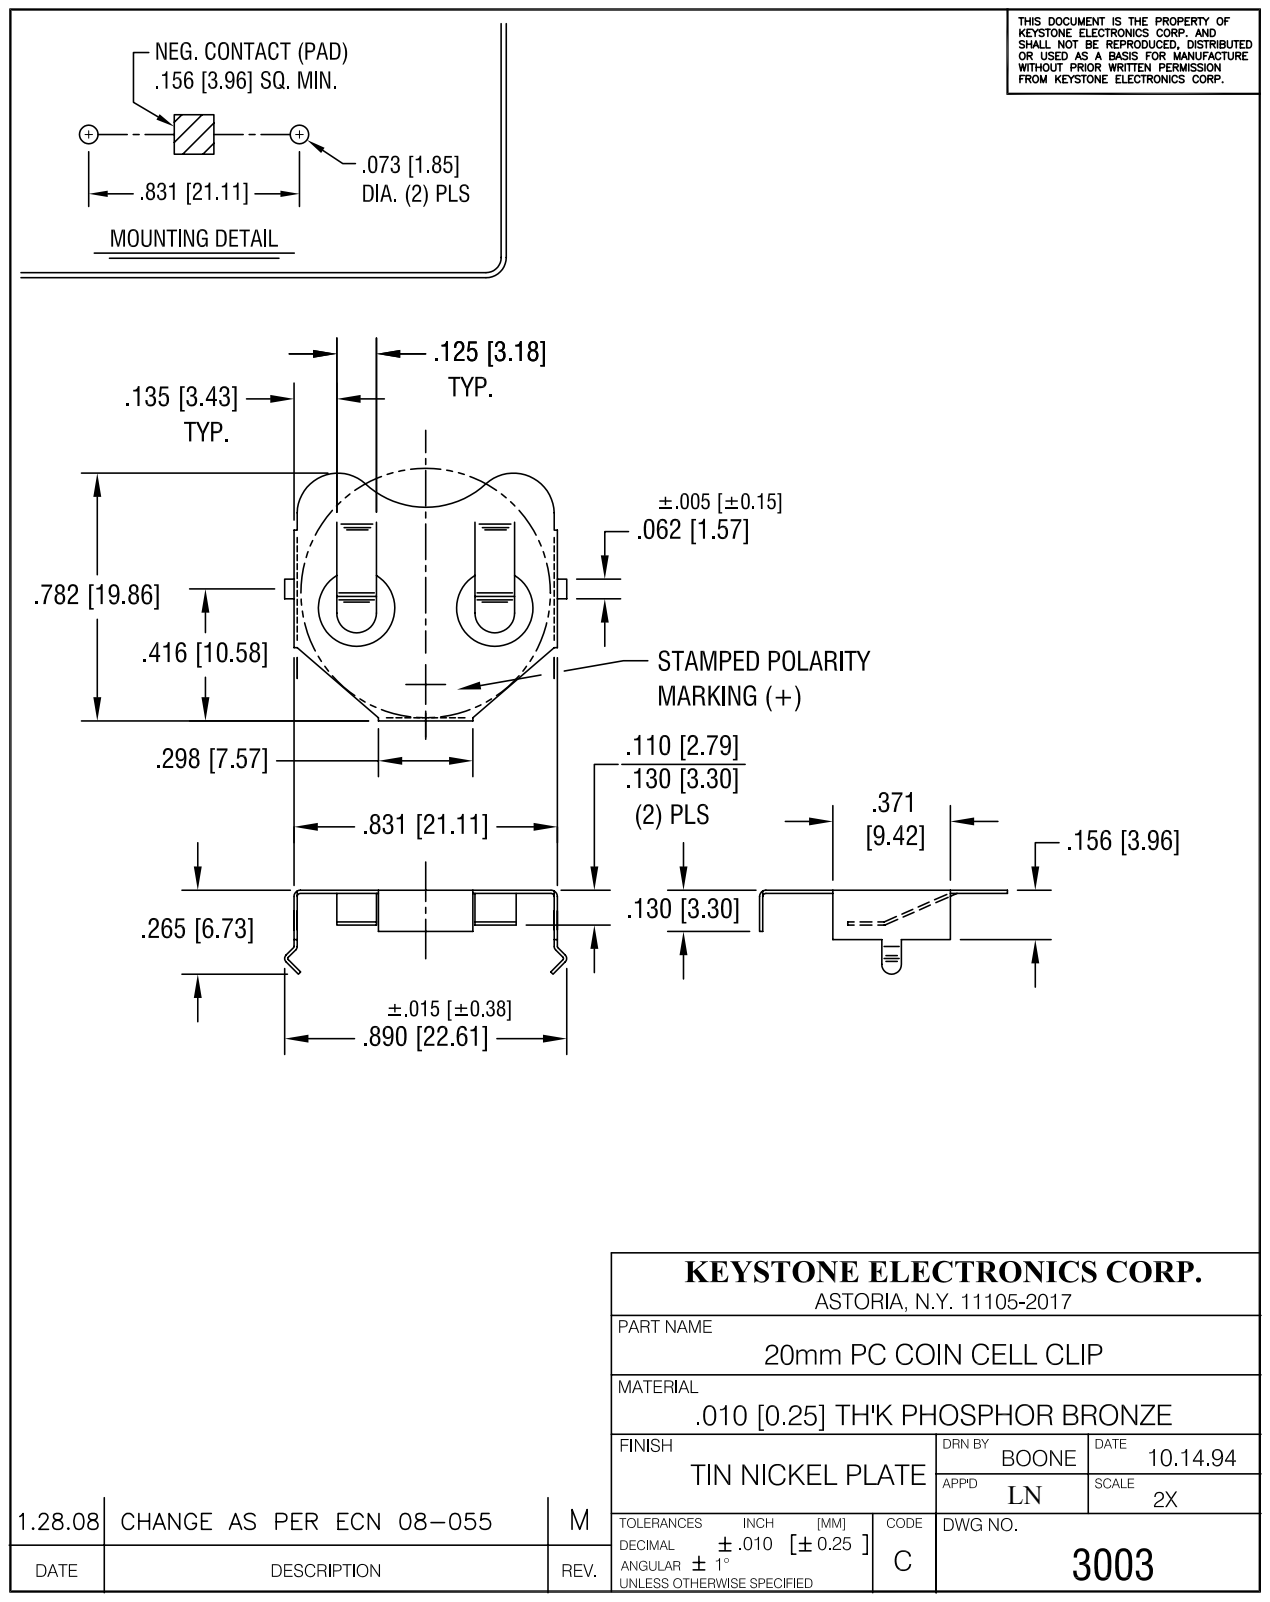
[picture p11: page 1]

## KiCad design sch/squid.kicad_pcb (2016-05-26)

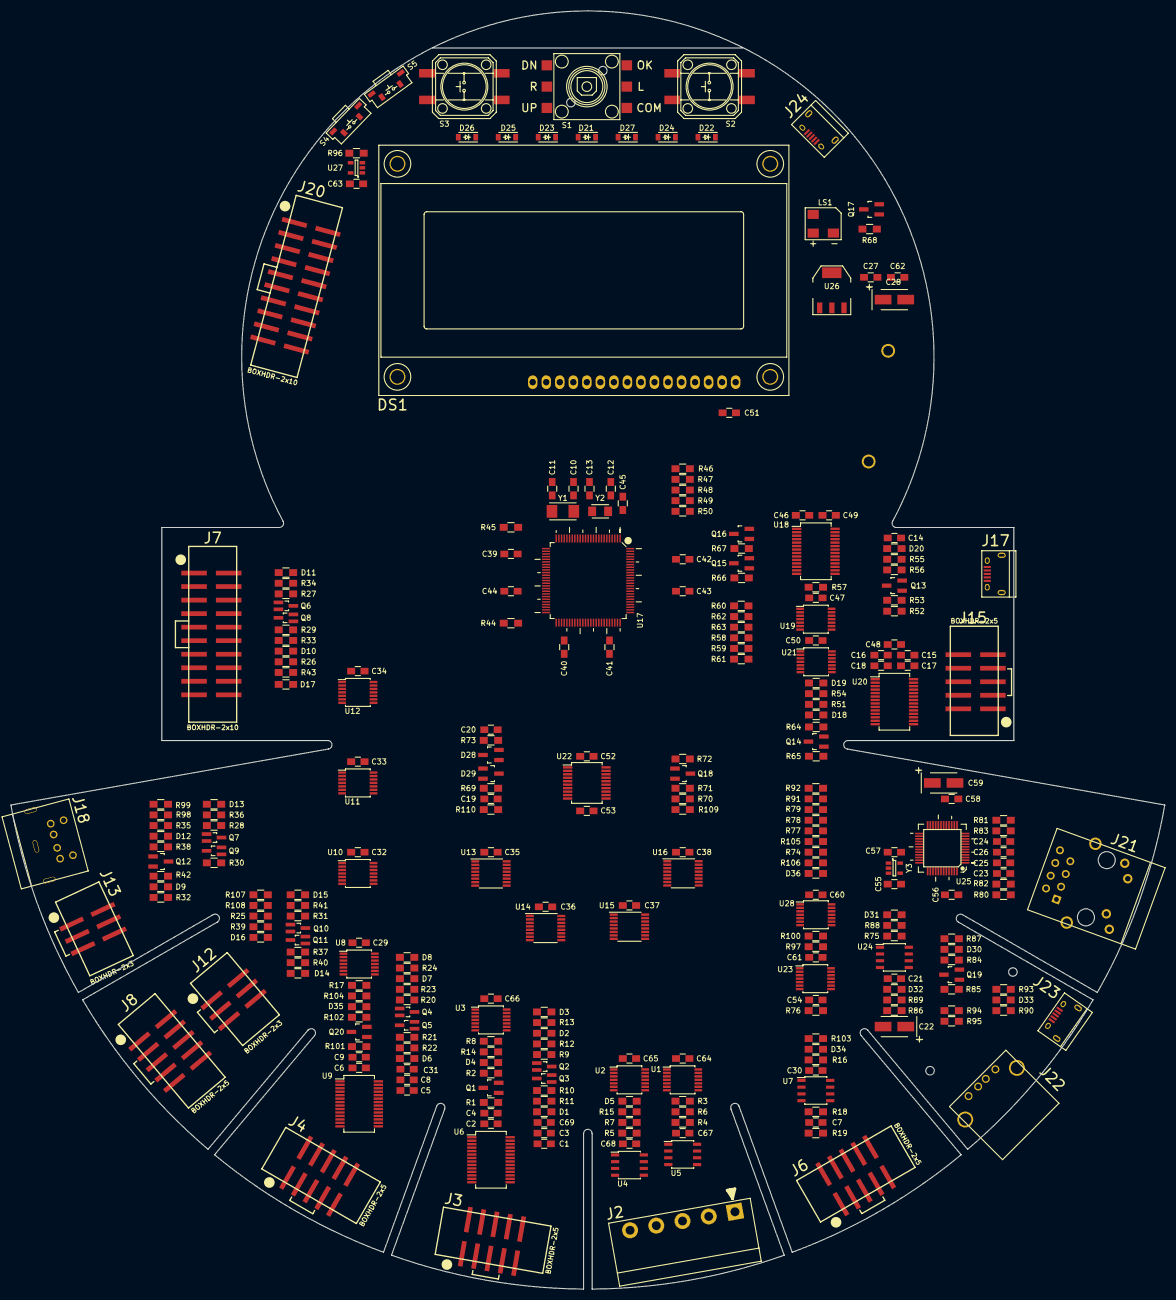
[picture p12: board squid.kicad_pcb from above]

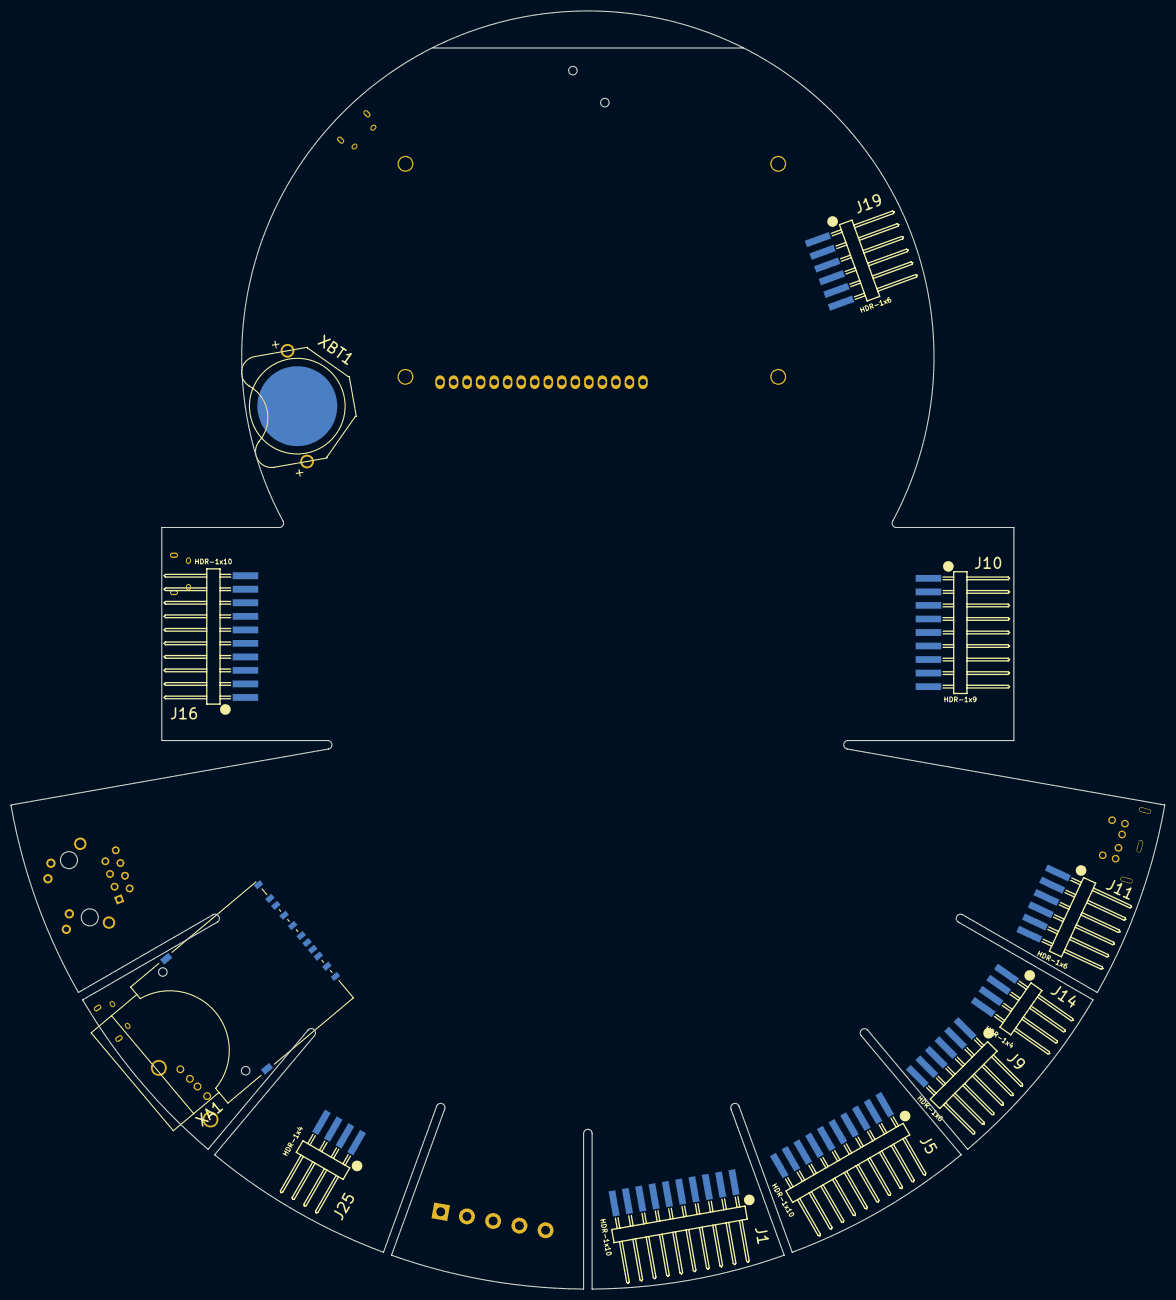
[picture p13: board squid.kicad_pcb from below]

Board: 2 copper layers, 216.7 x 240.0 mm, 300 parts (11 on the bottom side), 278 nets, no tracks yet.

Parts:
C1, C2, C3, C4, C5, C6, C8, C9, C14, C15, C16, C17, C18, C21, C23, C24, C25, C26, C29, C30, C31, C32, C33, C34, C35, C36, C37, C38, C40, C41, C42, C43, C44, C45, C46, C47, C48, C49, C50, C51, C52, C53, C54, C55, C56, C57, C58, C60, C61, C62, C63, C64, C65, C66, C67, C68, C69: 0.1uF; C_0805_HandSoldering
C7: 0.001uF; C_0805_HandSoldering
C10, C11, C12, C13: 18pF; C_0805_HandSoldering
C19, C20: 0.47uF; C_0805_HandSoldering
C22, C28, C59: 10uF; TantalC_SizeB_EIA-3528_HandSoldering
C27, C39: 1.0uF; C_0805_HandSoldering
D1, D2, D3, D4, D5, D6, D7, D8, D9, D10, D11, D12, D13, D14, D15, D16, D17, D18, D19, D20, D30, D31, D32, D33, D34, D35, D36: LED-GREEN; R_0805_HandSoldering
D21, D22, D23, D24, D25, D26, D27: 1N4148; SOD-123
D28, D29: BAT54; SOT-23_Handsoldering
DS1: LCD-4x20; NHD-0420AZ
J1, J5, J16: HDR-1x10; PHDR-RA-SMT-1x10
J2: TERM-BLOCK-5; term-block-5
J3, J4, J6, J8, J15: BOXHDR-2x5; SHDR-SMT-2x5
J7, J20: BOXHDR-2x10; SHDR-SMT-2x10
J9, J11, J19: HDR-1x6; PHDR-RA-SMT-1x6
J10: HDR-1x9; PHDR-RA-SMT-1x9
J12, J13: BOXHDR-2x3; SHDR-SMT-2x3
J14, J25: HDR-1x4; PHDR-RA-SMT-1x4
J17, J23, J24: USB-MICRO-B; USB_Micro-B
J18: MINIDIN6; MINIDIN-RA-THRU-6
J21: RJ45-MAGS; RJ45_TRANSFO_PULSE_A
J22: USB-TYPE-A; USB_A
LS1: BUZZER; BUZZER-CSS-0575A
Q1, Q12, Q13, Q14, Q15, Q16, Q17, Q20: 2N3904; SOT-23-BEC-HAND
Q2, Q3, Q4, Q5, Q6, Q7, Q8, Q9, Q10, Q11: DMG1013; SOT-323-GSD-HAND
Q18: 2N2222; SOT-23-BEC-HAND
Q19: 2N3906; SOT-23-BEC-HAND
R1, R38, R56, R65, R66, R67, R68, R72, R73, R84, R101: 1K; R_0805_HandSoldering
R2, R3, R4, R5, R6, R7, R8, R9, R10, R16, R17, R20, R21, R25, R26, R27, R28, R29, R30, R31, R37, R44, R45, R46, R47, R48, R49, R50, R53, R57, R58, R59, R60, R61, R62, R63, R64, R69, R70, R71, R74, R75, R76, R77, R78, R79, R96, R97, R100, R102, R105: 10K; R_0805_HandSoldering
R11, R12, R13, R14, R15, R22, R23, R24, R32, R33, R34, R35, R36, R39, R40, R41, R43, R51, R54, R55, R87, R88, R89, R90, R91, R92, R93, R103, R104, R106: 220; R_0805_HandSoldering
R18, R19: 60; R_0805_HandSoldering
R42: 20K; R_0805_HandSoldering
R52, R98, R99, R107, R108, R109, R110: 4.7K; R_0805_HandSoldering
R80, R81, R82, R83: 49.9; R_0805_HandSoldering
R85: 1.5K; R_0805_HandSoldering
R86: 100K; R_0805_HandSoldering
R94, R95: 15K; R_0805_HandSoldering
S1: SW_NAVI; SW_NAVI_JS5208
S2, S3: SW_PUSH; SW_PBUTTON_TL330
S4, S5: SW_PUSH_RA; SW_SPSW_TACT_RA
U1, U2, U3, U8, U10, U11, U12, U19, U21, U23, U28: 74HCT4066; TSSOP-14_4.4x5mm_Pitch0.65mm
U4, U5: SN75176B; SOIC-8_3.9x4.9mm_Pitch1.27mm
U6, U9, U20: MAX3241E; SSOP-28_5.3x10.2mm_Pitch0.65mm
U7: TJA1040; SOIC-8_3.9x4.9mm_Pitch1.27mm
U13, U14, U15, U16: 74HCT595; TSSOP-16_4.4x5mm_Pitch0.65mm
U17: LPC1769; LQFP-100_14x14mm_Pitch0.5mm
U18: FT232R; SSOP-28_5.3x10.2mm_Pitch0.65mm
U22: PIC16F1847; SSOP-20_5.3x7.2mm_Pitch0.65mm
U24: LM3526-L; SOIC-8_3.9x4.9mm_Pitch1.27mm
U25: DP83848; PQFP48-14x14mm
U26: MIC39100-3.3; SOT-223
U27: MCP1322; SOT-23-5
XA1: SD-SOCKET; SD_Card_Receptacle
XBT1: CR2032-SOCKET; SOCKET-SMT-CR2032-KEYSTONE-3003
Y1: 12MHz; Crystal_SMD_5032_2Pads
Y2: 32.768KHz; Crystal_SMD_3215_2Pads
Y3: 50MHz; SOT-23-5

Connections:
+3V3: C23.1, C24.1, C28.1, C31.2, C39.1, C40.1, C41.1, C42.1, C43.1, C44.1, C45.1, C46.2, C48.1, C52.1, C53.2, C55.1, C56.2, C57.2, C58.1, C59.1, C60.1, C61.1, C62.1, C63.1, C69.2, D2.2, D7.2, D11.2, D13.2, D15.2, D29.2, J20.1, J20.2, Q2.S, Q4.S, Q6.S, Q7.S, Q10.S, R2.1, R4.1, R9.1, R20.1, R27.1, R28.1, R31.1, R44.1, R45.1, R47.1, R48.1, R49.1, R50.1, R58.1, R59.1, R60.1, R61.1, R62.1, R63.1, R64.1, R69.1, R74.2, R77.2, R78.2, R79.2, R80.1, R81.1, R82.2, R83.2, R91.2, R92.2, R96.1, R97.1, R98.1, R99.1, R100.1, R102.1, R105.2, R109.1, R110.1, U6.26, U9.26, U17.10, U17.28, U17.42, U17.54, U17.71, U17.84, U17.96, U18.4, U20.26, U22.15, U22.16, U25.22, U25.32, U25.48, U26.3, U27.5, U28.14, XA1.4, Y3.4
+5V: C21.1, C27.1, C29.1, C30.2, C32.1, C33.1, C34.1, C35.1, C36.1, C37.1, C38.1, C47.1, C49.1, C50.1, C51.2, C54.1, C64.1, C65.1, C66.1, C67.1, C68.1, D1.2, D6.2, D10.2, D12.2, D14.2, D34.2, DS1.2, DS1.15, J6.8, J18.4, J24.1, J25.1, LS1.1, Q3.S, Q5.S, Q8.S, Q9.S, Q11.S, Q19.E, R10.1, R16.2, R21.1, R29.1, R30.1, R37.1, U1.14, U2.14, U3.14, U4.8, U5.8, U7.3, U8.14, U10.14, U11.14, U12.14, U13.16, U14.16, U15.16, U16.16, U18.20, U19.14, U21.14, U23.14, U24.7, U26.1
/CFG0: R55.2, R56.2, U13.15
/CFG1: R51.2, R65.1, U13.1, U20.22
/CFG2: R54.2, R57.1, U13.2, U19.5, U19.6, U19.12, U19.13, U21.5, U21.13
/CFG3: R1.1, R14.2, U6.22, U13.3
/CFG4: R3.1, R15.2, U1.5, U1.13, U2.6, U13.4
/CFG5: R8.1, R13.2, U2.5, U2.13, U3.5, U3.6, U3.12, U3.13, U13.5
/CFG6: Q3.G, R10.2, R11.2, U13.6
/CFG7: Q2.G, R9.2, R12.2, U13.7, U14.14
/CFG8: R101.1, R104.2, U9.22, U14.15
/CFG9: R17.1, R24.2, U8.5, U8.6, U8.12, U8.13, U14.1
/CFG10: Q5.G, R21.2, R22.2, U14.2
/CFG11: Q4.G, R20.2, R23.2, U14.3
/CFG12: R16.1, R103.2, U7.8, U14.4
/CFG13: R25.1, R39.2, U10.5, U10.6, U10.12, U10.13, U11.5, U11.13, U14.5
/CFG14: Q11.G, R37.2, R40.2, U14.6
/CFG15: Q10.G, R31.2, R41.2, U14.7, U15.14
/CFG16: R26.1, R43.2, U11.6, U11.12, U12.5, U12.6, U12.12, U12.13, U15.15
/CFG17: Q8.G, R29.2, R33.2, U15.1
/CFG18: Q6.G, R27.2, R34.2, U15.2
/CFG19: R32.2, U15.3
/CFG20: Q9.G, R30.2, R35.2, U15.4
/CFG21: Q7.G, R28.2, R36.2, U15.5
/CFG22: R75.2, R88.2, U15.6, U23.5, U23.13
/CFG23: R76.2, R87.2, U15.7, U16.14, U23.6, U23.12
/CFG24: R105.1, U16.15, U25.29
/CFG25: R74.1, R106.2, U16.1, U25.7, Y3.3
/CFG26: U16.2, U28.13
/CFG27: U16.3, U28.5
/COM0/COM0B_CTS: J15.6, U20.11
/COM0/COM0B_DSR: J15.2, U20.9
/COM0/COM0B_DTR: J15.7, U20.6
/COM0/COM0B_RTS: J15.4, U20.4
/COM0/COM0B_RXD: J15.3, U20.10
/COM0/COM0B_TXD: J15.5, U20.5
/COM0/COM0C_CTSL: J16.9, U21.3
/COM0/COM0C_DSR: J16.8, U21.1
/COM0/COM0C_DTR: J16.3, U19.3
/COM0/COM0C_RTSL: J16.2, U19.1
/COM0/COM0C_RXDL: J16.7, U19.10
/COM0/COM0C_TXD: J16.4, U19.8
/COM0/COM0_CTSL: R60.2, U17.81, U18.11, U20.12, U21.4
/COM0/COM0_DSR: R62.2, U17.59, U18.9, U20.14, U21.2
/COM0/COM0_DTR: R63.2, R67.2, U17.58, U18.2, U19.4, U20.17
/COM0/COM0_RTSL: R61.2, R66.2, U17.80, U18.3, U19.2, U20.19
/COM0/COM0_RXDL: R58.2, U17.98, U18.5, U19.11, U20.13
/COM0/COM0_TXDL: R59.2, U17.99, U18.1, U19.9, U20.18
/COM0/~RESET: C19.1, D28.1, J20.15, Q16.C, R45.2, R69.2, U17.17, U27.1
/COM1/COM1C_CTSL: J1.9, U3.4
/COM1/COM1C_DSR: J1.8, U3.2
/COM1/COM1C_DTR: J1.3, U2.4
/COM1/COM1C_RTSL: J1.2, U2.2
/COM1/COM1C_RXDL: J1.7, U3.11
/COM1/COM1C_TXD: J1.4, U3.9
/COM1/COM1_CTSL: U3.3, U6.16, U17.73
/COM1/COM1_DCDL: U6.19, U17.70
/COM1/COM1_DSRL: U3.1, U6.18, U17.69
/COM1/COM1_DTRL: U2.3, U2.9, U6.12, U17.68
/COM1/COM1_RIL: U6.15, U17.67
/COM1/COM1_RTSL: U1.2, U1.3, U2.1, U6.14, U17.66
/COM1/COM1_RXDL: U3.10, U5.1, U6.17, U17.74
/COM1/COM1_TXDL: R7.1, U3.8, U4.4, U5.4, U6.13, U17.75
/COM1/RXA: J2.3, U4.7
/COM1/RXB: J2.4, U4.6
/COM1/TXA: J2.1, U5.7
/COM1/TXB: J2.2, U5.6
/COM2-CAN/CAN_RD: U7.4, U17.46
/COM2-CAN/CAN_TD: U7.1, U17.47
/COM2-CAN/COM2B_CTSL: J5.9, U8.11
/COM2-CAN/COM2B_RTSL: J5.2, U8.1
/COM2-CAN/COM2B_RXDL: J5.7, U8.9
/COM2-CAN/COM2B_TXD: J5.4, U8.3
/COM2-CAN/COM2_CTSL: U8.10, U9.16, U17.57
/COM2-CAN/COM2_RTSL: U8.2, U9.14, U17.56
/COM2-CAN/COM2_RXDL: U8.8, U9.17, U17.64
/COM2-CAN/COM2_TXDL: U8.4, U9.13, U17.65
/COM3, PROG/COM3_MISO: J8.7, J12.1, U10.8, U10.9, U12.8, U17.61
/COM3, PROG/COM3_MOSI: J8.8, J12.4, U10.10, U10.11, U12.3, U17.60
/COM3, PROG/COM3_SCL: J8.5, J9.1, J9.5, R108.2, U10.1, U10.2, U12.1, U17.24
/COM3, PROG/COM3_SCLK: J8.9, J12.3, U11.1, U11.2, U11.10, U17.62
/COM3, PROG/COM3_SDA: J8.6, J9.2, J9.6, R107.2, U10.3, U10.4, U12.10, U17.25
/COM3, PROG/ISP_MISO: J13.1, U17.37
/COM3, PROG/ISP_MOSI: J11.4, J13.4, U17.38
/COM3, PROG/ISP_SCLK: J11.5, J13.3, U17.34
/COM3, PROG/ISP_VDD: J11.2, J13.2, Q7.D, Q9.D, R42.2
/COM3, PROG/ISP_VPP_~MCLR: J11.1, Q12.C, R42.1
/COM3, PROG/TCK: J7.9, J10.4, U11.11
/COM3, PROG/TDI: J7.5, J10.7, U12.4
/COM3, PROG/TDO: J7.13, J10.6, U12.9
/COM3, PROG/TMS: J7.7, J10.9, U11.9
/COM3, PROG/~COM3_SSEL: J8.10, J12.5, U11.3, U11.4, U11.8, U17.63
/COM3, PROG/~ISP_SSEL: J13.5, R38.1, U17.35
/COM3, PROG/~SRST: J7.15, U12.11
/COM3, PROG/~TRST: J7.3, U12.2
/CONFIG/SHIFT_CLK: R70.1, U13.11, U14.11, U15.11, U16.11
/CONFIG/SHIFT_IN: R71.1, U13.14
/CONFIG/SHIFT_LOAD: U13.12, U14.12, U15.12, U16.12, U22.19
/CONFIG/SHIFT_OUT: U16.9, U22.12
/CONFIG/~SHIFT_OE: U13.13, U14.13, U15.13, U16.13, U22.20
/CONFIG/~SHIFT_RESET: U13.10, U14.10, U15.10, U16.10, U22.17
/CPU/BOOT_ISP: Q15.C, R44.2, S5.1, U17.53, U22.18
/CPU/COM3_RXD: J8.3, J14.4, U17.6
/CPU/COM3_TXD: J8.4, J14.1, U17.7
/CPU/CONFIG_SCL: R109.2, U17.49, U22.11
/CPU/CONFIG_SDA: R110.2, U17.48, U22.8
/CPU/DISP_DB0: DS1.11, U17.32
/CPU/DISP_DB1: DS1.12, U17.44
/CPU/DISP_DB2: DS1.13, U17.45
/CPU/DISP_DB3: DS1.14, U17.20
/CPU/DISP_OP_ENA: DS1.6, U17.26
/CPU/DISP_REGSEL: DS1.4, U17.85
/CPU/DISP_RW: DS1.5, U17.82
/CPU/LAN_CRS: U17.92, U25.40
/CPU/LAN_MDC: U17.87, U25.31
/CPU/LAN_MDIO: U17.86, U25.30
/CPU/LAN_REF_CLK: U17.88, U25.34, Y3.5
/CPU/LAN_RXD0: U17.91, U25.43
/CPU/LAN_RXD1: U17.90, U25.44
/CPU/LAN_RXER: U17.89, U25.41
/CPU/LAN_TXD0: U17.95, U25.3
/CPU/LAN_TXD1: U17.94, U25.4
/CPU/LAN_TXEN: U17.93, U25.2
/CPU/MSD_MISO: U17.77, XA1.7
/CPU/MSD_MOSI: U17.76, XA1.2
/CPU/MSD_SCLK: U17.78, XA1.5
/CPU/PBCOL_SEN0: D26.1, D27.1, U17.9
/CPU/PBCOL_SEN1: D24.1, D25.1, U17.52
/CPU/PBCOL_SEN2: D22.1, D23.1, U17.51
/CPU/PBCOL_SEN3: D21.1, U17.50
/CPU/PBROW_DRV0: S1.1, U17.39
/CPU/PBROW_DRV1: S2.1, S3.1, U17.40
/CPU/RTCK: J20.11, U17.100
/CPU/TCK: J20.9, R46.1, U17.5
/CPU/TDI: J20.5, R49.2, U17.2
/CPU/TDO: J20.13, R50.2, U17.1
/CPU/TMS: J20.7, R48.2, U17.3
/CPU/USB_CONNECT: R84.2, U17.8
/CPU/USB_DM: U17.30, U23.1, U23.8
/CPU/USB_DP: U17.29, U23.3, U23.10
/CPU/USB_OVRCR: U17.43, U24.2
/CPU/USB_PWRD: C22.1, D32.2, J22.1, R86.2, U17.36, U24.8
/CPU/USB_VBUS: R93.1, U17.21
/CPU/VBATT: U17.19, XBT1.1
/CPU/~MSD_SENSE: R97.2, R100.2, U17.27, U28.2, U28.3
/CPU/~MSD_SSEL: U17.79, XA1.1
/CPU/~TRST: J20.3, R47.2, U17.4
/CPU/~USB_PPWR: U17.33, U24.1
/PIC-SQPROG/DISP_BACKL: DS1.16, Q18.C
/PIC-SQPROG/DISP_CONTR: C20.1, DS1.3, R73.1
/PIC-SQPROG/ICSP_CLK: J19.5, R70.2, U22.13
/PIC-SQPROG/ICSP_DAT: J19.4, R71.2, U22.14
/PIC-SQPROG/ICSP_MCLR: D28.2, J19.1, U22.4
/PIC-SQPROG/PS2_CLK: J18.5, R99.2, U22.7
/PIC-SQPROG/PS2_DAT: J18.1, R98.2, U22.9
/USB-LAN/USBD_DM: J23.2, U23.9
/USB-LAN/USBD_DP: J23.3, R85.1, U23.11
/USB-LAN/USBH_DM: J22.2, R94.2, U23.2
/USB-LAN/USBH_DP: J22.3, R95.2, U23.4
/USER/BUZZ: R68.2, U22.10
GND: C3.1, C4.1, C7.2, C8.1, C9.1, C10.2, C11.2, C12.2, C13.2, C14.1, C15.2, C16.2, C19.2, C20.2, C21.2, C22.2, C23.2, C24.2, C25.2, C26.2, C27.2, C28.2, C29.2, C30.1, C31.1, C32.2, C33.2, C34.2, C35.2, C36.2, C37.2, C38.2, C39.2, C40.2, C41.2, C42.2, C43.2, C44.2, C45.2, C46.1, C47.2, C48.2, C49.2, C50.2, C51.1, C52.2, C53.1, C54.2, C55.2, C56.1, C57.1, C58.2, C59.2, C60.2, C61.2, C62.2, C63.2, C64.2, C65.2, C66.2, C67.2, C68.2, C69.1, D3.1, D4.1, D5.1, D8.1, D9.1, D16.1, D17.1, D18.1, D19.1, D20.1, D30.1, D31.1, D35.1, D36.1, DS1.1, J1.5, J1.6, J2.5, J3.9, J4.9, J5.5, J5.6, J7.4, J7.6, J7.8, J7.10, J7.12, J7.14, J7.16, J7.18, J7.20, J8.2, J9.4, J10.2, J11.3, J12.6, J13.6, J14.2, J14.3, J15.9, J16.5, J16.6, J17.5, J17.6, J18.3, J18.7, J18.8, J18.9, J19.3, J20.4, J20.6, J20.8, J20.10, J20.12, J20.14, J20.16, J20.18, J20.20, J21.8, J21.13, J21.14, J22.4, J22.5, J23.5, J23.6, J24.5, J24.6, Q1.E, Q12.E, Q13.E, Q14.E, Q15.E, Q16.E, Q17.E, Q18.E, Q20.E, R3.2, R5.2, R6.2, R7.2, R8.2, R17.2, R25.2, R26.2, R46.2, R53.2, R57.2, R75.1, R76.1, R86.1, R89.1, R90.1, R94.1, R95.1, S4.1, S5.2, U1.7, U2.7, U3.7, U4.5, U5.5, U6.25, U7.2, U8.7, U9.25, U10.7, U11.7, U12.7, U13.8, U14.8, U15.8, U16.8, U17.11, U17.31, U17.41, U17.55, U17.72, U17.83, U17.97, U18.7, U18.18, U18.21, U18.25, U18.26, U19.7, U20.25, U21.7, U22.5, U22.6, U23.7, U24.6, U25.15, U25.19, U25.35, U25.36, U25.47, U26.2, U27.2, U28.7, XA1.3, XA1.6, XA1.12, XA1.13, XBT1.2, Y3.1
unnamed: C1.1, U6.28
unnamed: C1.2, U6.24
unnamed: C2.1, U6.1
unnamed: C2.2, U6.2
unnamed: C3.2, U6.27
unnamed: C4.2, U6.3
unnamed: C5.1, U9.28
unnamed: C5.2, U9.24
unnamed: C6.1, U9.1
unnamed: C6.2, U9.2
unnamed: C7.1, R18.1, R19.1, U7.5
unnamed: C8.2, U9.27
unnamed: C9.2, U9.3
unnamed: C10.1, U17.22, Y1.1
unnamed: C11.1, U17.23, Y1.2
unnamed: C12.1, U17.16, Y2.1
unnamed: C13.1, U17.18, Y2.2
unnamed: C14.2, U18.17
unnamed: C15.1, U20.27
unnamed: C16.1, U20.3
unnamed: C17.1, U20.24
unnamed: C17.2, U20.28
unnamed: C18.1, U20.2
unnamed: C18.2, U20.1
unnamed: C25.1, J21.4
unnamed: C26.1, J21.5
unnamed: D1.1, R11.1
unnamed: D2.1, R12.1
unnamed: D3.2, R13.1
unnamed: D4.2, R14.1
unnamed: D5.2, R15.1
unnamed: D6.1, R22.1
unnamed: D7.1, R23.1
unnamed: D8.2, R24.1
unnamed: D9.2, R32.1
unnamed: D10.1, R33.1
unnamed: D11.1, R34.1
unnamed: D12.1, R35.1
unnamed: D13.1, R36.1
unnamed: D14.1, R40.1
unnamed: D15.1, R41.1
unnamed: D16.2, R39.1
unnamed: D17.2, R43.1
unnamed: D18.2, R51.1
unnamed: D19.2, R54.1
unnamed: D20.2, R55.1
unnamed: D21.2, S1.4
unnamed: D22.2, S2.2
unnamed: D23.2, S1.5
unnamed: D24.2, S1.3
unnamed: D25.2, S1.6
unnamed: D26.2, S3.2
unnamed: D27.2, S1.2
unnamed: D29.1, J19.2
unnamed: D30.2, R87.1
unnamed: D31.2, R88.1
unnamed: D32.1, R89.2
unnamed: D33.1, R90.2
unnamed: D33.2, J23.1, R93.2
unnamed: D34.1, R103.1
unnamed: D35.2, R104.1
unnamed: D36.2, R106.1
unnamed: J1.1, J1.10, Q2.D, Q3.D
unnamed: J3.1, U6.4
unnamed: J3.2, U6.5
unnamed: J3.3, U6.6
unnamed: J3.4, U6.9
unnamed: J3.5, U6.10
unnamed: J3.6, U6.7
unnamed: J3.7, U6.11
unnamed: J3.8, U6.8
unnamed: J4.3, U9.6
unnamed: J4.4, U9.9
unnamed: J4.5, U9.10
unnamed: J4.6, U9.7
unnamed: J5.1, J5.10, Q4.D, Q5.D
unnamed: J7.1, J7.2, J10.1, Q6.D, Q8.D
unnamed: J8.1, J9.3, J12.2, Q10.D, Q11.D, R107.1, R108.1
unnamed: J17.1, R52.2
unnamed: J17.2, U18.16
unnamed: J17.3, U18.15
unnamed: J21.1, R80.2, U25.17
unnamed: J21.2, R82.1, U25.16
unnamed: J21.3, R83.1, U25.14
unnamed: J21.6, R81.2, U25.13
unnamed: J21.9, R91.1
unnamed: J21.10, R77.1, U25.28
unnamed: J21.11, R92.1
unnamed: J21.12, R79.1, U25.26
unnamed: J6.4, J25.2, R18.2, U7.7
unnamed: J6.3, J25.3, R19.2, U7.6
unnamed: J6.2, J6.5, J6.9, J25.4
unnamed: LS1.2, Q17.C
unnamed: Q1.B, R1.2
unnamed: Q1.C, R2.2, U6.23
unnamed: Q12.B, R38.2
unnamed: Q13.B, R56.1
unnamed: Q13.C, R52.1, R53.1, U18.19
unnamed: Q14.B, R65.2
unnamed: Q14.C, R64.2, U20.23
unnamed: Q15.B, R66.1
unnamed: Q16.B, R67.1
unnamed: Q17.B, R68.1
unnamed: Q18.B, R72.1
unnamed: Q19.B, R84.1
unnamed: Q19.C, R85.2
unnamed: Q20.B, R101.2
unnamed: Q20.C, R102.2, U9.23
unnamed: R4.2, U1.4, U5.2
unnamed: R5.1, U2.8, U4.3
unnamed: R6.1, U1.1, U5.3
unnamed: R72.2, U22.2
unnamed: R73.2, U22.3
unnamed: R78.1, U25.27
unnamed: R96.2, S4.2, U27.4
unnamed: U28.1, XA1.10
unnamed: U28.4, XA1.11

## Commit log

2016-05-02 Baseline release
    [pcb_squid.dwg, squid-bom.xlsx, squid-com0.sch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]
2016-05-23 Draft 1, PCB Preliminary Placement
    [flat-things.dwg, pcb_squid-board-outline.dwg, pcb_squid-board-outline.dxf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]
2016-05-26 parts placement, draft 2, straight alignment
    [squid-user.sch, squid.kicad_pcb]
